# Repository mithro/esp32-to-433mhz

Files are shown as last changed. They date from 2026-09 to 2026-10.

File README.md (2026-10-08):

# esp32-to-433mhz

> [!CAUTION]
> **AI in use, use at own risk.**

A small carrier board that turns an **ESP32-C3 SuperMini** and a cheap
**433 MHz radio board** into one 29&nbsp;x&nbsp;38 mm unit. It takes any of three
common 2x4-header radios in the same socket:

* the blue **Ebyte E07-M1101D** (CC1101, SMA jack),
* the green **D-Sun CC1101** board (same signals, different header order),
* the blue **SX1278 LoRa 433MHz v4.0** breakout (Ai-Thinker Ra-02, IPEX
  antenna).

Same ESP32 pins for every radio, one firmware pin map per board, and every
track on one copper layer so it can even be etched at home.

| With the E07-M1101D (CC1101) | With the Ra-02 breakout (SX1278) |
| --- | --- |
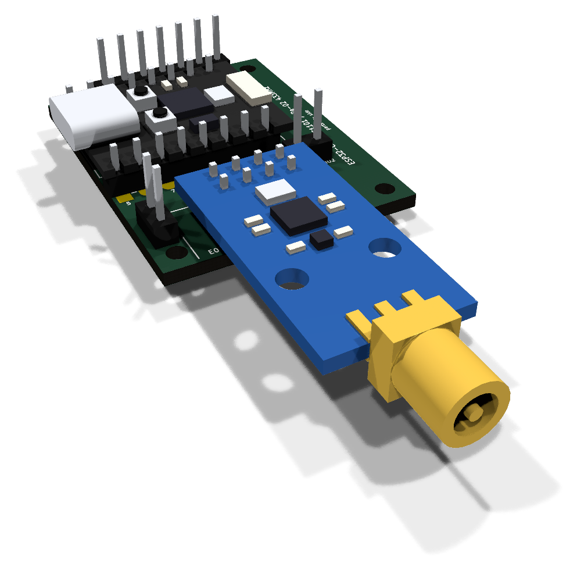
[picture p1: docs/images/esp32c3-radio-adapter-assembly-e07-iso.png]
Adapter with the E07-M1101D plugged in
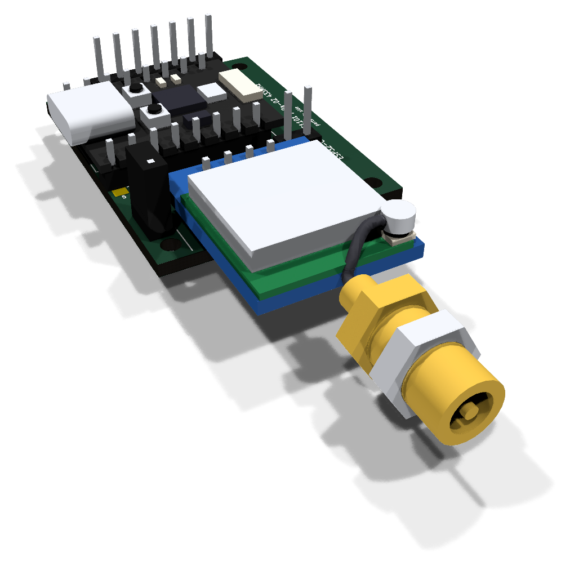
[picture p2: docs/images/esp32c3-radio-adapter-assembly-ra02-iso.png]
Adapter with the Ra-02 breakout and its U.FL-to-SMA pigtail
|  |  |

The KiCad 9 project is `hardware/esp32c3-radio-adapter`. Ready-to-upload
Gerber packages are attached to the
[latest release](https://github.com/mithro/esp32-to-433mhz/releases/latest).

Contents:

* [What you need](#what-you-need)
* [Getting the board made](#getting-the-board-made)
* [Assembling it](#assembling-it)
* [Pin map for firmware](#pin-map-for-firmware)
* [Jumper-wire version (no adapter needed)](#jumper-wire-version-no-adapter-needed)
* [Further reading](#further-reading)

## What you need

Everything is a stock AliExpress / eBay / Amazon part costing a few
dollars. The "Buy" links are AliExpress searches for the listing names;
the "Details" links go to that board's page in this repository, with its
dimensions, pinout and sources.

### Boards

| Board | Buy | How to recognise it | Details |
| --- | --- | --- | --- |
| **ESP32-C3 SuperMini** | [ESP32-C3 SuperMini](https://www.aliexpress.com/w/wholesale-esp32-c3-supermini.html) | 18&nbsp;x&nbsp;22.5 mm, USB-C, 8 castellated pins per side, ceramic antenna at the far end from the USB-C. Usually ships with two 1x8 pin headers. | [dimensions and pinout](hardware/parts/esp32-c3-supermini/) |
| **One radio board**, any of: | | | |
| Ebyte E07-M1101D-SMA (CC1101) | [E07-M1101D](https://www.aliexpress.com/w/wholesale-e07-m1101d.html), also sold as "TENSTAR CC1101 433MHz wireless module" | Blue, 15&nbsp;x&nbsp;30 mm, 2x4 header at one end, SMA jack at the other, PCB marked "E07-M1101D V2.0". Take the -SMA, not the -TH spring-antenna variant that search leads with. Needs a 433 MHz SMA antenna (often included). | [Ebyte product page](https://www.cdebyte.com/products/E07-M1101D-SMA), [part page](hardware/parts/cc1101-e07-m1101d/) |
| D-Sun CC1101 (green) | [CC1101 433MHz module](https://www.aliexpress.com/w/wholesale-cc1101-433mhz-module.html), pick the green one | Green, 14.4&nbsp;x&nbsp;30 mm, silk "433MHz D-Sun CC1101", 2x4 header, SMA jack. Needs a 433 MHz SMA antenna. | [part page](hardware/parts/cc1101-dsun/) |
| SX1278 Ra-02 breakout | [SX1278 LoRa 433MHz Ra-02](https://www.aliexpress.com/w/wholesale-sx1278-lora-433mhz-ra-02.html) | Blue 17.5&nbsp;x&nbsp;22.5 mm carrier with the Ai-Thinker Ra-02 can on top, 2x4 header underneath, silk "SX1278 LoRa 433MHz v4.0". Needs a [U.FL (IPEX) to SMA pigtail](https://www.aliexpress.com/w/wholesale-ipex-to-sma-pigtail.html) plus a 433 MHz SMA antenna. | [Ai-Thinker Ra-02 page](https://docs.ai-thinker.com/en/Ra-02/index.html), [part page](hardware/parts/sx1278-ra02-breakout/) |

Get a [433 MHz SMA antenna](https://www.aliexpress.com/w/wholesale-433mhz-sma-antenna.html),
not the 868/915 MHz one many listings bundle with the same radio.

### Headers and small parts

| Ref | Part | Qty | Notes |
| --- | --- | --- | --- |
| J1, J2 | 1x8 male pin header, 2.54 mm | 2 | For the SuperMini; usually in the bag with it. Or solder the SuperMini flat by its castellations and skip these. |
| J3 | 2x4 male pin header, 2.54 mm | 1 | The radio board's own header solders straight into the adapter. Fit a 2x4 female header instead if you want the radio removable. |
| [J4](docs/design-notes.md#expansion-header-j4) | 1x7 male pin header, 2.54 mm | 1 | Expansion header: 3V3 and the spare GPIOs. Optional. |
| [J5](docs/design-notes.md#the-dio2-fly-wire-header) | 1x2 male pin header, 2.54 mm | 1 | DIO2 fly-wire header. Only needed for raw OOK on the SX1278. |
| [JP1](docs/design-notes.md#radio-type-strap-jp1-r1) | 1x2 male pin header + jumper cap, 2.54 mm | 1 | Radio-type strap. Jumper fitted for the Ra-02, open for a CC1101. |
| R1 | 0805 0 ohm resistor | 0 or 1 | Permanent alternative to the JP1 jumper (Ra-02 only). |
| R2, R3, R4 | 0805 4.7 kOhm resistors | 0 | Do-not-populate pull-ups on the boot straps: GPIO8 and GPIO2 (on J4) and GPIO9 (unused). Only if something you add holds one of them low at boot. |
| | M2 screws or standoffs | 4 | The corner holes are 2.2 mm. |
| | Thin insulated wire, 30 to 50 mm | 1 | The DIO2 fly wire (Ra-02 only): a strand of wire-wrap or enamelled wire. |

A strip of 40-pin "breakaway" male header covers J1, J2, J4, J5 and JP1.

## Getting the board made

1. Download `esp32c3-radio-adapter-<version>-jlcpcb.zip` or
   `...-nextpcb.zip` from the
   [latest release](https://github.com/mithro/esp32-to-433mhz/releases/latest).
   Each zip is a complete Gerber + drill package for that fab, with a
   `README.txt` of the ordering options.
2. Upload the zip to [JLCPCB](https://jlcpcb.com) or
   [NextPCB](https://www.nextpcb.com) as a new PCB order.
3. Order with these options (all fab defaults, no special processes):

| Option | Value |
| --- | --- |
| Size | 29.0&nbsp;x&nbsp;38.0 mm |
| Layers | 2 |
| Thickness | 1.6 mm FR-4 |
| Copper | 1 oz |
| Finish | ENIG preferred, HASL fine |
| Solder mask / silk | any colour, silkscreen both sides |
| Castellated holes | not needed |

The packages are rebuilt by CI on every push to `main` and carry the
`git describe` version in their name; the same string is printed in the
board's title block.

**Etching it yourself.** Every track is on the bottom copper; the top has
only pads and a ground pour. So the bottom layer alone works as a
single-sided board, with two limits: the SuperMini must go on with pin
headers (laid flat it would sit on the copper side, where its pin rows
come out mirrored), and R1 sits on the copper side. Use the `.GBL`,
`.GBO` and `.DRL` files from the package.

## Assembling it

1. **Radio-type strap first.** For the Ra-02 breakout, fit JP1 and put a
   jumper on it (or solder a 0 ohm resistor in R1 on the bottom). For
   either CC1101 board, leave JP1 empty or open.
2. **SuperMini.** It lies on its side along the left edge, USB-C hanging
   off the board; the silk shows the outline and pin names. Either solder
   its two 1x8 headers through the 1.0 mm holes (long pins down through
   the adapter, the plastic body between the two boards), or lay it flat
   on the top side and solder the castellations to the extended pads.
3. **J4, J5.** Optional; solder them from the top so the pins stand up.
   The silk under J4 names the pins the way the SuperMini does; J5's pins
   are "21" and "20 DIO2".
4. **Radio board.** It plugs in component side up, hanging off the bottom
   edge with its antenna connector pointing away from the adapter. Pin 1
   (GND) is the square pad at the right of the outer row. Solder its
   header pins into the 2x4 holes, or into a female socket fitted there.
5. **DIO2 fly wire (Ra-02, raw OOK only).** Run a wire from the
   breakout's DIO2 land to J5 pin 2 (GPIO20). DIO2 is not on the 2x4
   header: it is the Ra-02 module's pin 7, whose land sticks 0.8 mm out
   past the module's edge on the right-hand side, about 9 mm down from the
   header edge. The pinout diagram below marks it, and
   [Adding the DIO2 wire](hardware/parts/sx1278-ra02-breakout/dio2-wire.md)
   shows the radio end and how to check it landed.
6. **Antenna.** Screw it on the E07 or D-Sun's SMA jack; for the Ra-02,
   clip the pigtail's U.FL plug onto the module and screw the antenna on
   the pigtail. The DIO2 wire and the pigtail both want strain relief:
   a dab of hot glue over the wire's solder joint is enough.

| Top | Bottom (all the tracks) |
| --- | --- |
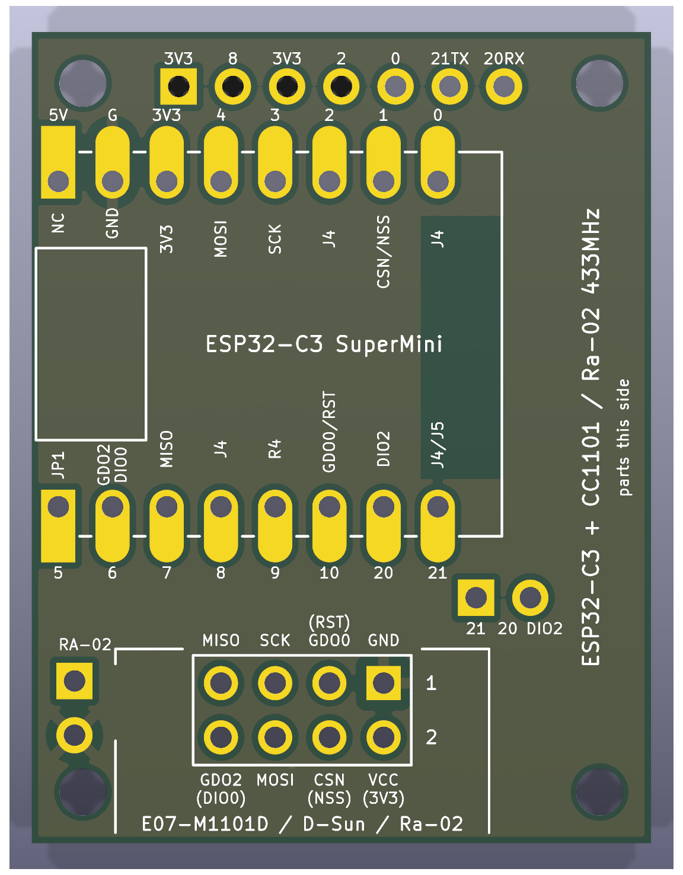
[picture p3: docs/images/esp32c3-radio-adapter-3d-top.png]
3D render of the top side
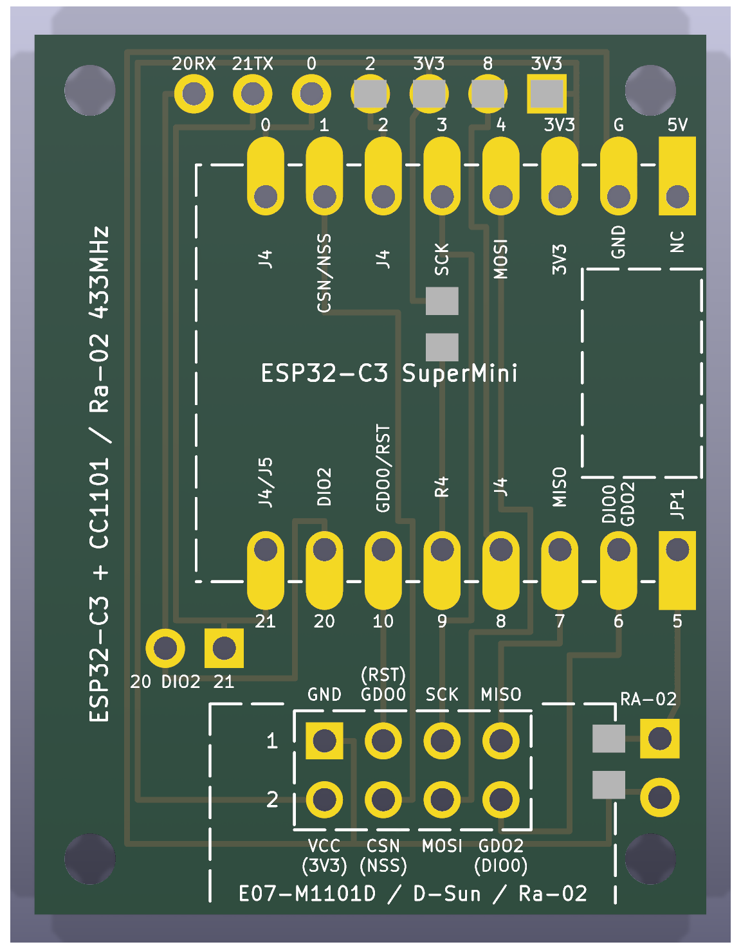
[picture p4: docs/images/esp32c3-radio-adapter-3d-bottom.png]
3D render of the bottom side
|  |  |

The silkscreen outlines the two mechanical keep-outs, the footprints of the
SuperMini and of the plugged-in radio board. J5 sits in the band between
them and is the only thing that fits there.

## Pin map for firmware

The socket's eight positions go to fixed GPIOs. Which signal each carries
depends on the radio, so firmware needs one pin map per board:

| Socket position | ESP32-C3 GPIO | E07-M1101D (blue CC1101) | D-Sun (green CC1101) | Ra-02 breakout (SX1278) |
| --- | --- | --- | --- | --- |
| 1 | GND | GND | GND | GND |
| 2 | 3V3 | VCC | VCC | 3V3 |
| 3 | GPIO10 | GDO0 (radio out) | MOSI | RST (radio in) |
| 4 | GPIO1 | CSN | SCK | NSS |
| 5 | GPIO3 | SCK | MISO (radio out) | SCK |
| 6 | GPIO4 | MOSI | GDO2 (radio out) | MOSI |
| 7 | GPIO7 | MISO (radio out) | GDO0 (radio out) | MISO (radio out) |
| 8 | GPIO6 | GDO2 (radio out) | CSN | DIO0 (radio out) |
| J5 pin 2 | GPIO20 | | | DIO2/DATA (fly wire) |
| JP1 / R1 | GPIO5 | open | open | strapped to GND |

The same maps, signal first:

| Signal | E07-M1101D | D-Sun | Ra-02 |
| --- | --- | --- | --- |
| MOSI | GPIO4 | GPIO10 | GPIO4 |
| MISO | GPIO7 | GPIO3 | GPIO7 |
| SCK | GPIO3 | GPIO1 | GPIO3 |
| CSN / NSS | GPIO1 | GPIO6 | GPIO1 |
| GDO0 / DIO0 | GPIO10 | GPIO7 | GPIO6 |
| GDO2 | GPIO6 | GPIO4 | |
| RST | | | GPIO10 |
| DIO2/DATA | | | GPIO20 |

**Telling the boards apart.** GPIO5 is the radio-type strap. Read it with
the internal pull-up enabled: low means the Ra-02 (jumper fitted), high
means a CC1101 board. The three-state read that also covers the SX1278
module adapter is in the
[design notes](docs/design-notes.md#radio-type-strap-jp1-r1). The two
CC1101 boards are told apart without driving anything: an unconfigured CC1101 clocks about 135 kHz out of GDO0, so
whichever of GPIO10 (blue board) and GPIO7 (green board) is toggling at
power-up names the board. In the jumper-wire build the strap goes to GPIO0
instead of GND, so drive GPIO0 low as an output before reading GPIO5.

**Why DIO2 matters on the SX1278.** In its continuous mode the raw
demodulated bitstream is available only on the DIO2/DATA pin. Packet mode
carries only what the packet handler can frame, which suits Fineoffset
weather stations but not the OOK remotes this node exists to hear and key.
The Ra-02 breakout leaves DIO2 unconnected, hence the fly wire to GPIO20.

**Never put a radio pin on GPIO2, GPIO8 or GPIO9.** They are ESP32-C3 boot
straps; a radio pin's capacitance makes the strap rise too slowly at reset
and the chip drops into USB download mode instead of running. This was
measured on the bench and later confirmed over JTAG -- on an affected board
the GPIO_STRAP_REG latch reads the download pattern even though the live
GPIO9 reads high -- and is not fixable in software, which is why the socket
uses GPIO1 rather than GPIO9.

## Jumper-wire version (no adapter needed)

The same hook-up with Dupont jumper wires, so the firmware pin map is
identical and you can test everything before ordering boards. Plug the
female-to-female wires onto the SuperMini's headers and the radio board's
2x4 header. Both boards are drawn from the back, pins towards you.

| Wire | SuperMini pin | E07-M1101D | D-Sun | Ra-02 |
| --- | --- | --- | --- | --- |
| brown | G | GND | GND | GND |
| red | 3V3 | VCC | VCC | 3V3 |
| grey | GPIO10 | GDO0 | MOSI | RST |
| purple | GPIO1 | CSN | SCK | NSS |
| blue | GPIO3 | SCK | MISO | SCK |
| white | GPIO4 | MOSI | GDO2 | MOSI |
| green | GPIO7 | MISO | GDO0 | MISO |
| yellow | GPIO6 | GDO2 | CSN | DIO0 |
| orange | GPIO5 | not fitted | not fitted | to the SuperMini's GPIO0 (radio-type strap) |
| black | GPIO20 | | | DIO2, soldered to the module's pin-7 land |

Jumper wires from the SuperMini to the blue CC1101 E07-M1101D board

Jumper wires from the SuperMini to the green D-Sun CC1101 board

Jumper wires from the SuperMini to the Ra-02 breakout

The Ra-02's orange strap wire goes to GPIO0 rather than GND because the
SuperMini's only GND pin is taken by the brown wire; the firmware drives
GPIO0 low while it reads the strap. The black DIO2 wire has no header pin
at the radio end: solder it to the module's pin-7 castellation or the land
just outside it, on the face away from the header pins. The header
pinouts, with the DIO2 land marked on both faces:

Header pinouts of the radio boards, front and back

## Printing a case

A two-part case that fits the adapter with either radio is in
`hardware/case/` as STL files. Every
[release](https://github.com/mithro/esp32-to-433mhz/releases/latest)
carries it as `esp32c3-radio-adapter-case-<version>.zip`, plus the two
`.stl` files loose for dropping straight into a slicer. The zip holds the
STL files in print orientation, the case's STEP models, and a README.txt
with the parts' sizes, home FDM print settings and how to order them from
JLCPCB's 3D-printing service.
In the pictures and the notes below, the **front** is the antenna end,
the **back** the SuperMini end with the pry notch on the seam, and the
**left** wall the one with the USB-C window. The top half is the darker
shade.

Closed, with the E07-M1101D inside (its SMA jack through the front wall):

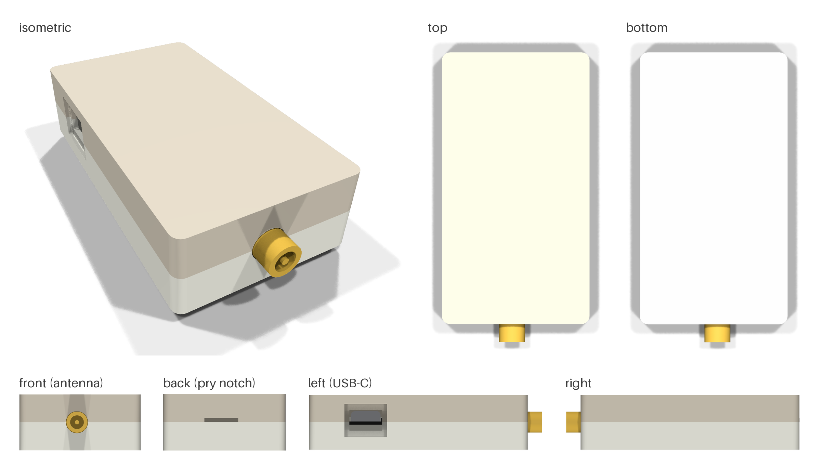
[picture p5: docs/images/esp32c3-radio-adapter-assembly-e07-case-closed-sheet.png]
The closed case with the E07-M1101D: isometric, top, bottom, front (antenna), back (pry notch), left (USB-C) and right views


Open, the adapter pressed onto the pegs in the bottom half, with the Ra-02
breakout and its U.FL-to-SMA pigtail in the socket (the drawn pigtail runs
straight to the bulkhead; a real one is longer, with the excess lying
beside the breakout):

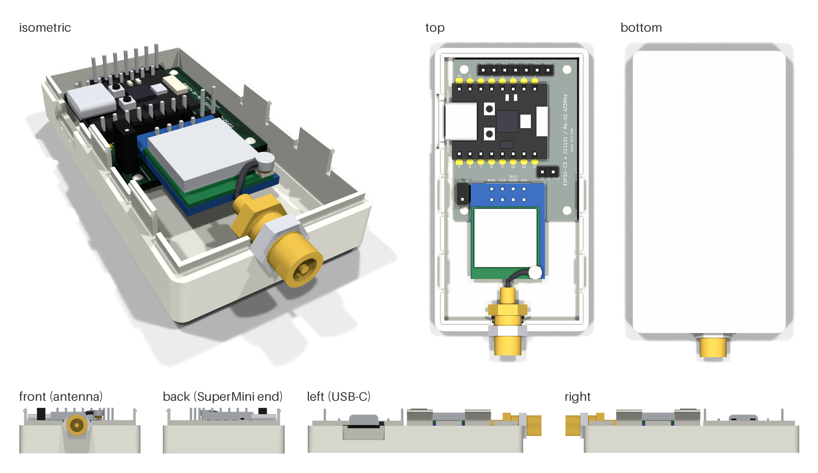
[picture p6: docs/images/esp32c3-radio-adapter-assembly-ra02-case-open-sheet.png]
The bottom half of the case with the adapter and the Ra-02 breakout: isometric, top, bottom, front (antenna), back (SuperMini end), left (USB-C) and right views


The halves on their own, and the slotted top:

| Bottom half: pegs, lip and the four snap tabs | Top half from below: bosses, grooved skirt, USB-C window, antenna hole | The slotted top half closed over the E07 |
| --- | --- | --- |
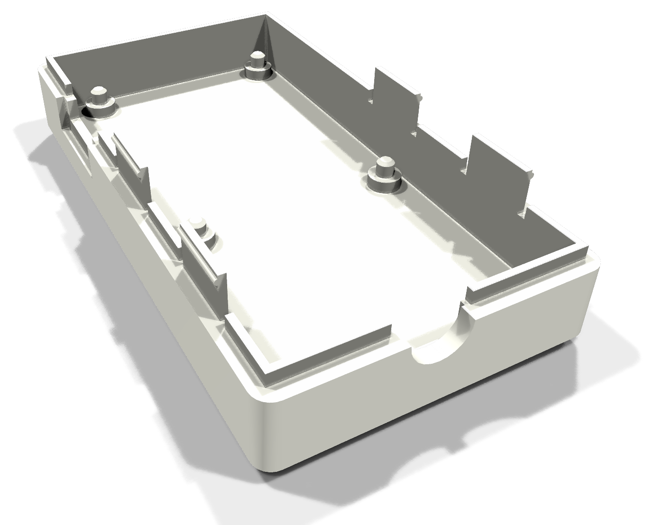
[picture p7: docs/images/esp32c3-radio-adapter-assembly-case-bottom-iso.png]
The empty bottom half from above: the four pegged standoffs, the lip round the rim and the four snap tabs with their bumps
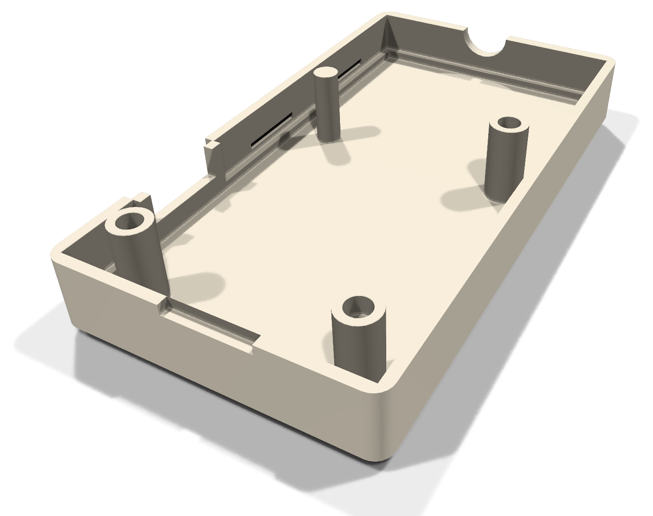
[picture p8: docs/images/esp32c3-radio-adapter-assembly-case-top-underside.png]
The top half turned over: three bored bosses and one solid one, the rebated skirt with its four grooves, the USB-C window and the antenna hole with its square pocket
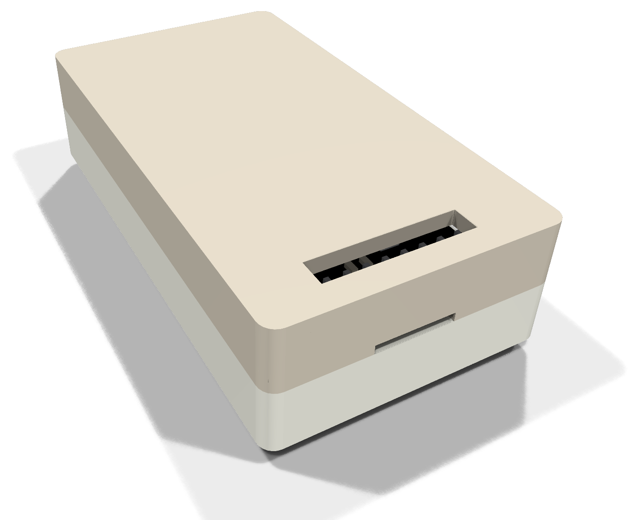
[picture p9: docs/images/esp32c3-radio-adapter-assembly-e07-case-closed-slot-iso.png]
The closed case with the slotted top half: J4's pins reach up through the slot in the ceiling
|  |  |  |

The same views with the other radio (the Ra-02 closed, the E07-M1101D
open) and the exploded views are in
[3D models and case design](docs/3d-models.md#the-printed-case).

* Two halves that snap together: `esp32c3-radio-adapter-case-bottom.stl`
  and `esp32c3-radio-adapter-case-top.stl`, each printed open side up. No
  supports, no screws; 2.2 mm walls; 36.2&nbsp;x&nbsp;66.7&nbsp;x&nbsp;16.7 mm
  outside. Trim every pin under the board to about 1 mm first: the floor
  counts on it.
* The board presses onto four 2.15 mm pegs in the bottom half (they fit
  the 2.2 mm M2 corner holes), and bosses in the top half hold it there
  once the case is shut. The SuperMini can be on its headers or soldered
  flat by its castellations.
* The seam runs through the connectors: the antenna hole and the USB-C
  window are half in each half, so the connectors lie in the bottom half's
  cut-outs and the top closes over them. One 6.6 mm hole in the front wall
  serves both radios: the E07-M1101D's SMA jack pokes through it, and the
  Ra-02's U.FL-to-SMA pigtail bulkhead is clamped in it by its nut, with
  the spare cable stowed beside the breakout.
* Four snap tabs on the bottom half click into grooves in the top half's
  skirt; the notch at the seam on the back takes a fingernail to open it.
  It is not water-tight and does not try to be.
* `esp32c3-radio-adapter-case-top-slot.stl` is the same top half with a
  slot over the spare-GPIO header J4, for jumper wires out of the closed
  case; print it instead of the plain top if you want that.
* The package's README.txt has the print settings, what to inspect (the
  0.8 mm snap tabs, the peg fit, which depends on the printer's
  calibration) and the material to pick at a service.

The case is generated from the same dimensions as the boards by
`scripts/build_case.py`; see [3D models and case design](docs/3d-models.md#the-printed-case).
Dimensioned drawings of both halves, with a checklist of caliper
measurements for a printed part, are in [Case drawings](docs/case-drawings.md).

## Further reading

* [Design notes](docs/design-notes.md): why the GPIOs are what they are,
  how everything routes on one layer, the expansion header J4, the DIO2
  header J5, the mechanical keep-outs and the radio-type strap.
* [Component boards](hardware/parts/): a page per board -- the SuperMini
  and each radio -- with its dimensions, pinout, where to buy it and the
  KiCad reproduction its footprints were checked against.
* [3D models and case design](docs/3d-models.md): STEP/GLB assemblies on
  every release, the dimensions a case needs, and the printed case.
* [SX1278 castellated module adapter](docs/sx1278-module-adapter.md): a
  second, two-layer carrier for the solder-down 16-pin SX1278 module,
  `hardware/esp32c3-sx1278-adapter`.
* [Development](docs/development.md): regenerating the KiCad projects
  from the scripts, running ERC/DRC, and how CI builds the release
  packages.

Not part of this repository, but worth a look before writing firmware from
scratch:
[OpenMQTTGateway's RF gateway](https://docs.openmqttgateway.com/use/rf.html#what-is-an-rf-gateway)
is ESP32 firmware that bridges 433&nbsp;MHz to MQTT and already supports both
radio families this adapter takes: CC1101 boards and SX127x modules. It
offers four receiver flavours -- RCSwitch, Pilight and RF2 receive and
transmit, RTL_433 receives only but knows the most devices. Its documented
ESP32 + CC1101 builds are named as whole boards (Heltec WiFi LoRa 32,
LilyGo LoRa 32, ESP32 DOIT DevKit, Ai-Thinker R01) rather than as a pin
map, so this adapter's GPIOs would have to be mapped onto it, and the
SX1278's DIO2 fly wire has no obvious counterpart there. **Nothing here has
been tried against it yet** -- this is a lead to follow, not a tested route.

## Licence

Apache License 2.0, see `LICENSE`.

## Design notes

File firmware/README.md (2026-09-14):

# Firmware build (Plan B)

Tasmota **v15.5.0** + our overlay (driver `xdrv_95_cc1101.ino`, `tasmota/cc1101_node/`, config/env files). Nothing upstream is edited — see `build.py`'s `assert_upstream_clean()`, which refuses to build if the Tasmota checkout has any tracked-file change outside the overlay's own additions.

    uv tool install platformio                 # once
    uv run firmware/build.py

First run clones Tasmota into `firmware/build/Tasmota/` (git-ignored) and PlatformIO downloads the
ESP32 platform (~1 GB). Artefacts land in `firmware/dist/`:

| File | Use |
|---|---|
| `tasmota32c3-cc1101.factory.bin` | first flash, at offset `0x0`, over native USB. **Already includes a safeboot image** in the factory slot (Tasmota's build fetches `tasmota32c3-safeboot.bin` from ota.tasmota.com at build time and merges it), so button-free WiFi recovery from a failed OTA already works with this image. See `RECOVERY.md`. |
| `tasmota32c3-cc1101-combined.factory.bin` | same as above **but with our own pinned safeboot** in the factory slot instead of the fetched-release one — reproducible, offline-buildable, source-audited from the same pinned Tasmota SHA. Boot-safety/reproducibility improvement, not a new recovery path. Built by `tools/combine_safeboot.py`. |
| `tasmota32c3-cc1101.bin` | later updates, uploaded through the Tasmota web UI (Firmware Upgrade) |
| `tasmota32c3-cc1101.elf` / `.map` | debugging (symbols, section sizes) |
| `build-info.json` / `build-info-<env>.json` | Tasmota tag/SHA, build timestamp, artefact sizes (per built env) |

To produce the pinned-safeboot combined image, build both envs then merge:
`python3 build.py` (main) → `python3 build.py --env tasmota32c3-safeboot` → `python3 tools/combine_safeboot.py`.

`build.py --overlay-only` just refreshes the copied-in overlay files without compiling;
`build.py --clean` wipes the PlatformIO `.pio/build` dir first (use after changing build flags,
not needed for ordinary `.ino`/decoder edits).

## First flash (native USB, factory image)

The ESP32-C3 SuperMini's USB-C port is native USB (no separate USB-serial chip). To reach the
ROM download mode the first time (board is blank or running something else):

1. Hold the **BOOT** button (GPIO9).
2. Plug the USB-C cable in (or press RESET) while still holding BOOT, then release.
3. The board enumerates as `303a:1001`. On the deployment host a udev rule symlinks it to
   a stable `/dev/radio-cc1101-node-<serial>` name (see `docs/esp32c3-cc1101-node.md` for the
   USB mapping story).
4. Flash a **factory** image at offset `0x0` (bootloader + partition table + safeboot + main app —
   the only image that works on a blank/foreign chip). Either `tasmota32c3-cc1101.factory.bin`
   (fetched-release safeboot) or, preferred for a reproducible pinned safeboot,
   `tasmota32c3-cc1101-combined.factory.bin`:

       esptool.py --chip esp32c3 --port /dev/radio-cc1101-node-<serial> write_flash 0x0 \
           firmware/dist/tasmota32c3-cc1101-combined.factory.bin

5. Reset (unplug/replug, no BOOT held this time) and it boots into Tasmota's captive-portal WiFi
   setup (`tasmota-XXXX` AP) or the console over the same USB-CDC port at 115200 baud.

If reflashing a board that is already running our firmware (BOOT-button access is always there —
see `RECOVERY.md`), the factory image still works and is the simplest path; it just re-lays the
whole flash including settings, so back up `/cc1101.cfg` first if you care about the persisted
Security+ id/counter (§ below).

## Later updates (OTA / web UI)

`OTA_URL` is intentionally blanked in `overlay/user_config_override.h` — the stock Tasmota
`Upgrade`/`OtaUrl` commands would otherwise pull a **generic** `tasmota32c3` image from
`ota.tasmota.com` and silently drop this driver. Updates are manual instead:

1. Web UI → **Firmware Upgrade** → **Upload** → pick `tasmota32c3-cc1101.bin` (not the
   `.factory.bin`, which duplicates the bootloader/partition table already on the device) → Start.
2. Or `curl -F file=@tasmota32c3-cc1101.bin http://<node-ip>/u2` (Tasmota's upload endpoint).

Either path keeps NVS settings (WiFi, `/cc1101.cfg`, etc.) intact.

## Commissioning a node

See `docs/esp32c3-cc1101-node.md` → *Runbooks → Commission a node* for the full
sequence (template + `Module 0`, `Hostname`/`Topic`, `MqttHost`, `CcMode`, verification). Summary
of the parts specific to this driver:

- Template — apply this **raw template** then `Module 0` (verified on real ESP32-C3 hardware, 2026-08-24):
  ```
  Template {"NAME":"CC1101node","GPIO":[0,0,0,4544,736,672,704,768,0,0,4576,0,0,0,0,0,0,0,0,0,0,0],"FLAG":0,"BASE":1}
  Module 0
  ```
  This assigns GPIO3=`CC1101 GDO0`, GPIO4=`SPI CLK`, GPIO5=`SPI MISO`, GPIO6=`SPI MOSI`, GPIO7=`SPI CS`, GPIO10=`CC1101 GDO2`. **Do not** use the per-pin `GPIO3 CC1101 GDO0` command or the web dropdown for the GDO pins: the `CC1101 GDO0`/`GDO2` template functions are gated behind `#ifdef USE_KEELOQ` upstream, and this build `#undef`s `USE_KEELOQ` (its KeeLoq driver claims the same pins), so those functions are not offered/accepted interactively — only the raw `Template` array assigns them. The CS line is plain `SPI CS` (not a `CC1101 CS` function) — the driver reuses Tasmota's stock `GPIO_SPI_CS`/`USE_SPI` plumbing (ruling R5; see the spec §3.2 note).
- `CcMode weather|remotes` picks the node's role (persisted to `/cc1101.cfg`); a CC1101 cannot do FSK and OOK at once.
- `CcStatus` after commissioning should show `"Present":1`, `"PARTNUM":"0x00"`, `"VERSION":"0x14"`.

## Radio selection and SX1278 (RA-02) support

This build drives **two** radio families over the shared SPI bus and chooses one at boot.

- **`Radio auto|cc1101|sx1278`** (persisted to `/cc1101.cfg`) selects the radio. `auto` reads the
  **GPIO5 board-type strap**, sampled with an internal pulldown then an internal pullup: a
  *floating* pin (reads 0 then 1) means a **CC1101** board; a pin *tied low* (reads 0 both times)
  means an **SX1278 (RA-02)** board.
- For **CC1101**, bring-up **SPI-probes** the known per-board pin maps and keeps whichever answers
  with `PARTNUM 0x00` and `VERSION` in `{0x04, 0x14}`. For **SX1278**, bring-up uses the RA-02 map
  and confirms `RegVersion (0x42) == 0x12`.

Verified per-board pin maps (ESP32-C3 GPIO numbers):

| Board | SCK | MOSI | MISO | CS/NSS | GDO0/RST | GDO2/DIO0 |
|---|---|---|---|---|---|---|
| CC1101 blue (E07) | 3 | 4 | 7 | 9 | GDO0 = 10 | GDO2 = 6 |
| CC1101 green (D-Sun) | 9 | 10 | 3 | 6 | GDO0 = 7 | GDO2 = 4 |
| SX1278 RA-02 | 3 | 4 | 7 | NSS = 9 | RST = 10 | DIO0 = 6 |

> The legacy Tasmota template map (GPIO4 = CLK, 5 = MISO, 6 = MOSI, 7 = CS, 3 = GDO0, 10 = GDO2)
> is also probed first when that template is commissioned, so previously-templated CC1101 nodes
> keep working.

**Capability parity (not identical, by hardware constraint):** both radios do
Fine Offset FSK RX (WS69/WH65B/WS85/WH51) through the same decoder. The SX1278
**does** do raw 2-FSK TX via `SxFskTx` (see the command table below). It does
**not** do OOK-PWM remote RX, Security+ 2.0, or OOK TX — OOK-continuous RX needs
the SX127x **DIO2/DATA** pin, which this RA-02 adapter does not route. See
`docs/esp32c3-cc1101-node.md` -> *Radio
capability matrix* for the full table (including live-hardware status per radio)
and `src/cc1101_node/sx1278_radio.cpp` for the SX1278's staged roadmap
(FSK-RX -> FSK-TX -> OOK-RX -> OOK-TX -> LoRa).

SX1278 / selection commands (over MQTT and the USB/web console, like the `Cc*` commands):

| Command | Syntax | Example | Response |
|---|---|---|---|
| `Radio` | `Radio [auto\|cc1101\|sx1278]` | `Radio sx1278` | `{"Radio":{"Config":"sx1278","Active":"sx1278"}}` (setting it re-runs bring-up) |
| `SxStatus` | `SxStatus` | `SxStatus` | `{"SxStatus":{"Present":1,"VERSION":"0x12","Active":1}}` |
| `SxReg` | `SxReg <addr 0x00-0x7F> [val]` (SX1278 must be the active radio) | `SxReg 0x42` | `{"SxReg":{"Addr":"0x42","Value":"0x12"}}` (value read back after any write) |
| `SxReset` | `SxReset` | `SxReset` | `{"SxReset":{"Present":1,"VERSION":"0x12"}}` (pulses RST, then re-identifies) |
| `SxFskTx` | `SxFskTx <hex>` — transmit a raw 2-FSK packet (SX1278 must be the active radio); used to cross-check the FSK weather decode against the Pluto/rpi5 receivers | `SxFskTx 0x51AABBCC` | `{"SxFskTx":{"Sent":1,"Bytes":4}}` |
| `SxTxPower` | `SxTxPower [2..17]` dBm — SX1278 PA_BOOST output power (`0` = default +17 dBm). Persisted to `/cc1101.cfg`. | `SxTxPower 10` | `{"SxTxPower":{"dBm":10,"PaConfig":"0x88"}}` |
| `SxRxGain` | `SxRxGain [1..6]` — SX1278 LNA gain (`1` = max G1 … `6` = min G6; `0` = AGC-auto default). Persisted. | `SxRxGain 1` | `{"SxRxGain":{"Lna":"0x20","Auto":0}}` |

## Command reference

All commands work identically over MQTT (`cmnd/<topic>/<Command> <payload>` → response on
`stat/<topic>/RESULT`) and the USB/web console. Examples below show the console form (bare
command + argument) and the JSON the driver responds with.

| Command | Syntax | Example | Response |
|---|---|---|---|
| `CcMode` | `CcMode [remotes\|weather]` | `CcMode weather` | `"weather"` (plain string; `auto` is accepted syntactically but replies `"auto not implemented (spec follow-on)"` and does not change mode — spec §5.3 follow-on) |
| `CcPreset` | `CcPreset [name]` (debug: loads a preset and enters RX with it, overriding `CcMode` until the next `CcMode`/reinit) | `CcPreset fineoffset-fsk` | `"fineoffset-fsk"`; unknown name or no radio present → `"fineoffset-fsk\|ook-433\|ook-tx-100k\|ook-tx-4k"` |
| `CcReg` | `CcReg <addr 0x00-0x3F> [val]` (hex or decimal); writing `addr` in `0x30-0x3D` issues a command **strobe** instead of a register write | `CcReg 0x02 0x0D` | `{"CcReg":{"Addr":"0x02","Value":"0x0D"}}` (`Value` is always read back after any write); no args / no radio → `"addr 0x00-0x3F [val]"` |
| `CcStatus` | `CcStatus` | `CcStatus` | `{"CcStatus":{"Present":1,"PARTNUM":"0x00","VERSION":"0x14","MARCSTATE":"0x0D","Mode":"remotes","Preset":"ook-433","RSSI":-84,"Rx":1234,"Decoded":412,"Tx":3,"Reinit":0,"Overflow":0,"Repeats":57,"Raw":0,"Hass":0,"HassDisc":1,"SecplusId":0,"Rolling":0}}` |
| `CcRaw` | `CcRaw <0\|1>` | `CcRaw 1` | `1` (plain number; then every captured OOK frame also publishes `tele/<topic>/CCRAW`, and every undecoded FSK packet too — see MQTT topics below) |
| `CcHass` | `CcHass [0\|1]` — decoded-events topic layout: `0` (default) `rtl_433/nodes/<host>/events` (aggregator-fronted); `1` `rtl_433/<host>/events` (matches the HA add-on's `rtl_433/+/events` for direct autodiscovery). Persisted to `/cc1101.cfg`. | `CcHass 1` | `{"CcHass":1,"EventsTopic":"rtl_433/cc1101-welland-carport/events"}` — see [`docs/mqtt-home-assistant.md`](docs/mqtt-home-assistant.md) |
| `CcHassDisc` | `CcHassDisc [0\|1]` — native Home Assistant MQTT **discovery**: publish `homeassistant/sensor/<model>-<id>/.../config` for each decoded sensor so HA auto-creates entities (`1` = on, default; `0` = off). Distinct from `CcHass` (which only sets the events-topic layout). Persisted to `/cc1101.cfg`. | `CcHassDisc 1` | `{"CcHassDisc":1}` — see [`docs/mqtt-home-assistant.md`](docs/mqtt-home-assistant.md) |
| `CcTxPower` | `CcTxPower [byte]` — CC1101 OOK mark level `PATABLE[1]` (`0` = preset default; e.g. `0xC0` ≈ +10 dBm @433). Persisted to `/cc1101.cfg`. | `CcTxPower 0xC0` | `{"CcTxPower":"0xC0"}` |
| `CcRxGain` | `CcRxGain [byte]` — CC1101 `AGCCTRL2` (0x1B) override (`0` = preset default; lower MAX_LNA/DVGA = less gain). Persisted. | `CcRxGain 0x03` | `{"CcRxGain":"0x03"}` |
| `CcRfSend` | `CcRfSend {"Data":"0x..","Bits":8-32,"Protocol":1,"Pulse":100-2000,"Repeat":n}` (or a bare decimal/hex `Data` value using the defaults `Bits:24 Protocol:1 Pulse:350 Repeat:10`) — named `CcRfSend`, **not** `RfSend`: see note below | `CcRfSend {"Data":"0x00AABB","Bits":24,"Pulse":350,"Repeat":5}` | `"Done"` / `"Failed"` / `"no radio"` / `"rate limited"` / `"only Protocol 1, Bits 8..32, Pulse 100..2000"`; before transmitting it announces on `rtl_433/nodes/<host>/tx` (see below) |
| `SecplusId` | `SecplusId [id]` (36-bit id, masked to `0xF0FFFFFFFF`) | `SecplusId 12345` | `{"SecplusId":12345}` |
| `SecplusCounter` | `SecplusCounter [n]` (28-bit rolling counter, masked to `0x0FFFFFFF`) | `SecplusCounter` | `0` (plain number; normally left alone — `SecplusSend` increments and persists it itself) |
| `SecplusFreq` | `SecplusFreq [MHz[,MHz[,MHz]]]` (up to 3 legs; each is parsed as a float and kept only if it falls in `(300,1000)`; parsing stops at the first unparseable token, so leading valid legs are accepted and a trailing junk token is dropped; if no leg parses at all, the stored value is left unchanged) | `SecplusFreq 433.30,433.92,434.54` | `{"SecplusFreq":[433.30,433.92,434.54]}`; default (no config yet) is a single leg, `{"SecplusFreq":[433.92]}` |
| `SecplusSend` | `SecplusSend <button 0-15>` | `SecplusSend 1` | `"Done"` / `"Failed"` / `"no radio"` / `"set SecplusId first"` (no `SecplusId` configured yet) / `"rate limited"`; announces on `rtl_433/nodes/<host>/tx`, persists the incremented rolling counter **before** keying the radio (never re-uses a counter value even if the transmit itself fails), then transmits on each configured `SecplusFreq` leg in turn |

Notes:

- **Why `CcRfSend` and not `RfSend`:** this build also compiles in Tasmota's stock `xdrv_17_rcswitch.ino` (`USE_RC_SWITCH`), which already owns the `RfSend`/`CmndRfSend` name — defining another `RfSend` would collide at link time. `CcRfSend` is the CC1101 node's equivalent (same `{"Data":..,"Bits":..,"Protocol":..,"Pulse":..}` shape as the Sonoff-bridge-compatible command described in the design spec's §5.5, just under a different name).
- All `Cc*`/`Secplus*` commands are rate-limited together: at most 10 transmits per rolling 10 s window (`CcTxAllowed()`); once the limit is hit, further transmit commands return `"rate limited"` until the window rolls over.
- `CcReg`/`CcPreset` are debugging aids (mirroring `tools/cc1101.py`), not part of normal commissioning.

## MQTT topics

For the full per-field JSON schema of every device, the Home Assistant
autodiscovery setup, and the live-broker validation procedure (validated
2026-09-09 on the real `ha.welland.mithis.com` broker — see the doc),
see [`docs/mqtt-home-assistant.md`](docs/mqtt-home-assistant.md).

| Direction | Topic | Example payload |
|---|---|---|
| decoded events (per receiver) | `rtl_433/nodes/<host>/events` (`CcHass 0`, default) or `rtl_433/<host>/events` (`CcHass 1`, direct HA autodiscovery) | OOK-PWM: `{"time":"2026-08-24T10:15:03","receiver":"cc1101-welland-carport","rssi":-61,"model":"OOK-PWM",...}` (decoder-specific fields follow `rssi`); Security+: `{"time":"...","receiver":"...","rssi":-70,"model":"Secplus-v2","id":12345,"button":1,"rolling":842}`; Fineoffset weather in `weather` mode: `{"time":"...","receiver":"...","rssi":-84,"model":"Fineoffset-WS69","id":174,"temperature_C":13.1,"humidity":82,...}` |
| Tasmota-style remote result (per receiver) | `tele/<topic>/RESULT` | `{"RfReceived":{"Data":"0x00AABB","Bits":25,"Protocol":1,"Pulse":350,"RSSI":-61}}` — published only for the OOK-PWM (`remotes`-mode) decode path, alongside the `events` publish for the same frame |
| raw capture (bench, `CcRaw 1`) | `tele/<topic>/CCRAW` | OOK: `{"Pulses":[350,-1050,700,-700,...]}` (positive = mark, negative = space, in µs); FSK undecoded packet: `{"Packet":"24AE5D8213...","RSSI":-84,"LQI":37}` |
| TX announcement (before keying, ~50 ms lead) | `rtl_433/nodes/<host>/tx` | `CcRfSend`: `{"Data":"0x00AABB","Bits":24,"Protocol":1,"Pulse":350,"model":"OOK-PWM","code":"00aabb"}`; `SecplusSend`: `{"model":"Secplus-v2","id":12345,"button":1,"rolling":843,"fixed":...}` |
| Tasmota teleperiod status | `tele/<topic>/SENSOR` | `...,"CC1101":{"Mode":"remotes","Preset":"ook-433","RSSI":-84,"Rx":1234,"Decoded":412,"Tx":3,"Reinit":0,"SecplusId":12345,"Rolling":843}` (appended to Tasmota's normal `SENSOR` payload via `FUNC_JSON_APPEND`, on the standard `TelePeriod`) |
| commands | `cmnd/<topic>/<Command> <payload>` → `stat/<topic>/RESULT` | see Command reference above |

**`<host>` vs `<topic>` — these are two different Tasmota settings and must both be set at
commissioning time:** `rtl_433/nodes/<host>/...` uses Tasmota's **`Hostname`**
(`NetworkHostname()`); `tele/<topic>/...` and `cmnd/<topic>/...` use Tasmota's **`Topic`**. The
commissioning runbook sets both to the same `cc1101-<site>-<place>` value, but nothing in the
firmware enforces that — if they diverge, the `rtl_433/nodes/...` name and the `tele/...` name for
the same node will not match, which will confuse the aggregator's per-node bookkeeping.

## `/cc1101.cfg` — persisted config

Stored on the Tasmota LittleFS filesystem (`USE_UFILESYS`) as a fixed-size binary struct, loaded
at boot and re-saved whenever a setting changes:

| Field | Type | Meaning |
|---|---|---|
| `magic` | `uint32_t` | `0xCC110101` — file-format sentinel; a file that doesn't match this (or isn't exactly `sizeof(CcConfig)` bytes) is ignored and defaults are used instead (`CcCfgLoad()` requires an exact-size match to avoid reading stack garbage from a truncated file) |
| `version` | `uint8_t` | config struct version, currently `1` |
| `mode` | `uint8_t` | `0` = `remotes`, `1` = `weather` (`CcMode`) |
| `raw` | `uint8_t` | `CcRaw` flag (0/1) |
| `hass` | `uint8_t` | `CcHass` events-topic layout: `0` = `rtl_433/nodes/<host>/events` (aggregator), `1` = `rtl_433/<host>/events` (direct HA). Carved from the trailing reserved padding, so `sizeof(CcConfig)` is unchanged and pre-existing config files load with `hass = 0` (no version bump) |
| `secplus_id` | `uint64_t` | this node's Security+ 2.0 transmitter identity (`SecplusId`), masked to 36 bits |
| `rolling` | `uint32_t` | Security+ rolling counter (`SecplusCounter`), masked to 28 bits |
| `tx_count` | `uint32_t` | lifetime transmit count (mirrors `CcStatus`'s `Tx`, but persisted) |
| `secplus_freq[3]` | `double[3]` | configured Security+ TX frequency legs, MHz (`SecplusFreq`) |
| `secplus_nfreq` | `uint8_t` | how many of `secplus_freq[0..2]` are in use (default `1`, `secplus_freq[0] = 433.92`) |

Defaults (`CcCfgDefaults()`): `mode = remotes`, `raw = 0`, `hass = 0`, `secplus_id = 0`, `rolling = 0`,
`secplus_freq = [433.92, 0, 0]`, `secplus_nfreq = 1`. See `RECOVERY.md` for restoring/backing up
this file.

## Host tests

    uv run --with pytest pytest firmware/tests -v

Compiles the pure-C/C++ decoder and radio-logic sources into a small host harness
(`tests/radio_host.cpp`) and exercises them against fixtures — no ESP32 hardware needed. This is
what CI/local checks run before anything goes near the bench; it does **not** exercise the Tasmota
glue in `xdrv_95_cc1101.ino` itself (that only builds inside the full PlatformIO/Tasmota tree via
`build.py`).

## See also

- `RECOVERY.md` — reflashing a bricked/misbehaving board, `Reset 5`/`Reset 6`, restoring
  `/cc1101.cfg`.
- `docs/mqtt-home-assistant.md` — full MQTT message schema, Home Assistant autodiscovery setup, node MQTT config, and the live-broker validation procedure.
- `docs/esp32c3-cc1101-node.md` — wiring, BOM, commissioning runbook, bench verification log.
- `docs/HWTEST-RESULTS-cc1101.md` — on-hardware validation log (CC1101 blue/green, SX1278 RA-02).
- The full design spec and numbered rulings (R1-R8) referenced above live in the project repo
  (github.com/mithro/433mhz, `docs/.../2026-08-20-esp32c3-cc1101-tasmota-design.md`).

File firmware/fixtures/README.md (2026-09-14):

# Fixtures

Real RF captures used by the host-side decoder tests and by Plan B's firmware
tests. Two JSON formats:

## `rf433-packets-v1` — FSK packet-mode bytes (CC1101 FIFO)

```json
{"format": "rf433-packets-v1",
 "source": "rpi5-433mhz CC1101 spidev0.0, cc1101_ws69_rx.py --packet-len 25",
 "captured": "2026-08-20T20:57:00+09:30", "freq_hz": 433920000,
 "packets": [{"hex": "24AE...", "rssi_dbm": -85.5, "lqi": 127, "crc_ok": true, "note": "WS69 id 174"}]}
```

`crc_ok` is the CC1101's own appended status bit for its packet CRC (not the
Fineoffset CRC); Fineoffset frames have no CC1101 CRC so it is informational.

## `rf433-pulses-v1` — OOK pulse trains (async-serial mode, GDO2 edges)

```json
{"format": "rf433-pulses-v1",
 "source": "rpi5-433mhz CC1101 async GDO2 -> GPIO24 via gpiod",
 "captured": "2026-08-21T10:00:00+09:30", "freq_hz": 433920000,
 "device": "Grey Power Remote 5, On button, 3 presses",
 "trains": [{"t0_us": 0, "us": [730, 200, 200, 730, "..."]}]}
```

`us` alternates mark (carrier on), space (off), … starting with a mark, in
microseconds. A train ends at a space longer than the capture tool's
`--burst-gap-us` (default 15000). Every fixture can be exported to rtl_433's
`.ook` text format with `tools/cc1101_ook_capture.py --export-ook`.

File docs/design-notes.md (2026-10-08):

# Design notes: the socket adapter

How `hardware/esp32c3-radio-adapter` is laid out and why: the GPIO
assignment, the single-layer routing, the expansion header, the DIO2
fly-wire header, the mechanical keep-outs and the radio-type strap. The
[README](../README.md) covers building and using it.

## Socket, GPIOs and single-layer routing

One 2x4 socket takes all three radio boards. Its eight positions are
wired to fixed GPIOs; which signal a position carries depends on the board,
so the firmware uses a pin map per board (positions are numbered like the
E07-M1101D's header, pin 1 at the right of the outer row seen from the
component side):

| Socket position | ESP32-C3 GPIO | Blue E07-M1101D (CC1101) | Green D-Sun (CC1101) | Ra-02 breakout |
| --- | --- | --- | --- | --- |
| 1 | GND | GND | GND | GND |
| 2 | 3V3 | VCC | VCC | 3V3 |
| 3 | GPIO10 | GDO0 (output) | MOSI | RST (input; drive it as an output) |
| 4 | GPIO1 | CSN | SCK | NSS |
| 5 | GPIO3 | SCK | MISO (output) | SCK |
| 6 | GPIO4 | MOSI | GDO2 (output) | MOSI |
| 7 | GPIO7 | MISO (output) | GDO0 (output) | MISO (output) |
| 8 | GPIO6 | GDO2 (output) | CSN | DIO0 (output) |
| strap | GPIO5 | JP1 open, R1 not fitted | as the blue board | jumper on JP1 or 0R in R1 (to GND); with jumper wires, to GPIO0 |

Read as per-board maps: blue E07 MOSI 4, SCK 3, CSN 1, MISO 7, GDO0 10,
GDO2 6; green D-Sun MOSI 10, SCK 1, CSN 6, MISO 3, GDO0 7, GDO2 4; Ra-02
MOSI 4, SCK 3, NSS 1, MISO 7, RST 10, DIO0 6.

The rule behind the assignment: **no socket position may be an ESP32-C3
boot strapping pin (GPIO2, GPIO8, GPIO9).** Whatever a radio pin does, it
loads the net with enough capacitance that, through the chip's weak internal
pull-up, a strap can rise too slowly for the mask ROM to read it high at
reset; the ROM then latches BOOT (GPIO9) low and drops into USB download
mode instead of running the firmware. This was measured on the bench on
2026-09-06, and it is not fixable in software (the ROM samples the strap
before any code runs). Position 4 (CSN/SCK/NSS) therefore takes **GPIO1**,
not GPIO9; GPIO9 carries nothing but R4, an optional do-not-populate
pull-up to 3V3, so by default its internal pull-up floats it high -- the
safest state, since nothing can pull an unconnected pin low -- and R4 can
hold it there harder if ever wanted.
GPIO5 is the radio-type strap (below); a second 3V3 and the unused GPIOs
(GPIO0, 2, 8 and the UART pair GPIO20/21) are brought out to a 1x7 header on
the top edge, and the two straps that stay on that header (GPIO8, GPIO2)
each have an optional do-not-populate pull-up-to-3V3 footprint. GPIO21 and
GPIO20 are brought out a second time on J5, a 1x2 header sitting between the
SuperMini and the radio board, where GPIO20 takes the fly wire an SX1278
needs for its raw bitstream (below). The
SuperMini's pins go into 1.0 mm through-holes so it
can be fitted with headers, and the pads are also extended past the
SuperMini's edge so it can be soldered flat by its castellations; its USB-C
connector hangs off the board edge and no copper runs under its ceramic
antenna. The silkscreen carries the SuperMini's own pin names on the outer
side of each header row and the radio signal names on the inner side, and
it outlines the two mechanical keep-out areas -- the ground the SuperMini
and the plugged-in radio board stand on -- so what is left free is visible
on the printed board.
Routing is generated by `scripts/generate_adapters.py`.

| 3D render, top | 3D render, bottom | Layout (copper, silk, fab, outline) |
| --- | --- | --- |
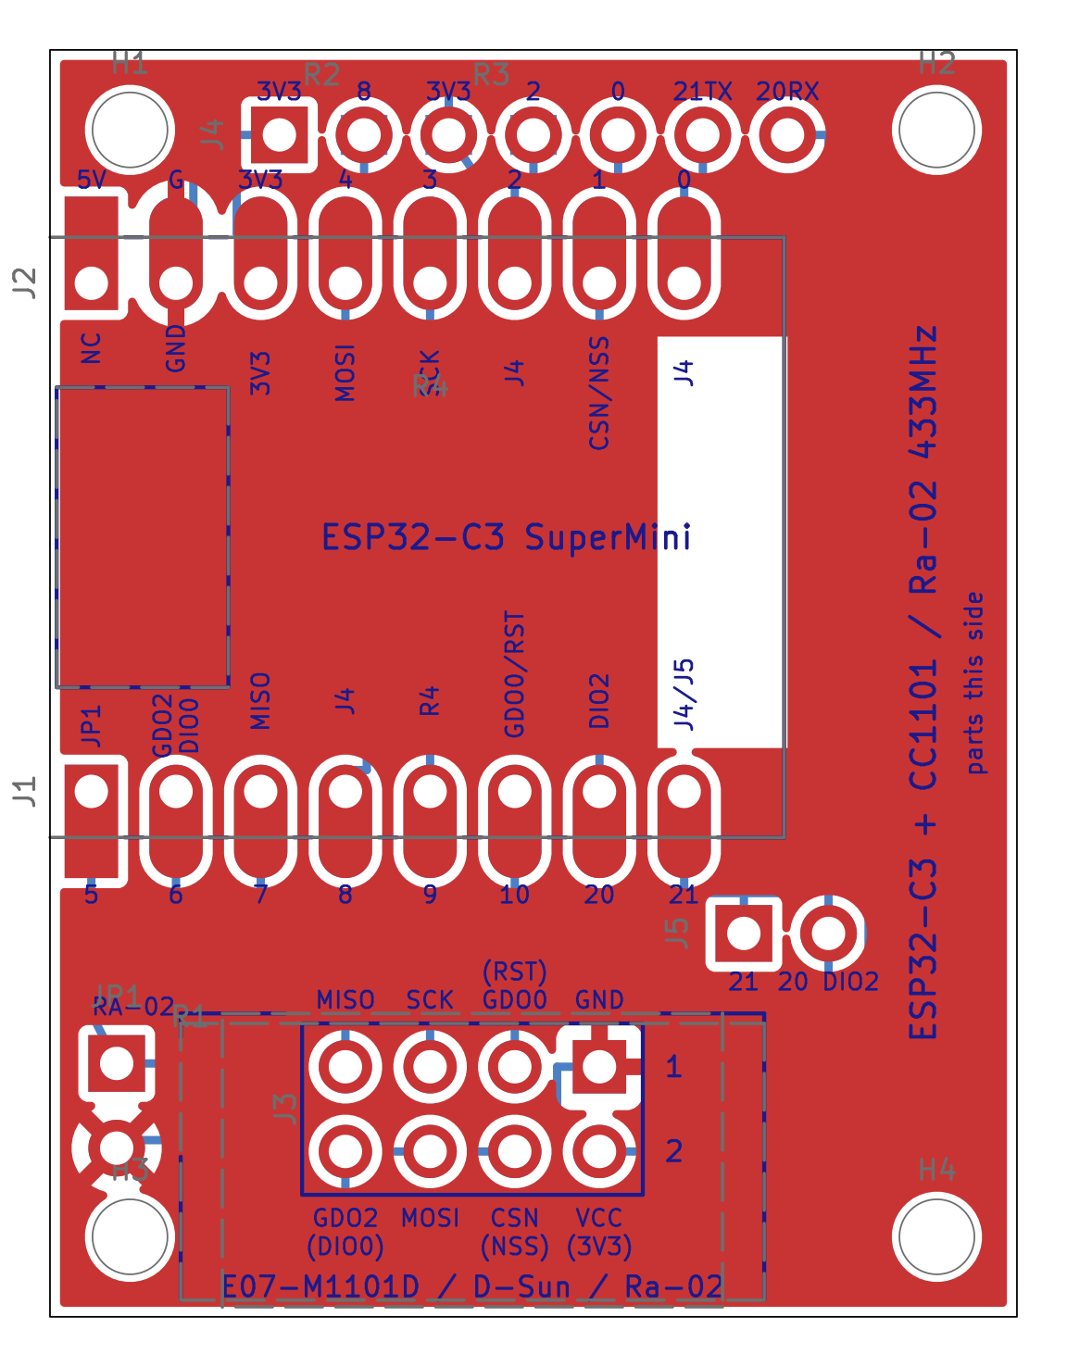
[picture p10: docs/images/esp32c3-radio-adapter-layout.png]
2D layout plot
| 3D render of the top side | 3D render of the bottom side |  |

`hardware/esp32c3-radio-adapter`, 29&nbsp;x&nbsp;38 mm. Every track is on the back
copper, the expansion header and strap included; the front carries only the
pad copper and a GND pour (thermal-relieved to the SuperMini's G pin, the
socket's GND pin and the strap), so the back-layer artwork alone works as a
single-sided board for the header-pin option, with R1 on the copper side. A
keepout on both layers keeps the pour and all tracks away from the
SuperMini's ceramic antenna (the 3.8 mm of the module furthest from the
USB-C). Silkscreen is printed on both sides (the back copy mirrored), and
there is an M2 mounting hole 2.4 mm in from each corner.

The SuperMini lies on its side with its body overhanging the left edge by
0.5 mm, so its USB-C connector hangs clear of the board. Each of its 16 pins
lands on a keyhole pad: a 1.0 mm hole for header pins with 1.6&nbsp;x&nbsp;3.4 mm oval
copper extended outward to 1.2 mm past the SuperMini's edge, so the module
can instead be soldered flat by its castellations. Note that the flat option
needs the pad copper on the front, i.e. a normal two-layer (or plated) build
of the same files; on a home-etched single-sided board only the header-pin
option is available, because a castellated module on the copper side would
present its pins mirrored.

One 2x4 socket (1.0 mm holes, numbered like the E07-M1101D header: pin 1
square at the right of the outer row) takes either radio board, plugged in
component side up and extending past the bottom edge with its antenna
connector away from the carrier; the socket sits far enough right that
either board clears the bottom-left screw. The silk shows the E07-M1101D's
pin names next to the socket and, where the Ra-02 breakout's differ, the
breakout's names in parentheses one line further out; beside the SuperMini
the two board-dependent signals read "GDO0/RST" (GPIO10) and "GDO2/DIO0"
(GPIO6); the D-Sun's names are in the table above.

Lying sideways puts the SuperMini's GPIO row directly above the socket and
its power row behind it, which together with the GPIO assignment lets
every net, header and strap included, route on the back copper without
jumpers. Position 3 (GPIO10) drops straight into the socket; position 7
(GPIO7) takes a short lane into the column under GPIO8's pad, and position
8 (GPIO6) goes down the left of the socket into its pad from below.
Positions 4, 5 and 6 are fed from the power row: SCK (GPIO3) and MOSI
(GPIO4) come down between the SuperMini rows into positions 5 and 6, and
CSN (GPIO1) crosses over between the rows and drops into position 4 from
the left -- the corridor GPIO9 used to occupy. GPIO8 climbs between the
drops to the header. GPIO9's pad is boxed in by SCK and CSN, so its
pull-up R4 sits between the rows in GPIO9's column: SCK steps one gap
left as soon as it leaves its pad, and 3V3 comes down from J4 pin 3
through the power row's gap between GPIO3 and GPIO2 into R4's top pad;
R4's other pad drops into GPIO9. GND and 3V3 leave the power row
upward, run along the top edge above the expansion header and down the
strip right of the SuperMini into the socket's right column, GND
continuing under the socket to the strap. The layout plot shows the
back-copper tracks in blue.

## Expansion header (J4)

J4 is a 1x7 2.54 mm header on the top edge, centred between the mounting
holes, carrying 3V3 and every GPIO the radio does not use in the order 3V3,
GPIO8, 3V3, GPIO2, GPIO0, GPIO21, GPIO20 (pin 1, square, at the left; the
silk names them the way the SuperMini does, with the spare UART marked
"21TX" and "20RX"). Each boot strap on the header has a 3V3 pin on its
left for its pull-up, and the second 3V3 also feeds R4 (GPIO9's pull-up,
above). GPIO2 and 0 rise straight from the power row, GPIO8
climbs from the GPIO row between the rows, and GPIO21 and GPIO20 leave the
GPIO row's right end and come up the strip right of the SuperMini, the
same strip GND and 3V3 come down. 5V is not on the header: its pad sits
under the top-left mounting hole and cannot be reached on one layer. GPIO2
and GPIO8 are boot strapping pins, so R2 and R3 -- optional do-not-populate
0805s that bridge each to the 3V3 pin on its left -- can pull them high at
reset if whatever is hung on those two would otherwise hold them low.

## The DIO2 fly-wire header

J5 is a 1x2 2.54 mm header carrying GPIO21 (pin 1, square) and GPIO20
(pin 2) -- the same two nets J4 already has, brought out a second time
where a wire to the radio board can reach them. **GPIO20 is the DIO2/DATA
pin.** An SX1278 has two data modes, and only continuous mode gives the
firmware the demodulator's raw edges: the datasheet has it that "each bit
transmitted or received is accessed in real time at the DIO2/DATA pin",
with the FIFO and packet handler inactive, and Table 29 offers no other DIO
that can carry the data in Rx. Packet mode carries only what the chip's
packet handler can frame, which suits the Fineoffset stations but not the
OOK remotes this node exists to hear and key -- arbitrary PWM/Manchester
bursts with no sync word. DIO2 is the SX1278's GDO2, and the Ra-02 breakout
leaves it unconnected on the module edge, so the raw-OOK path needs one
wire: from the breakout's DIO2 pad (its exposed land sticks 0.8 mm out past
the module edge, on the right-hand side about 9 mm down from the header) to
J5 pin 2 (the pad is marked on the
[pinout diagrams](#why-one-socket-fits-all-three-boards), and
[**Adding the DIO2 wire**](../hardware/parts/sx1278-ra02-breakout/dio2-wire.md)
covers the radio end and how to verify it). In the
[jumper-wire build](../README.md#jumper-wire-version-no-adapter-needed) the same wire goes straight to
GPIO20. Nothing is given up by sharing the pin with J4:
it is one net brought out twice, so only one of the two may be used at a
time, and GPIO21 keeps the UART console's TX.

J5 is why the board is 38 mm rather than 36.5 mm tall. A 2.54 mm header
body and both plugged-in boards all sit at board level, so the header has
to be clear of them in plan view, and the only such region is the band
between the SuperMini's body (which ends at y = 23.6) and the radio board's
top edge. At 36.5 mm that band was 4.08 mm, leaving 0.77 mm either side of
the 2.54 mm body; 1.5 mm more opens it to 5.58 mm and takes the margins to
1.61 mm above and 1.43 mm below. GND is not on J5 -- reaching it would mean crossing the 3V3 lane
in the strip, and it is not needed, since the two boards already share GND
through the socket.

Routing it kept the board single-sided, but fixed which net sits on which
pin. GPIO21 drops off the GPIO row to the right of GPIO20, so it has to
take the lane above J5's pads and stubs down into pin 1; GPIO20 takes the
lane below and climbs the strip straight through a pad of its own net,
pin 2. The gap to the right of pin 2 is only 0.225 mm, so GPIO20's lane
has nowhere else to pass. The four strip lanes moved 0.45 mm left to make
room, with 3V3 and GND out at 24.55 and 25.0, still 0.375 mm clear of the
M2 holes.

## Mechanical keep-out

Both boards sit at board level: the SuperMini either soldered flat by its
castellations or on 2.5 mm header bodies, the radio board on its own header.
So anything else fitted to the adapter has to stay out of their plan-view
footprints, and both are outlined on the silkscreen (front and back):

* the SuperMini's body, 22.5&nbsp;x&nbsp;18.0 mm, ending at y = 23.62. Its long edges
  run through the keyhole pads, so they print as the pieces that fit in the
  0.94 mm gaps between pins -- which doubles as an alignment mark for the
  castellated build, since the module's edge should land on them.
* the envelope of whatever plugs into the socket: as wide as the Ra-02
  breakout (x 3.92 to 21.42) and reaching as far up as the E07-M1101D's
  edge (y = 28.9), so it covers all three boards. It breaks around the
  socket outline and around R1's pads, which the Ra-02 overhangs -- R1 is
  on the back copper, so that is clearance, not a collision, but a jumper
  fitted to JP1 stands 6 mm tall and clears the breakout's edge by only
  0.67 mm.

The fab layers keep the E07's and the Ra-02's outlines separately, and the
band between the two keep-outs is where [J5](#the-dio2-fly-wire-header)
lives.

## Radio-type strap (JP1, R1)

JP1 and R1, in the bottom-left corner beside the plugged-in radio board,
strap GPIO5 (net `RADIO_ID`) to GND so firmware can tell which radio it is
driving: JP1 is a 1x2 2.54 mm header for an ordinary jumper, R1 an 0805 pad
pair on the back copper in parallel with it for a 0R resistor as the
permanent alternative. The SX1278 module adapter ties the same pin to 3V3,
giving three distinct states:

| GPIO5 reads | Board |
| --- | --- |
| floating | this adapter with a CC1101 board: no jumper, R1 empty |
| low | this adapter with the Ra-02 breakout: jumper on JP1 or 0R in R1 |
| high | the SX1278 module adapter (GPIO5 hard-wired to 3V3) |

To read it, first drive GPIO0 low as an output (see below), then enable
GPIO5's internal pull-down and sample (high means the SX1278 module
adapter), then enable the pull-up and sample again (low means the Ra-02;
high means the pin is floating, i.e. a CC1101). GPIO5 is not an ESP32-C3
boot strapping pin, so tying it either way is harmless. Driving GPIO0 low
covers the [jumper-wire build](../README.md#jumper-wire-version-no-adapter-needed), where the SuperMini's
only GND pin is taken and the strap wire goes from GPIO5 to GPIO0 instead;
on the adapters GPIO0 is a spare pin on the header, so it makes no
difference there.

The strap does not tell the two CC1101 boards apart; the firmware can,
without driving anything: an unconfigured CC1101 clocks its crystal
frequency divided by 192 (about 135 kHz) out of GDO0, so whichever of
GPIO10 (blue board) and GPIO7 (green board) is toggling at power-up names
the board. Only then configure SPI with that board's map.

## Why one socket fits all three boards

Seen from the carrier (radio board plugged in component side up, its header
edge at the top) the blue board's and the Ra-02 breakout's 2x4 headers are
laid out almost identically. Pin numbers are the E07-M1101D's own and the
odd/even numbering used for the Ra-02 breakout in this repository:

| Socket position | E07-M1101D (CC1101) | Ra-02 breakout | ESP32-C3 GPIO |
| --- | --- | --- | --- |
| Outer row, column 1 (left) | 7 MISO | 1 MISO | GPIO7 |
| Outer row, column 2 | 5 SCK | 3 SCK | GPIO3 |
| Outer row, column 3 | 3 GDO0 (output) | 5 RST (input) | GPIO10 |
| Outer row, column 4 (right) | 1 GND | 7 GND | GND |
| Inner row, column 1 (left) | 8 GDO2 (output) | 2 DIO0 (output) | GPIO6 |
| Inner row, column 2 | 6 MOSI | 4 MOSI | GPIO4 |
| Inner row, column 3 | 4 CSN | 6 NSS | GPIO1 |
| Inner row, column 4 (right) | 2 VCC | 8 3V3 | 3V3 |

Only column 3's outer pin and column 1's inner pin differ: the CC1101 board
puts its two interrupt outputs there (GDO0, GDO2) while the Ra-02 breakout
has its reset input and its single interrupt (RST, DIO0). Both positions are
wired to plain GPIOs, so firmware treats GPIO10 as an interrupt input for
the CC1101 and as the reset output for the Ra-02, and reads the Ra-02's
DIO0 on GPIO6.

Header pinouts of the radio boards, front and back

### The green D-Sun board

The green "433MHz D-Sun CC1101" board has the same eight signals on the
same 2x4 header, with its GND/VCC column in the same place, but its three
signal columns are shuffled (component side up, header edge at the top,
columns left to right, outer / inner row):

| Column | Blue E07-M1101D V2.0 | Green D-Sun |
| --- | --- | --- |
| 1 (left) | MISO / GDO2 | GDO0 / CSN |
| 2 | SCK / MOSI | MISO / GDO2 |
| 3 | GDO0 / CSN | MOSI / SCK |
| 4 (right) | GND / VCC | GND / VCC |

Plugged into the socket it is powered correctly and its signals arrive on
GPIO7 (GDO0), GPIO6 (CSN), GPIO3 (MISO), GPIO4 (GDO2), GPIO10 (MOSI) and
GPIO1 (SCK), which the firmware's D-Sun pin map absorbs. Its SCK lands on
position 4, which -- like every socket position -- is a plain, non-strapping
GPIO. Its reference board is [hardware/parts/cc1101-dsun](../hardware/parts/cc1101-dsun/).

(Diagram drawn by `scripts/draw_pinouts.py` from the generators' geometry.)

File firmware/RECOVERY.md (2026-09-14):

# Reflash & recovery — ESP32-C3 + CC1101 Tasmota node

How to (re)flash this board, reset Tasmota settings, and restore `/cc1101.cfg`. This node is a
much easier recovery story than a bare-MCU radio board (an ATmega48 bridge, an E22
EFM8): the ESP32-C3's **ROM bootloader** is the
unbrickable backstop, reachable over the same USB-C port with just a button press — no C2/HVPP
adapter, no case-opening.

## The two kinds of "recovery"

| Failure | Symptom | Fix |
|---|---|---|
| **Bad settings/config** — wrong template, wrong WiFi/MQTT, corrupt `/cc1101.cfg` | boots, radio may misbehave or driver disables itself, but Tasmota itself runs | `Reset 5`/`Reset 6` (console/MQTT command) for Tasmota settings; delete/re-upload `/cc1101.cfg` via the web file manager |
| **Bad flash** — wrong/corrupt firmware image, or a device that isn't running our firmware at all | doesn't boot, or boots into something else entirely | **Hold BOOT, reflash over native USB with `esptool.py`** — always works; the ROM bootloader is independent of whatever is (or isn't) in app flash |

## USB BOOT-button reflash (the backstop)

The ESP32-C3's **ROM bootloader** lives in mask ROM — it cannot be erased, corrupted, or
overwritten by any application flash. Holding **BOOT** (GPIO9) low at reset forces the chip to
run the ROM bootloader instead of whatever is in flash, and it always accepts a new image over the
same native-USB port used for the normal console. This is true no matter how badly the current
flash contents are broken (bad firmware, half-written OTA, wrong chip target, completely blank
flash) — the same reason C2 is unbrickable for the EFM8 boards and HVPP for the ATmega48.

```
# 1. Hold BOOT, plug in USB-C (or press RESET while still holding BOOT), then release.
# 2. Board re-enumerates as 303a:1001 -> /dev/radio-cc1101-node-<serial> (udev rule).
esptool.py --chip esp32c3 --port /dev/radio-cc1101-node-<serial> write_flash 0x0 \
    firmware/dist/tasmota32c3-cc1101-combined.factory.bin
# 3. Unplug/replug WITHOUT holding BOOT -> boots the freshly flashed firmware.
```

Both `.factory.bin`s already lay down the main firmware **and** a Tasmota safeboot image in the
reserved factory slot (Tasmota's build merges a safeboot into every `.factory.bin`), so after this
one BOOT-button flash, later recoveries from a failed OTA happen **over WiFi with no button** (see
[`docs/bootloader-recovery.md`](docs/bootloader-recovery.md) → "Safeboot fallback" for the full
recovery matrix and its limits). Prefer `tasmota32c3-cc1101-combined.factory.bin`: its safeboot is
our own pinned build rather than the network-fetched release one — same recovery behaviour,
reproducible.

Always flash a **`.factory.bin`** here, not the OTA `.bin` — the factory image includes the
bootloader and partition table, so it is the only one guaranteed to boot a device in an unknown
state (wrong partition table, foreign firmware, blank chip). Because it re-lays the whole flash,
this also wipes NVS/settings and the LittleFS filesystem (including `/cc1101.cfg`) — back those up
first if reachable (see below) and they matter.

If `esptool.py` can't find the port or reports sync errors, double-check BOOT was actually held
through the plug-in/power-up moment (a press *after* enumeration is too late) and that no other
process has the port open (`fuser` / close any open console session first).

## Tasmota settings reset (`Reset`)

Standard stock Tasmota command, run from the console or `cmnd/<topic>/Reset`:

| Command | Effect |
|---|---|
| `Reset 1` | Erase Tasmota settings (WiFi/MQTT/GPIO template/etc.), keep current firmware |
| `Reset 5` | Erase Tasmota settings, **keep the saved WiFi SSID/password** so the node rejoins the same network |
| `Reset 6` | Same as `Reset 5`, and also keep the saved MQTT host/user/password/topic |

`Reset 5`/`6` erase the NVS `main`/`qpc` namespaces and delete Tasmota's own `/.settings` file —
they do **not** touch other files on the LittleFS filesystem, so **`/cc1101.cfg` survives a
`Reset 5`/`6`** (verified against Tasmota's `SettingsErase()`/`type==2` path in
`tasmota_support/support_esp32.ino`). After a `Reset 5`/`6` you will need to re-run the template +
`Module 0` + `CcMode` steps from the commissioning runbook (`docs/esp32c3-cc1101-node.md`),
but the node's Security+ id/rolling counter and mode survive if `/cc1101.cfg` wasn't itself the
thing you were trying to reset.

To also clear `/cc1101.cfg` (e.g. to force fresh Security+ pairing), delete it explicitly — see
below; `Reset` alone will not do it.

## Restoring / clearing `/cc1101.cfg`

`/cc1101.cfg` lives on the Tasmota LittleFS filesystem (`USE_UFILESYS`), which has its own web UI
page independent of the firmware-upgrade page: **Consoles → Manage File system** (or
`http://<node-ip>/ufsd`). From there you can:

- **Back up before any risky operation:** download `/cc1101.cfg` to your machine.
- **Restore:** upload a previously downloaded `/cc1101.cfg` back to the same path. The driver
  validates it on the next boot (`magic == 0xCC110101`, `version == 1`, and an exact byte-size
  match — see `firmware/README.md`'s config table); a file that fails validation is silently
  ignored and the node falls back to defaults, it will not crash or refuse to boot.
- **Clear / force defaults:** delete `/cc1101.cfg` from the same page (or just don't restore one
  after a full factory reflash). On the next boot the driver finds no file and loads
  `CcCfgDefaults()`: `mode = remotes`, `raw = 0`, `secplus_id = 0`, `rolling = 0`,
  `secplus_freq = [433.92]`. This is the right move if you want a garage-transmitter node to start
  a *fresh* Security+ pairing (new `SecplusId`, rolling counter back at 0) rather than resuming an
  old identity.

There is no console command to erase just this one file — the file manager page is the only path
(short of the full BOOT-button reflash, which wipes the whole filesystem along with it).

## OTA gone wrong

`OTA_URL` is blanked in this build (see `firmware/README.md`), so the stock `Upgrade`/`OtaUrl`
commands have nowhere to pull from — an accidental `Upgrade 1` fails safely rather than replacing
this firmware with stock `tasmota32c3`. A **manual** web-UI/`curl` upload of the wrong `.bin` (e.g.
another node's build, or `tasmota32c3-cc1101.factory.bin` instead of the OTA image) can still
leave the device in a bad state.

Either `.factory.bin` populates the safeboot slot, so an interrupted or failed main-app OTA does
**not** need the BOOT button: Tasmota performs the main-app OTA from safeboot and erases otadata to
get there, so a failed flash boots back into safeboot (reachable over WiFi) to retry. Re-upload the
main app over WiFi from the safeboot web UI. (Note: this build sets
`CONFIG_BOOTLOADER_SKIP_VALIDATE_ALWAYS`, so the bootloader does **not** validate `app0` — a
corrupt-in-place app is not auto-rejected; it only recovers itself if it crash-loops fast enough to
trip Tasmota's boot-loop→safeboot counter, otherwise it needs the BOOT button.) A full USB brick
always needs the BOOT-button reflash above. See
[`docs/bootloader-recovery.md`](docs/bootloader-recovery.md) → "Safeboot fallback" for the full,
source-verified recovery matrix and its limitations.

## Recovery decision tree

```
Device misbehaving?
├─ Web UI/console reachable, wrong config/template/mode
│   └─ fix directly (template, CcMode, ...), or `Reset 5`/`Reset 6` (keeps /cc1101.cfg) then
│      re-run commissioning.
├─ Web UI/console reachable, want a clean Security+ identity
│   └─ Manage File system -> delete /cc1101.cfg -> reboot -> re-pair.
├─ Bad/interrupted main-app OTA (either .factory.bin has safeboot)
│   └─ node comes up in safeboot (WiFi) -> re-upload the main app over WiFi. No button.
├─ Web UI/console NOT reachable (blank chip, foreign firmware, corrupt-in-place app0, dark node)
│   └─ hold BOOT, reflash tasmota32c3-cc1101-combined.factory.bin over native USB. Always works.
└─ Want to preserve /cc1101.cfg across a factory reflash
    └─ back it up via Manage File system BEFORE reflashing (a factory image wipes the
       filesystem); restore it the same way afterwards.
```

## See also

- [`README.md`](README.md) — build, first flash, OTA, command/MQTT reference, `/cc1101.cfg` fields.
- [`docs/esp32c3-cc1101-node.md`](docs/esp32c3-cc1101-node.md) — commissioning runbook, wiring, USB
  device mapping.
- The bare-MCU boards' recovery stories, for contrast: this node's ROM bootloader plays the
  same role as their C2/HVPP, an unbrickable backstop independent of app flash content.

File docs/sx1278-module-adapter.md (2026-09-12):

# SX1278 castellated module and its adapter

A second carrier, `hardware/esp32c3-sx1278-adapter`, takes the 16-pin
castellated SX1278 module (PXL1276-D01) instead of a socketed board. It uses
the socket adapter's GPIOs, with MOSI and SCK swapped so that its bottom
copper routes.  Its signals also keep clear of the boot straps: NSS, DIO0
and RESET moved off GPIO9/GPIO10/GPIO8 to GPIO10/GPIO20/GPIO21 (GPIO8 and
GPIO9 are left unused), for the same reset-into-download reason as the
socket adapter:

| Signal | ESP32-C3 GPIO | SX1278 module pin |
| --- | --- | --- |
| MOSI | GPIO3 | 7 MOSI |
| SCK | GPIO4 | 8 SCK |
| Chip select | GPIO10 | 9 NSS |
| MISO | GPIO7 | 6 MISO |
| IRQ / packet | GPIO20 | 10 DIO0 |
| Second IRQ | GPIO6 | 2 DIO1 |
| Reset | GPIO21 | 11 RESET |
| 3.3 V | 3V3 | 5 VCC |
| GND | GND | 1, 12, 15 GND |
| Radio-type strap | GPIO5 | tied to 3V3 (reads high) |

This adapter is two-layer: the GPIO-column signals (DIO1, MISO, NSS, DIO0,
RESET) run on the top copper in nested horizontal lanes below the SuperMini
(the GPIO order matches the module's pad order, so no lane crosses another),
while power, MOSI and SCK run on the bottom copper, with vias to the SMD
module pads. GPIO5 is hard-wired to 3V3 (silk "ID=3V3") so the
[radio-type strap](design-notes.md#radio-type-strap-jp1-r1) reads high here.
Its manufacturing packages are built alongside the pin-header adapter's.

## The adapter board

| 3D render, top | 3D render, bottom | Layout (copper, silk, fab, outline) |
| --- | --- | --- |
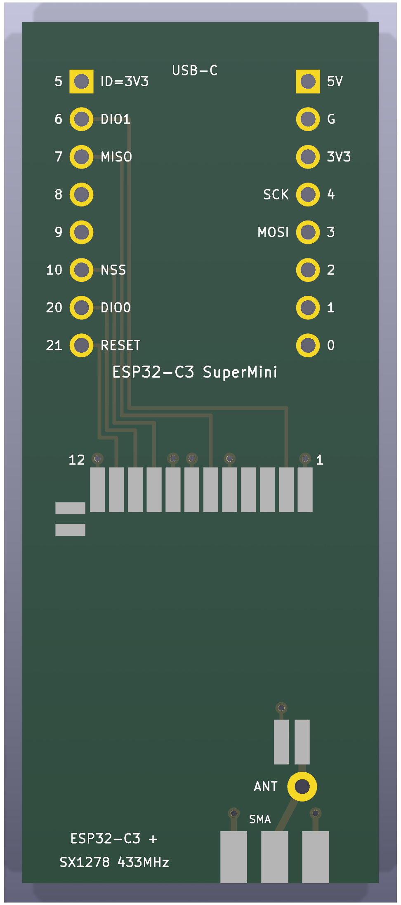
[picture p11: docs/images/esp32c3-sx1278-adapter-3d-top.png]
3D render of the top side
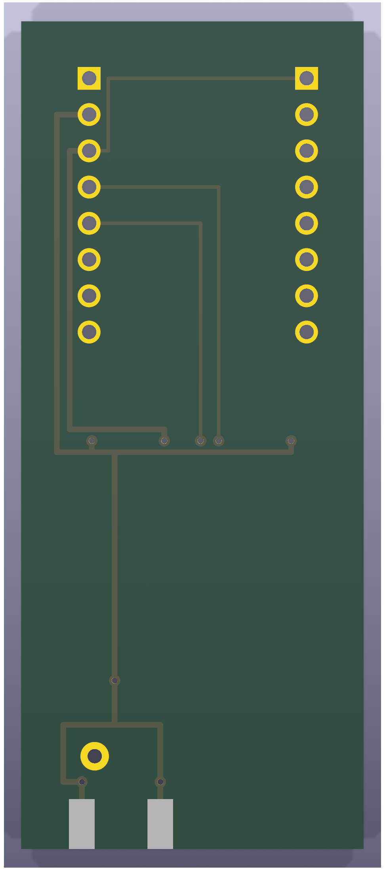
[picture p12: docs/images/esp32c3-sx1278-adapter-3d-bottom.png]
3D render of the bottom side
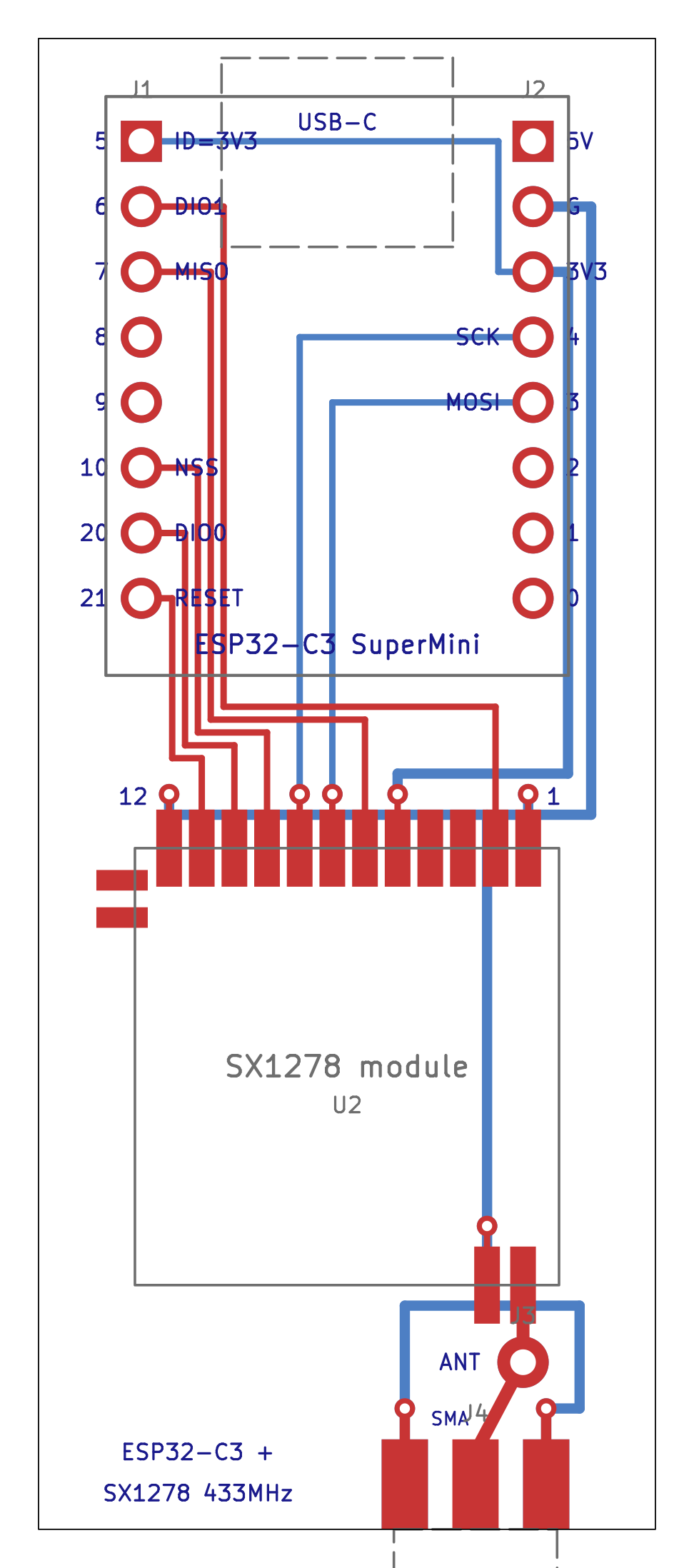
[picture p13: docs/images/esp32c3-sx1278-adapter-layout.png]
2D layout plot
|  |  |  |

`hardware/esp32c3-sx1278-adapter`, 24&nbsp;x&nbsp;58 mm. The SuperMini sits at the top
with its USB-C pointing off the top edge. The
[SX1278 module](../hardware/parts/sx1278-lora-module/) is soldered onto SMD land pads that
reproduce its castellations (1.0&nbsp;x&nbsp;3.0 mm pads extending 1.5 mm outside the
module edge), rotated so its 12-pad row faces the SuperMini and its ANT pad
faces the bottom edge. The antenna trace runs to a 1.0 mm hole for a spring
antenna wire (J3) and on to pads for an optional edge-mount SMA jack on the
bottom edge (J4, same footprint as the E07-M1101D's jack); fit one or the
other. DIO2-5 are landed but not connected -- including DIO2, the pin the
raw bitstream leaves the chip on, which the socket adapter reaches through
[J5](design-notes.md#the-dio2-fly-wire-header). This adapter's pin allocation is to be
brought into line with the socket adapter's, and DIO2 routed, in a separate
pass; its GPIOs currently differ from the socket adapter's in every signal
but MISO (GPIO7) and the radio-type strap (GPIO5).

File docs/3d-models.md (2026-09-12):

# 3D models and case design

`hardware/3d/` holds STEP models, built by `scripts/build_3d.py` with
[CadQuery](https://cadquery.readthedocs.io/), of every board in the repo
and of the parts that go with them. The KiCad boards reference them, so
KiCad's 3D viewer and `kicad-cli pcb export step` show the adapters
populated, and the CI release includes the resulting assemblies
(`<adapter>-assembly-<variant>.step` / `.glb`) ready to import into a CAD
tool for a case. The geometry that matters for a case (outlines, hole
positions, connector positions, stack heights) follows the footprints and
datasheets; chips, crystals and shield cans are boxes of the right size.

| Model | Origin | Contents |
| --- | --- | --- |
| `esp32-c3-supermini.step` | left column pin 1 (GPIO5) | PCB with castellations, USB-C (1.5 mm past the edge), buttons, chip, antenna, two 1x8 headers underneath |
| `cc1101-e07-m1101d.step` | header pin 1 (GND) | PCB with its two 3 mm holes, CC1101 and passives, edge-mount SMA jack, 2x4 header underneath |
| `cc1101-dsun.step` | header pin 1 (GND) | the green D-Sun board: PCB with its two 1.8 mm holes, CC1101, crystal and passives, SMA jack, 2x4 header underneath |
| `sx1278-ra02-breakout.step` | header pin 1 (MISO) | PCB, Ra-02 module with shield can and IPEX socket, 2x4 header underneath |
| `sx1278-ra02-pigtail.step` | as the breakout | U.FL plug, cable and SMA bulkhead jack with nut, on the same axis as the E07's SMA jack |
| `sx1278-lora-module.step` | module top-left corner | castellated module PCB and shield can |
| `*-components.step` | as above | the same without the PCB, for the reference boards under `hardware/parts/` |
| `pin-header-1x07/1x02.step`, `jumper-cap.step`, `r0805.step`, `sma-edge-jack.step` | footprint origin | the adapters' own parts |

Every module is joined to its adapter by a 2.54 mm male pin header soldered
at both ends: the header's 2.5 mm body sits between the boards (against the
module's back, on the adapter's front) and its long pins point down through
the adapter, so 4.4 mm of pin stands out under the 1.6 mm adapter. The
adapter's own headers face up, with 6 mm pins.

| Socket adapter with E07-M1101D | Socket adapter with Ra-02 breakout and pigtail |
| --- | --- |
| Socket adapter with the E07-M1101D plugged in | Socket adapter with the Ra-02 breakout and its U.FL-to-SMA pigtail |
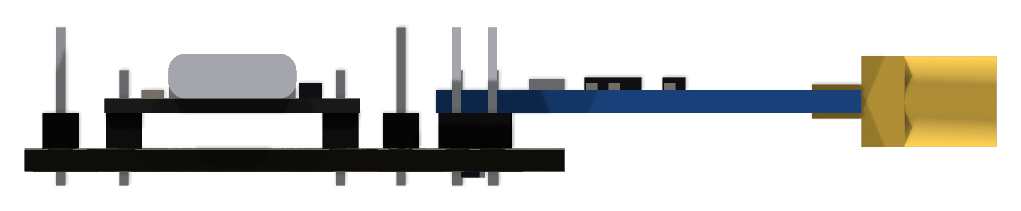
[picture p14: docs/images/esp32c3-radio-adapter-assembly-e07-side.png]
Side view with the E07-M1101D
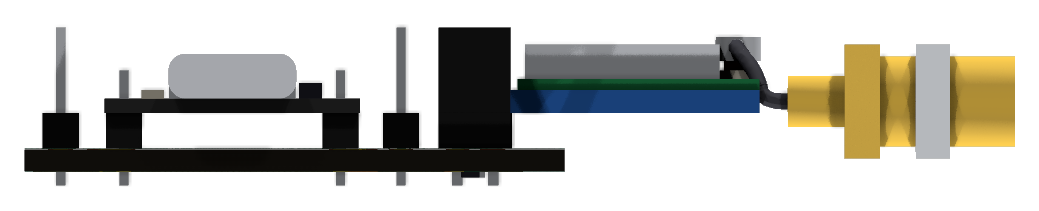
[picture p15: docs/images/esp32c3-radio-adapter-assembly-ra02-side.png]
Side view with the Ra-02 breakout
|  |  |

Key dimensions of the socket adapter assembly, in mm from the adapter's
top-left corner (x right, y down) and its top surface (z up); the STEP files
carry the rest:

| Item | x | y | z |
| --- | --- | --- | --- |
| Adapter board | 0 to 29 | 0 to 38.0 | -1.6 to 0 |
| M2 holes (2.2 mm) | 2.4 and 26.6 | 2.4 and 35.6 | |
| Pin tips under the board | | | -6.0 (module headers), -3.0 (J4, JP1, J5) |
| SuperMini PCB (1.0 thick) | -0.5 to 22.0 | 5.6 to 23.6 | 2.5 to 3.5 |
| USB-C receptacle | -2.0 to 5.4 | 10.1 to 19.1 | 3.5 to 6.7 |
| Highest point (J4/J5 pins, jumper on JP1) | | | 8.5 |
| J5 header body (2.54 cube per pin) | 19.54 to 24.62 | 25.23 to 27.77 | 0 to 2.5 |
| E07-M1101D PCB (1.6 thick) | 5.2 to 20.2 | 28.9 to 58.9 | 2.5 to 4.1 |
| E07 SMA jack: body, then barrel (6.35 dia) | axis 12.7 | 58.9 to 61.9, then to 68.4 | axis 3.3 |
| Ra-02 breakout PCB (1.6 thick) | 3.9 to 21.4 | 29.2 to 51.7 | 2.5 to 4.1 |
| Ra-02 shield can top / U.FL plug top | | | 7.3 / 7.9 |
| Pigtail SMA bulkhead: crimp, hex flange (8 AF), barrel, nut | axis 12.7 | 55.0 to 59.0, to 61.5, to 71.0; nut 64.0 to 66.4 | axis 3.3 |

J5's body clears the SuperMini by 1.61 mm and an Ra-02 breakout by
1.43 mm; an E07-M1101D's top edge is 0.3 mm further up the board, leaving
1.13 mm.

The bulkhead jack is placed so that its barrel sits where the E07's does
(same axis, starting 2.6 mm further out), so one antenna hole in a wall at
y = 61.5 to 64 suits both radios: the E07's jack passes through it, the
bulkhead is clamped in it by its nut. A real pigtail's cable is longer than
the drawn one, so leave room to stow the excess beside the breakout.

## The printed case

`scripts/build_case.py` builds exactly that case with CadQuery, from the
generator's constants and the table above: `hardware/case/*.stl` for
printing (each half in print orientation, open side up) and
`hardware/3d/esp32c3-radio-adapter-case-{bottom,top}.step` as KiCad models
(origin at mounting hole H1, both halves in their assembled position),
which the `radio-*-case-*` variants of `scripts/render_assemblies.py` put
on the board: `-case-closed` with both halves snapped together,
`-case-open` with the bottom half only, and `-case-exploded` with the top
half lifted 12 mm; `case-bottom` and `case-top` render each half by
itself.  Closed and open come out as one sheet each of the isometric view
and the six sides (front is the antenna end, back the SuperMini end with
the pry notch, left the USB-C window); the README's
[Printing a case](../README.md#printing-a-case) has the closed case with
the E07-M1101D, the open one with the Ra-02 and the halves on their own.
The design views, with either radio:

| E07-M1101D | Ra-02 breakout and pigtail |
| --- | --- |
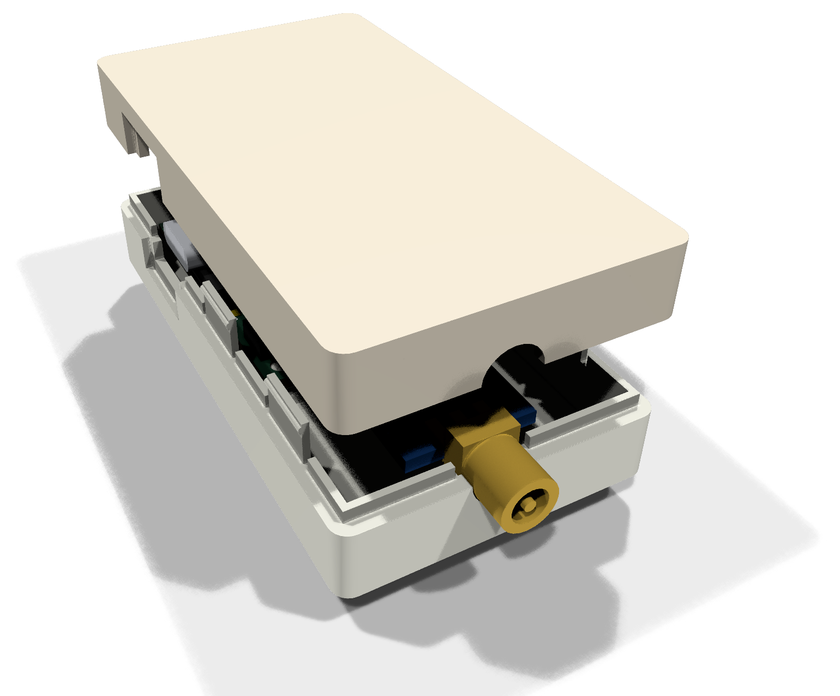
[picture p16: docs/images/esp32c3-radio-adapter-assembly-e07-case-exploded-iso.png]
E07-M1101D in the case, top half lifted
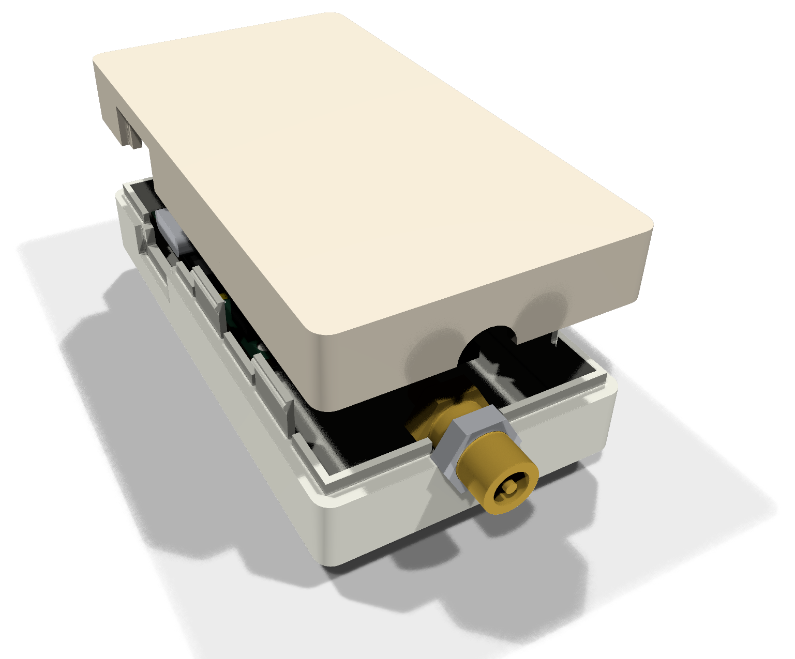
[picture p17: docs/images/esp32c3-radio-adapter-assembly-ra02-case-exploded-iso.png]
Ra-02 in the case, top half lifted
|  |  |
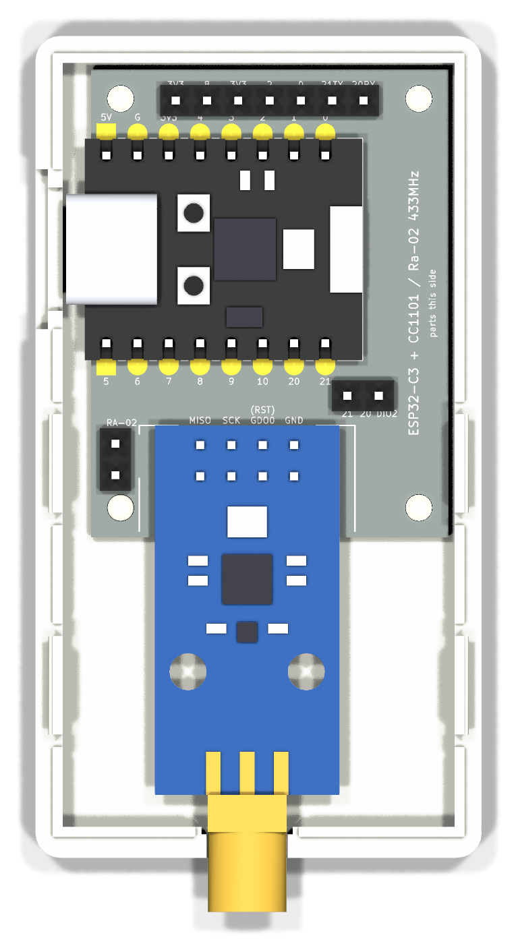
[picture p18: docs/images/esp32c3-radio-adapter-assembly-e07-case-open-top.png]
E07-M1101D in the bottom half, from above
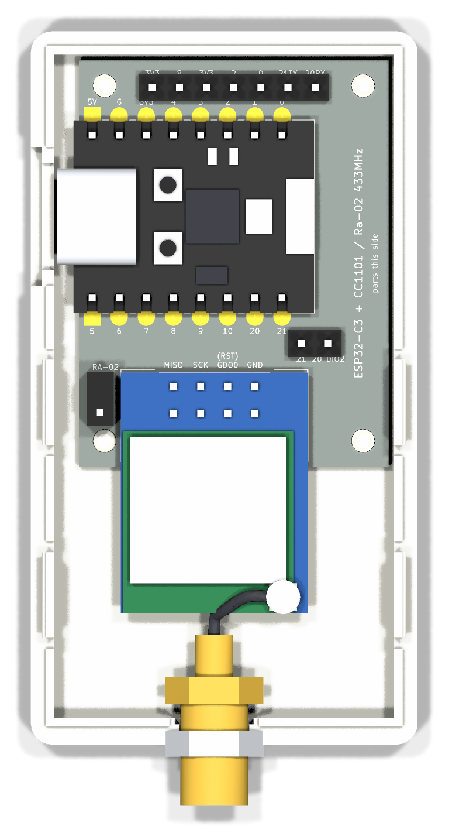
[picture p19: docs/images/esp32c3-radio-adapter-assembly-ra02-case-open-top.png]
Ra-02 in the bottom half, from above
|  |  |

Closed with the Ra-02 breakout, its pigtail bulkhead and nut in the
antenna hole:

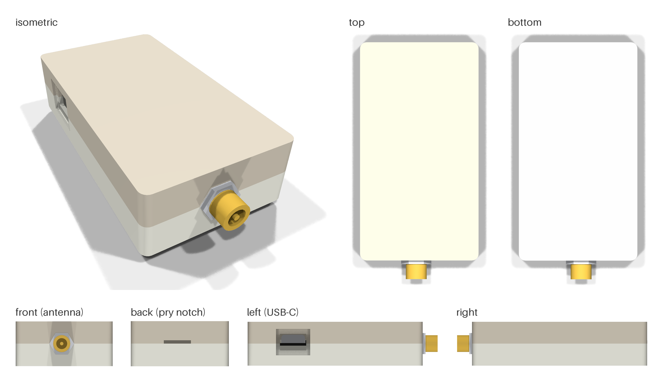
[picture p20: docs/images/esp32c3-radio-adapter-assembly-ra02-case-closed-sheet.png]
The closed case with the Ra-02 breakout: isometric, top, bottom, front (antenna), back (pry notch), left (USB-C) and right views


Open with the E07-M1101D:

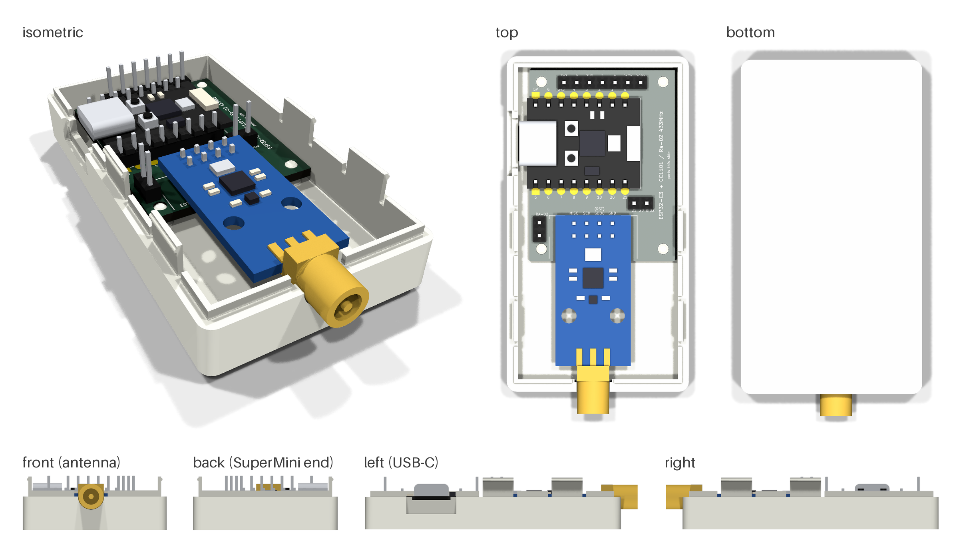
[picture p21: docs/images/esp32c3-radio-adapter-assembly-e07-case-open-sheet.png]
The bottom half of the case with the adapter and the E07-M1101D: isometric, top, bottom, front (antenna), back (SuperMini end), left (USB-C) and right views


Every release carries all four files, zipped with a README.txt of print
settings and ordering notes as `esp32c3-radio-adapter-case-<git describe>.zip`
(built by `scripts/export_case.py` from the committed files, see
[Development](development.md#ci-and-manufacturing-packages)), plus the two
STL files loose.

Dimensions, in the adapter's frame (x right, y down from the board's
top-left corner, z up from its top surface):

| Feature | Value |
| --- | --- |
| Cavity | x -2.3 to 29.5, y -0.5 to 61.5, z -3.1 to 9.6 (the USB-C face, the trimmed pin stubs and back-side 0805s under the board, and the J4/J5 pins, with 0.3 to 1.1 mm to spare). Every through-hole pin is assumed trimmed to a 1 mm stub under the board, i.e. to z -2.6 |
| Walls, floor, ceiling | 2.2 / 2.0 / 2.0 mm; the antenna wall 2.5 mm, y 61.5 to 64.0 |
| Outside | 36.2&nbsp;x&nbsp;66.7&nbsp;x&nbsp;16.7 mm, vertical corners R2 |
| Parting line | z = 3.3, on the antenna axis, so the antenna hole and the USB-C window are half in each half: the connectors lie in the bottom half's cut-outs and the top half closes over them. Bottom half 8.4 mm tall (13.4 with its tabs), top half 8.3 (11.4 with its bosses) |
| Standoffs and pegs | 4.0 mm standoffs under the four M2 holes, floor to the board's underside (1.5 mm), each with a 2.15 mm peg, chamfered, standing 0.4 mm proud of the board (flush at the bottom-left hole). FDM pegs print a touch oversize, which is the press fit into the 2.2 mm holes. 4 mm rather than 5 so the bottom-left one clears JP1's pin 2. |
| Hold-down bosses | from the ceiling to 0.2 mm above the board: 4.4 mm bosses bored 2.6 mm over three pegs, and a 3.0 mm solid one at (2.2, 36.6) in the bottom-left corner, beside its hole, because a jumper cap on JP1 and the Ra-02's overhang leave no room over it |
| Snap fit | the bottom half's lip (the inner 0.8 mm of the wall) rises 1.5 mm into a rebate in the top half's skirt, 0.15 mm clear, gapped at the antenna hole and across the USB-C recess (where the rebate would leave a 0.25 mm sliver of skirt, so there the top half's wall stays full thickness). Two tabs per long wall (at y 32 and 50), 8 mm wide, 5 mm tall, cut free of the lip by 1 mm slots, each with a 0.35 mm half-round bump at 4.3 mm that clicks into a 0.42 mm groove in the skirt. The bump stands 0.2 mm proud of the skirt face, about 1 % strain over the tab |
| USB-C window | left wall, 10 mm wide, z 0.7 to 7.0 (y 14.6 centre): the receptacle at either height, whether the SuperMini is soldered flat (receptacle z 1.0 to 4.2) or on its headers (3.5 to 6.7); split by the seam, so the bottom half's U cradles a flat-mounted receptacle. Outside it a 13&nbsp;x&nbsp;10 mm recess 1 mm deep takes the plug's overmoulding, leaving 1.2 mm of wall for the plug's shell to pass |
| Antenna hole | 6.6 mm at x 12.67, z 3.3, half in each half, with a 7.4 mm square pocket 0.6 mm deep on the inside of the bottom half for the E07 jack's body, which reaches 0.4 mm into the wall (in the top half the rebate already clears it) |
| J4 slot | in the second top half only: 18.8&nbsp;x&nbsp;3.5 mm through the ceiling over the spare-GPIO header, 0.5 mm past its body all round |
| Pry notch | 10&nbsp;x&nbsp;1.2 mm in the top half's skirt at the y = 0 end, on the seam |

The script's constants live in `scripts/case_dims.py`, which
`scripts/draw_case.py` also draws the [case drawings](case-drawings.md)
from (seven dimensioned sheets: plans of both halves and of the slotted
top, the section on the antenna axis, the end elevations and details of
the snap joint and the peg stack, each with a caliper checklist behind
it); the numbers above are the same constants. Before the script writes
anything it intersects both halves with a solid for every part they have
to house (the boards, the headers and a jumper cap, the pins under the
adapter, the back-side resistors, the USB-C receptacle and a plug's
overmoulding, both radios' antenna connectors and the pigtail's nut), with
the cavity above the board (which only the pegs and bosses may enter), and
with each other closed, and stops if any intersection is not empty. It
then measures the finished solids (every face, gap and centre the
drawings quote, over two hundred of them) against the constants and
writes them to `hardware/case/esp32c3-radio-adapter-case-measured.json`,
which is what `draw_case.py --check` compares the drawings with.

The SX1278 module adapter assembly (`esp32c3-sx1278-adapter-assembly-module`)
is 24&nbsp;x&nbsp;58 mm with the SuperMini at the top, the module soldered flat
(3.2 mm tall) and the optional SMA jack on the bottom edge at x = 17:

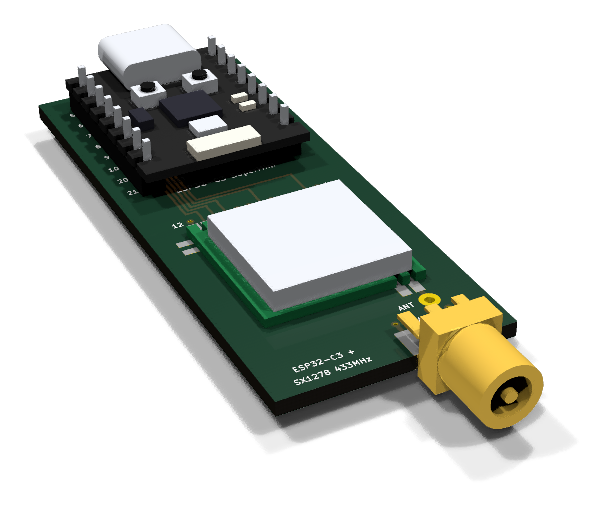
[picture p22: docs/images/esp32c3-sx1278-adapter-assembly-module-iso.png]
SX1278 module adapter with the SuperMini, module and SMA jack


The reference boards render with the products' parts on them:

| ESP32-C3 SuperMini | CC1101 E07-M1101D-SMA | CC1101 D-Sun | SX1278 Ra-02 breakout | SX1278 module |
| --- | --- | --- | --- | --- |
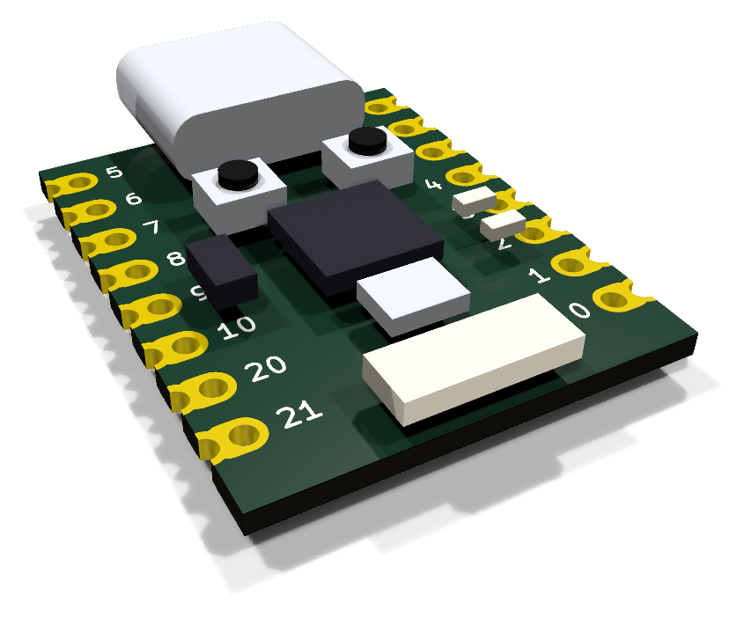
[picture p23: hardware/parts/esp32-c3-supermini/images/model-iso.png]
SuperMini model
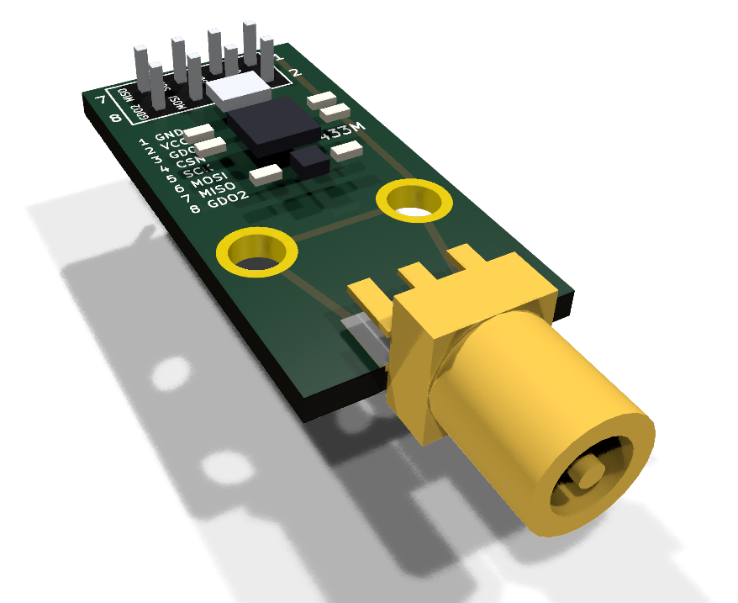
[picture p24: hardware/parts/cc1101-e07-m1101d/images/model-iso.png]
E07-M1101D model
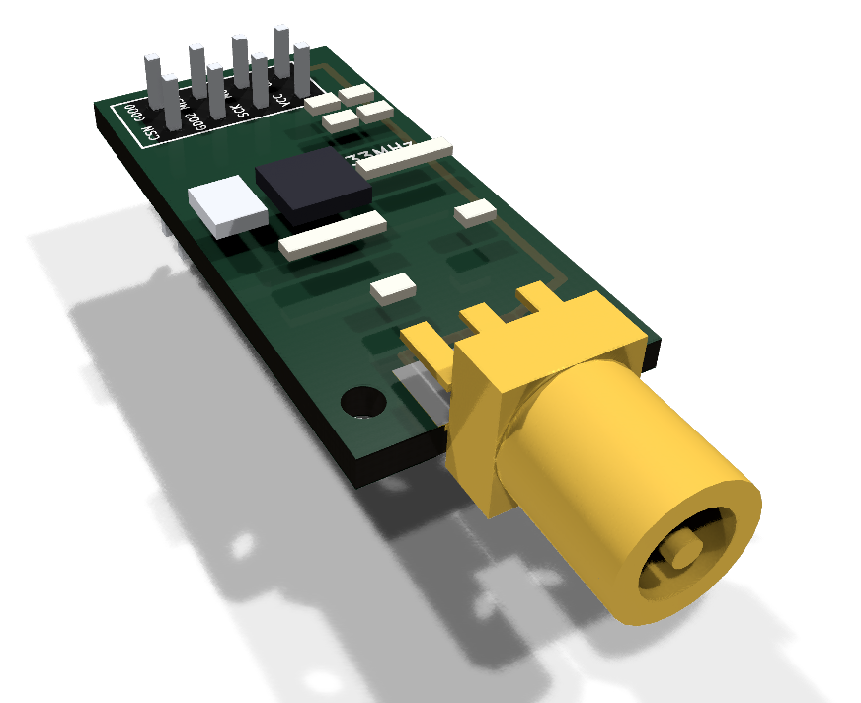
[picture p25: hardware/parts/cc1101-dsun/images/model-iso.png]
D-Sun model
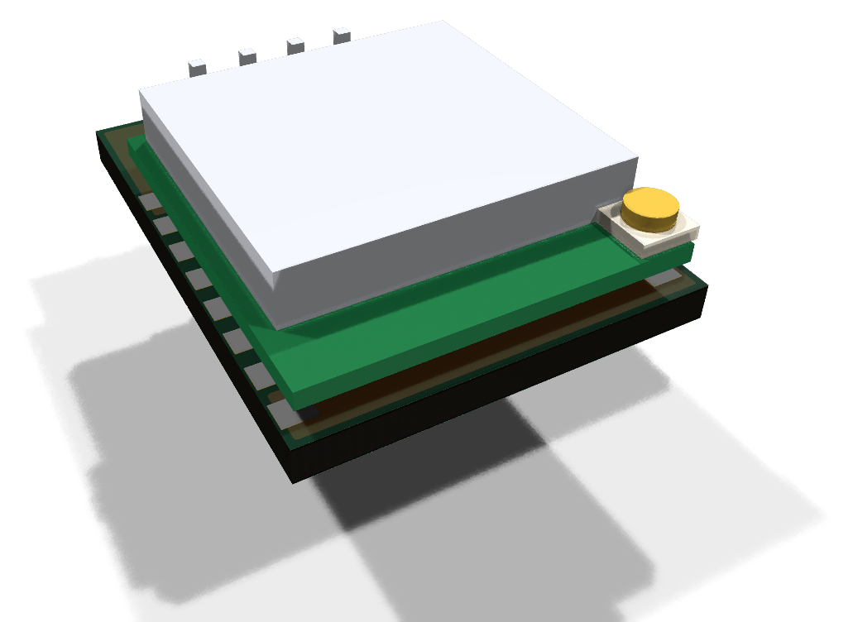
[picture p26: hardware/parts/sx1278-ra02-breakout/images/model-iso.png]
Ra-02 breakout model
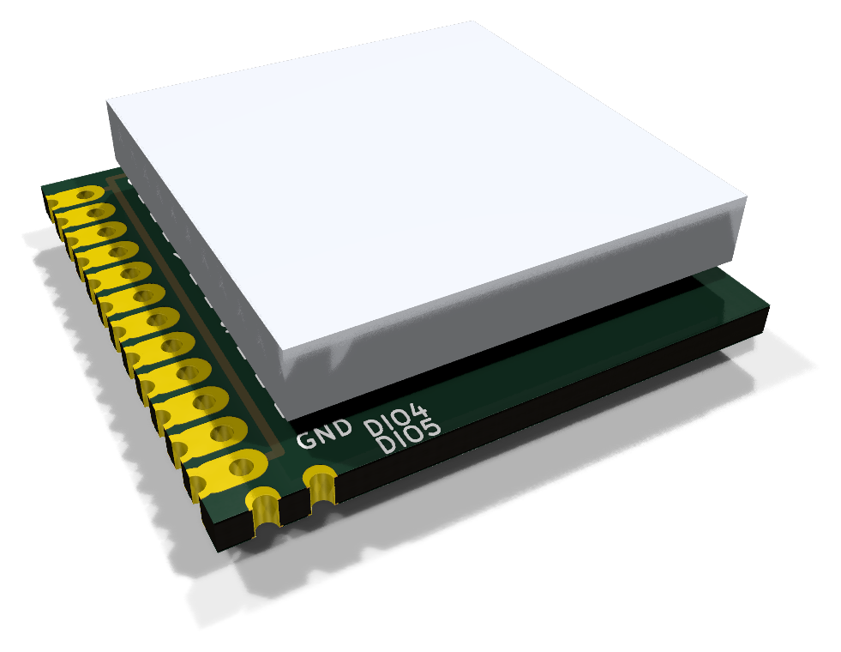
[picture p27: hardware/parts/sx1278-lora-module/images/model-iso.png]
SX1278 module model
|  |  |  |  |  |

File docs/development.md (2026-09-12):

# Development: regenerating, verifying and releasing

Every KiCad project in this repository is generated by a script, so edit
the generator rather than the KiCad files.

## Regenerating the projects

The projects are produced by the scripts in `scripts/`, which need only the
Python standard library plus the stock KiCad symbol libraries (for the
connector symbols embedded in the schematics):

```sh
uv run scripts/generate_supermini.py
uv run scripts/generate_sx1278.py
uv run scripts/generate_cc1101.py
uv run scripts/generate_dsun.py
uv run scripts/generate_ra02_breakout.py
uv run scripts/generate_adapters.py
uv run scripts/fill_zones.py         # fills copper zones with KiCad's own filler
```

`fill_zones.py` needs the `pcbnew` Python module (present in KiCad's Docker
images and Linux packages); with the KiCad snap it re-runs itself inside the
snap's environment. It copies only the fill polygons into the generated
files, which stay byte-identical otherwise.

`scripts/kicadgen.py` is the shared library (footprints, board, schematic,
project settings, DRC rules). Verification and rendering with KiCad 9.0
(`kicad-cli`) and inkscape:

```sh
uv run scripts/verify_boards.py      # ERC + DRC with schematic parity, all boards
uv run scripts/render_boards.py      # bare-board images: docs/images/*.png (adapters), hardware/parts/*/images/ (reference boards)
uv run scripts/draw_pinouts.py       # docs/images/pinout-radio-boards.svg
uv run scripts/draw_wiring.py        # docs/images/wiring-*.svg
uv run scripts/draw_case.py          # docs/images/case-*.svg, the case's mechanical drawings, and the checklist in docs/case-drawings.md
uv run scripts/build_3d.py           # hardware/3d/*.step (CadQuery; fetched by uv)
uv run scripts/build_case.py         # hardware/case/*.stl, the case's STEP models and its measured dimensions (CadQuery)
uv run scripts/draw_case.py --check  # compares every number on the drawings with the measured solids (no CadQuery)
uv run scripts/render_assemblies.py  # docs/images/*-assembly-*.png, hardware/parts/*/images/model-iso.png
uv run scripts/export_case.py        # dist/esp32c3-radio-adapter-case-<rev>.zip from the committed case files
```

ERC reports only "global label not connected anywhere else" warnings (each
pin carries a single global label); DRC reports no violations on any board.

The case's dimensions are the constants in `scripts/case_dims.py` (plain
Python), shared by `build_case.py` and `draw_case.py`. `build_case.py`
probes the finished solids and writes every dimension it measures to
`hardware/case/esp32c3-radio-adapter-case-measured.json`; every number on
the drawings is tagged with the name of one of those measurements, and
`draw_case.py --check` reads the numbers back out of the SVG files (and the
checklist it writes into `docs/case-drawings.md`) and compares them with
the measurements, failing on a mismatch, an untagged number or a name the
solids were not measured for. The sheets' revision is the `git describe`
of the last commit that touched `hardware/case/`, so regenerate the
drawings after committing a model change (a rebuild whose STL files and
measurements come out identical changes nothing).

The three drawing scripts (`draw_pinouts.py`, `draw_wiring.py`,
`draw_case.py`) are standard-library only and deterministic, so CI
regenerates their SVG files too and fails if they differ from the commit.

## CI and manufacturing packages

GitHub Actions (`.github/workflows/ci.yml`, KiCad 9.0.7 container) runs on
every push and pull request: it regenerates all boards (including zone fills)
and the SVG drawings and fails if the result differs from the commit, runs
ERC/DRC with schematic parity, and builds manufacturing packages with
`scripts/export_manufacturing.py`. Every push to `main` then publishes them:
the release attached to the most recent version tag is renamed to the build's
`git describe` (for example `v0.1-4-g93616a6`) and its assets replaced, so the
latest release always holds packages for the tip of `main`. CI creates no
tags; pushing a `vN.M` tag starts a new release the next time `main` is
built.

The packages cover the two adapter boards (the component boards are
reference models; pass their names to the script to export them too): one
zip per board for JLCPCB and one for NextPCB
(`<board>-<git describe>-<fab>.zip`: Gerber RS-274X with Protel extensions,
Excellon drill files and a README.txt of the size, stack-up and ordering
notes), plus `SHA256SUMS`. The boards' title blocks take their revision from
the same `git describe` string through the `GIT_DESCRIBE` text variable, which
the export defines at plot time.

```sh
uv run scripts/export_manufacturing.py --out dist              # same packages locally
uv run scripts/render_assemblies.py --no-render --export dist  # the STEP / GLB assemblies
uv run scripts/export_case.py --out dist                       # the printable case package
```

The release also carries the assembled adapters as STEP and GLB files (see
[3D models and case design](3d-models.md)) and the printable case as
`esp32c3-radio-adapter-case-<git describe>.zip`: the two STL files in print
orientation, the two case STEP models and a README.txt with the parts'
sizes, FDM print settings and how to order them from a 3D-printing service.
`scripts/export_case.py` builds it from the committed `hardware/case/*.stl`
and `hardware/3d/*case*.step` (CI has no CadQuery, so the case is not
rebuilt there) after checking that they exist, parse as STL and carry the
STEP header, copies the two STL files loose beside the zip, and adds them
all to `SHA256SUMS` and `RELEASE_NOTES.md`; it runs last because it appends
to what the other two scripts wrote.

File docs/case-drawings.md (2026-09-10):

# Case drawings

Mechanical drawings of the printed case for the socket adapter
(`hardware/case/`), for checking a printed part with calipers and as the
starting point for an injection-moulded or machined version. They are
drawn by `scripts/draw_case.py` from `scripts/case_dims.py`, the same
constants `scripts/build_case.py` builds the solids from, so the numbers on
the sheets cannot drift from the model. Every number on a sheet is tagged
with the name of the measurement `build_case.py` takes of the finished
solids (`hardware/case/esp32c3-radio-adapter-case-measured.json`), and
`uv run scripts/draw_case.py --check` reads the numbers back out of the
SVG files and compares them with those measurements (see
[Development](development.md)). The caliper checklist at the end of this
page is written by the same script.

Every sheet is in the adapter's frame: x right, y down from the PCB's
top-left corner, z up from the PCB's top face; the PCB is drawn in green
for reference. The datums the sheets and the checklist measure from are
the case's outside faces: A is the outside bottom face (z = -4.6), B the
USB-C wall's outer face (x = -4.5) and C the J4-end outer face (y = -2.7).
The four walls are named by what they carry: the USB-C wall (-x, the
case's left, with the window and plug recess), the antenna wall (+y, the
front), the J4 end (y = 0, the back, with the SuperMini and the pry notch)
and the plain wall (+x). The views are independent, each captioned with
its viewing direction, and not arranged in projection. The sheets are
sized in millimetres (2:1 for the views, 5:1 and 10:1 for the details), so
printed at 100 % they lay on the part, and each carries a scale bar. No
draft angles are modelled, and the only radii are the R2 vertical outside
corners; sheet 1 carries the tooling notes for a moulding or machining
engineer, and the other sheets the ones that bear on them.

The case's parting line is on the antenna axis (z = 3.3), so the antenna
hole and the USB-C window are each half in one half: the bottom half's
cut-outs cradle the connectors and the top half closes over them. The
title block's revision is the `git describe` of the last commit that
touched `hardware/case/` (the STL files and the measurements), so the
sheets name the model they were checked against and regenerating them on
a later commit changes nothing.

## Sheet 1: bottom half, plan from above

The cavity, the walls and the lip round the rim (gapped in the antenna
wall for the E07's jack body and across the USB-C plug recess, where the
top half's wall is full thickness), the four standoffs with their
press-fit pegs (the H3 peg is flush with the PCB), the two snap tabs on
each long wall with their slots, and the cut-outs that come down to the
seam: the USB-C window with its plug recess in the left wall, the E07
pocket and the half-hole in the antenna wall. Positions are given from
the datums; the section marks A-A and B-B (viewed from -x) and C-C and
D-D (viewed from +y) locate the other sheets.

Bottom half, plan from above

## Sheet 2: top half, plan from below

The top half turned over about its long axis, so +x runs to the left and
the USB-C wall is on the right: the skirt and its rebate (absent across
the plug recess), the grooves the bumps click into (hidden), the three
bored hold-down bosses over the pegs and the solid one beside H3, the pry
notch, the window head seen through the window, the half-hole in the
antenna wall, and where the slotted top's J4 slot would be.

Top half, plan from below

## Sheet 3: section A-A on the antenna axis

Both halves closed, cut at x = 12.67 (the antenna axis), viewed from -x
and laid out like the plan with y down the sheet, so z runs to the right:
the floor, seam and ceiling, the halves' heights, the standoff / peg /
boss stack at H2 and H4 behind the cut with the plain wall's lip, tabs
and rebate ceiling, the lip and the pry notch at the J4 end, the PCB
sectioned in green, and the antenna hole split by the seam with the E07
pocket under it in the bottom half.

Section A-A on the antenna axis

## Sheet 4: end elevations

The closed case's USB-C wall from outside (viewed from -x, the antenna end
on the right) with the window and the plug recess, both split by the
seam, dimensioned from datums A and C; and the antenna wall from outside
(viewed from +y, the USB-C wall on the left) with the hole centred on the
seam, dimensioned from A and B. Hidden detail is omitted; the seam is
drawn as an assembly edge.

End elevations: the USB-C wall and the antenna wall

## Sheet 5: the snap joint

Section C-C through a tab with the case closed at 10:1 (skirt, rebate,
clearance, tab, bump and groove, and how far the bump stands past the
skirt face), section D-D through the plain lip, both viewed from +y, and
a tab of the bottom half seen from outside (viewed from -x) at 5:1 with
its slots and the position of the top half's groove dashed for reference.

Snap joint details

## Sheet 6: the peg, PCB and boss stack

Section B-B through hole H1 at 5:1, viewed from -x, with every height from
datum A (floor top, standoff top, PCB top, peg tip, boss face, ceiling,
top face), the standoff's height (the floor to the PCB's underside, which
is the room the trimmed pin stubs have) and the local sizes (standoff,
peg and chamfer, PCB hole, bore, boss), and the same section at H3 where
the peg is flush and the solid boss sits 1 mm beside the hole. The PCB is
sectioned in green.

Peg, PCB and boss stack

## Sheet 7: the slotted top half

The second top half from above (the outside of the ceiling), with the slot
over J4 for jumper wires out of the closed case dimensioned from datums B
and C; otherwise it is sheet 2's top half.

The slotted top half, plan from above

## How to check a printed part

Measure in this order with 0.01 mm calipers (a depth rod for the depths),
outside first; the expected values are the model's and the tolerance is
what a well-tuned FDM printer holds. Anything outside it points at the
printer (first-layer squish, over-extrusion, shrinkage) before it points
at the model. Each depth names its reference surface: a caliper's base
rests on the highest thing under it, which on the bottom half is a tab
near the tab positions and the lip elsewhere (1.5 mm above the rim), and
on the top half the skirt's edge, which is on the seam plane. The rebate
cannot take a depth rod.

<!-- checklist:begin (written by scripts/draw_case.py) -->
Tolerances (the sheets' note): ±0.20 linear, ±0.10 on snap and peg
features, heights ±0.10 (half a 0.2 mm layer), each half printed as
supplied (open side up); the Ø2.60 boss bore is a minimum limit.
Every expected value below is one of the 73 that `--check` compares
with the measured solids.

| # | Measurement | Expected | Tolerance |
| --- | --- | --- | --- |
| 1 | Each half outside, width x length (calipers across the outside faces) | 36.20 x 66.70 | ±0.20 |
| 2 | Closed case height, outside bottom face (A) to the outside top face | 16.70 | ±0.10 |
| 3 | Bottom half: A to the wall's top (the rim, on the seam), beside a tab; tab tips above A | 8.40; 13.40 | ±0.10 |
| 4 | Top half: outside top face to the skirt's edge (on the seam); boss faces standing past the skirt's edge (straight edge across the skirt) | 8.30; 3.10 | ±0.10 |
| 5 | Vertical corner radius (radius gauge), each half | R2.00 | ±0.20 |
| 6 | Bottom half: long wall, back (J4 end) wall and antenna wall thickness at the rim, below the lip | 2.20; 2.20; 2.50 | ±0.20 |
| 7 | Bottom half: cavity, width x length, below the lip | 31.80 x 62.00 | ±0.20 |
| 8 | Bottom half: lip thickness; lip height above the rim | 0.80; 1.50 | ±0.10 |
| 9 | Bottom half: lip gaps, in the antenna wall (centred on the antenna axis) and in the USB-C wall (across the plug recess) | 8.40; 13.00 | ±0.20 |
| 10 | Bottom half: tab width; tab height above the rim; tab thickness through the bump; pitch of the two tabs | 8.00; 5.00; 1.15; 18.00 | ±0.10 |
| 11 | Bottom half: first tab's centre from the J4-end outside face (C); bump centre above the rim | 34.70; 4.30 | ±0.20 |
| 12 | Bottom half, depth rod with its base across both lips at y = 44 (section D-D, no tab there), the lips 1.50 above the rim: floor; standoff top; peg tip (H1, H2, H4); peg tip H3 | 7.90; 6.40; 4.40; 4.80 | ±0.10 |
| 13 | Bottom half: floor thickness (bottom half height less the floor depth from the rim) | 2.00 | ±0.10 |
| 14 | Bottom half: standoff diameter; standoff height, floor to the PCB's underside (the trimmed pin stubs' room); standoff pitch, across x along | 4.00; 1.50; 24.20 x 33.20 | ±0.20 |
| 15 | Bottom half: H1 standoff centre from the USB-C wall's outside face (B) and from the J4-end face (C) | 6.90; 5.10 | ±0.20 |
| 16 | Bottom half: peg diameter below the chamfer; peg above the standoff (H1, H2, H4); H3 | 2.15; 2.00; 1.60 | ±0.10 |
| 17 | Bottom half: USB-C window width; its sill below the rim; window centre from C | 10.00; 2.60; 17.30 | ±0.20 |
| 18 | Both halves: plug recess width; recess depth into the wall; wall left under it; recess bottom above A (bottom half) and top above A (top half) | 13.00; 1.00; 1.20; 3.95; 13.95 | ±0.20 |
| 19 | Bottom half: antenna half-hole width at the rim; its depth below the rim; centre from B; E07 pocket width; pocket depth into the wall; pocket floor below the rim | 6.60; 3.30; 17.17; 7.40; 0.60; 3.70 | ±0.20 |
| 20 | Top half: skirt thickness at its edge; between the skirt's inner faces | 1.25; 33.70 | ±0.10 |
| 21 | Top half: rebate height above the skirt's edge. No depth rod fits the 0.95 rebate: a strip of 0.80 card cut to this height should just enter it, or take it from the tab height plus the clearance over the tab | 5.30 (0.30 over the tab) | ±0.10 |
| 22 | Top half, depth rod with the base across the skirt's edge (on the seam plane): ceiling | 6.30 | ±0.10 |
| 23 | Top half: ceiling thickness (top half height less the ceiling depth) | 2.00 | ±0.10 |
| 24 | Top half: boss diameter; bore diameter (minimum); bore depth; solid boss diameter | 4.40; 2.60 min; 2.00; 3.00 | ±0.10 |
| 25 | Top half: groove centres from C (a pin in the groove, against a rule along the skirt); groove length | 34.70, 52.70; 9.00 | ±0.20 |
| 26 | Top half: USB-C window head above the skirt's edge; antenna half-hole depth above the skirt's edge | 3.70; 3.30 | ±0.20 |
| 27 | Top half: pry notch width; notch height above the skirt's edge; notch centre from B | 10.00; 1.20; 19.00 | ±0.20 |
| 28 | Slotted top half: J4 slot length x width; slot centre from B and from C | 18.78 x 3.54; 19.00, 5.25 | ±0.20 |
| 29 | Function: the PCB presses onto the pegs by hand and sits flat on the standoffs; the halves close with no gap at the seam and all four tabs click; the E07's jack, or the pigtail's bulkhead, passes the hole; a USB-C plug reaches the receptacle through the recess | - | - |
<!-- checklist:end -->

The snap fit (bump 0.35 into a 0.42 groove with 0.15 clearance) cannot be
measured with calipers; if the halves rattle or will not click, check the
lip, the tab thickness at the bump and the skirt first. FDM holes print
small and pegs print large, which is why the peg is drawn at 2.15 for a
2.20 hole: if the pegs will not go in, a touch with a 2.2 mm drill in the
PCB is better than shaving the peg.

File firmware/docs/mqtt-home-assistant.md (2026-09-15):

# MQTT integration and Home Assistant

How a CC1101/SX1278 node publishes decoded 433 MHz traffic to MQTT, how Home
Assistant turns that into entities, and how to receive commands back over MQTT.
This is the reference for goal criterion (e) — *"correctly publishing and
receiving messages with the Home Assistant MQTT setup"*.

> **Status (updated 2026-09-08).** Code + host tests are done and green
> (`firmware/tests/test_mqtt_shape.py` + `test_hass.py`, part of the 146-test suite).
> **Done on the real production broker (2026-09-09):** blue (CC1101) and sx (SX1278)
> are commissioned onto `ha.welland.mithis.com:1883`; the node's **native HA MQTT
> Discovery** (`CcHassDisc`, default on) self-publishes `homeassistant/sensor/.../config`
> + per-field state, and **Home Assistant auto-created 14 weather/moisture entities**
> (see [Live validation](#live-validation) and
> [`HWTEST-RESULTS-cc1101.md`](HWTEST-RESULTS-cc1101.md)). The per-node commissioning
> steps are under [Production rollout](#production-rollout) below.

## Architecture

The node runs stock Tasmota's MQTT client (built in — no custom networking). Two
things flow over MQTT:

- **Publish** — every decoded RF frame is emitted as **rtl_433-shaped JSON**, the
  same field names rtl_433 uses, so the standard Home Assistant rtl_433
  autodiscovery tooling recognises it without any per-device configuration.
- **Receive** — the node is driven by Tasmota commands (`Cc*`, `Sx*`, `Radio`,
  `CcRfSend`, `Secplus*`) which Tasmota accepts natively on `cmnd/<topic>/<Command>`
  and answers on `stat/<topic>/RESULT`.

There are two supported publish topologies, selected by the `CcHass` command:

```
  (A) aggregator-fronted (default, CcHass 0)
      node ── rtl_433/nodes/<host>/events ──▶ aggregator ── rtl_433/<site>/events ──▶ HA add-on (rtl_433/+/events)

  (B) direct to Home Assistant (CcHass 1)
      node ── rtl_433/<host>/events ─────────────────────────────────────────────▶ HA add-on (rtl_433/+/events)
```

The Home Assistant `rtl433-mqtt-autodiscovery` add-on subscribes to
`rtl_433/+/events`. MQTT's `+` matches **exactly one** topic level, so it matches
`rtl_433/<host>/events` (topology B) but **not** the four-level
`rtl_433/nodes/<host>/events` (topology A) — which is why topology A relies on the
site aggregator republishing each node's events to the three-level
`rtl_433/<site>/events`. Pick:

- **A (`CcHass 0`, default)** when the site already runs the project aggregator
  (it dedups/namespaces multiple nodes and republishes to HA). Preserves the
  original topic and the aggregator's per-node bookkeeping.
- **B (`CcHass 1`)** for a standalone node talking straight to HA's Mosquitto
  with no aggregator in between. The node's events are then discovered directly.

`CcHass` is persisted to `/cc1101.cfg` and changes only the **events** topic; the
tx-announce topic stays `rtl_433/nodes/<host>/tx` (it is not consumed by HA
autodiscovery). The exact topic string for the current setting is echoed back:

```
CcHass 1  ->  {"CcHass":1,"EventsTopic":"rtl_433/cc1101-welland-carport/events"}
CcHass    ->  {"CcHass":0,"EventsTopic":"rtl_433/nodes/cc1101-welland-carport/events"}
```

## Topic structure

`<host>` is Tasmota's **`Hostname`** (`NetworkHostname()`); `<topic>` is Tasmota's
**`Topic`**. Commission both to the same `cc1101-<site>-<place>` value (see
[Configuring a node](#configuring-a-node)).

| Direction | Topic (`CcHass 0` / `1`) | Payload |
|---|---|---|
| decoded events | `rtl_433/nodes/<host>/events` / `rtl_433/<host>/events` | rtl_433-shaped JSON — see [message schema](#decoded-event-message-schema) |
| tx announce (before keying, ~50 ms lead) | `rtl_433/nodes/<host>/tx` | `CcRfSend`/`SecplusSend` echo — see schema below |
| Tasmota remote result (OOK `remotes` decode) | `tele/<topic>/RESULT` | `{"RfReceived":{"Data":"0x00AABB","Bits":25,"Protocol":1,"Pulse":350,"RSSI":-61}}` |
| raw capture (`CcRaw 1`, bench only) | `tele/<topic>/CCRAW` | OOK: `{"Pulses":[350,-1050,...]}`; FSK undecoded: `{"Packet":"24AE...","RSSI":-84}` |
| driver status at TelePeriod | `tele/<topic>/SENSOR` | Tasmota SENSOR JSON with `"CC1101":{...}` appended |
| commands in | `cmnd/<topic>/<Command> <payload>` | see [Receiving commands](#receiving-commands-over-mqtt) |
| command replies | `stat/<topic>/RESULT` | JSON or plain reply per command |
| Tasmota availability | `tele/<topic>/LWT` | `Online` / `Offline` (retained; MQTT last-will) |

## Decoded event message schema

Every decoded frame is published to the events topic as one JSON object. The
driver wraps each decoder's output with three envelope fields, then the
decoder-specific fields follow verbatim:

| Envelope field | Type | Meaning |
|---|---|---|
| `time` | string | node local time, `YYYY-MM-DDTHH:MM:SS` (`GetDateAndTime(DT_LOCAL)`) |
| `receiver` | string | the node's `Hostname` — which node heard it |
| `rssi` | int | received signal strength, dBm |

Floating-point fields are rendered as real JSON numbers by `rf_ftoa` (fixed-point
integer formatting): the ESP32-C3 image links picolibc's integer-only `printf`,
which would otherwise render `%f` as the literal `*float*` and make the JSON
invalid. All decoders route their decimals through `rf_ftoa`, so
`temperature_C`, `wind_avg_m_s`, `rain_mm`, etc. arrive as `13.1`, not `*float*`.
(This is host-asserted in `test_mqtt_shape.py::test_wrap_event_float_field_is_numeric_not_star_float`.
The `*float*` note in the 2026-09-05 SX1278 row of `HWTEST-RESULTS-cc1101.md`
predates this fix — commit `4c85365`, later the same day — and is stale. A fresh on-air SX1278
capture was subsequently run (FIX-A, commit `eeea6f7`) and confirmed the
decimals render as real JSON numbers, not `*float*`.)

### Fineoffset WS69 / WH65B (weather station, family byte `0x24`)

`model` is `Fineoffset-WS69` for a 25-byte frame (with the pressure/UV/light
tail) or `Fineoffset-WH65B` for the 17-byte frame. Fields present only when the
sensor reports a valid value are marked *(if valid)*.

| Field | Type | Unit / notes |
|---|---|---|
| `model` | string | `Fineoffset-WS69` or `Fineoffset-WH65B` |
| `id` | int | 8-bit sensor id |
| `battery_ok` | int | 1 = OK, 0 = low |
| `temperature_C` | float (1 dp) | °C *(if valid)* |
| `humidity` | int | % RH *(if valid)* |
| `pressure_hPa` | float (2 dp) | hPa, WS69 tail only, if a barometer is fitted *(if valid; not yet cross-checked against a real barometer frame)* |
| `wind_dir_deg` | int | degrees *(if valid)* |
| `wind_avg_m_s` | float (1 dp) | m/s *(if valid)* |
| `wind_max_m_s` | float (1 dp) | m/s gust *(if valid)* |
| `rain_mm` | float (1 dp) | mm cumulative |
| `uv` | int | raw UV *(if valid)* |
| `uvi` | int | UV index 0–12 *(if valid)* |
| `light_lux` | float (1 dp) | lux *(if valid)* |
| `mic` | string | `CRC` — integrity check passed (CRC-8 poly 0x31 + additive sum) |

### Fineoffset WS85 (weather station, family byte `0x85`)

| Field | Type | Unit / notes |
|---|---|---|
| `model` | string | `Fineoffset-WS85` |
| `id` | int | 24-bit sensor id |
| `battery_ok` | int | 1 if battery > 2400 mV |
| `battery_pct` | int | 0–100 % |
| `battery_mV` | int | mV |
| `wind_dir_deg` | int | degrees *(if valid)* |
| `wind_avg_m_s` | float (1 dp) | m/s *(if valid)* |
| `wind_max_m_s` | float (1 dp) | m/s gust *(if valid)* |
| `flags` | int | raw status flags byte |
| `rain_mm` | float (1 dp) | mm |
| `rain_start` | int | rain-start flag |
| `supercap_V` | float (1 dp) | supercapacitor volts |
| `firmware` | int | sensor firmware byte |
| `mic` | string | `CRC` |

> WS85 is not audible at Welland (its frame is longer than the CC1101's 25-byte
> fixed packet), so on the CC1101 path this branch is validated by the decoder
> host test only; the SX1278 path (30-byte packet) can receive it. See the
> node doc's *Fine Offset FSK* sections.

### Fineoffset WH51 (soil moisture, family byte `0x51`)

| Field | Type | Unit / notes |
|---|---|---|
| `model` | string | `Fineoffset-WH51` |
| `id` | string | 24-bit id, lowercase hex e.g. `"0f5c54"` |
| `battery_ok` | float (1 dp) | rtl_433 coarse level 0.0–1.0 (alkaline-AA ladder), **not** a 0/1 flag |
| `battery_mV` | int | mV (5-bit reading × 100) |
| `moisture` | int | % |
| `boost` | int | TX-period boost bits |
| `ad_raw` | int | 9-bit raw ADC behind the moisture % |
| `mic` | string | `CRC` |

### OOK-PWM remotes (`remotes` mode)

| Field | Type | Notes |
|---|---|---|
| `model` | string | `OOK-PWM` |
| `family` | string | timing family: `standard` or `fixed-period` |
| `bits` | int | decoded bit count |
| `code` | string | packed code, hex |
| `short_us` | int | measured short mark, µs |
| `long_us` | int | measured long mark, µs |
| `gap_us` | int | inter-packet gap, µs |

The same OOK frame is **also** published as a Tasmota `RfReceived` result on
`tele/<topic>/RESULT` (Sonoff-bridge-compatible `Data`/`Bits`/`Protocol`/`Pulse`/`RSSI`).
See the "known limitation" on the reported bit count for RCSwitch-1 remotes in
[`../README.md`](../README.md) → *MQTT topics* and the driver comment on
`CcPublishRfReceived`.

### Security+ 2.0 (`Secplus-v2`)

| Field | Type | Notes |
|---|---|---|
| `model` | string | `Secplus-v2` |
| `id` | int | 36-bit transmitter id (masked `0xF0FFFFFFFF`) |
| `button` | int | 0–15 |
| `rolling` | int | rolling counter |
| `fixed` | int | full 40-bit fixed field |
| `data` | int | present only for the 64-bit frame type |

### tx-announce payloads

Published to `rtl_433/nodes/<host>/tx` ~50 ms before the radio keys:

- `CcRfSend`: `{"Data":"0x00AABB","Bits":24,"Protocol":1,"Pulse":350,"model":"OOK-PWM","code":"00aabb"}`
- `SecplusSend`: `{"model":"Secplus-v2","id":12345,"button":1,"rolling":843,"fixed":...}`

## Home Assistant setup (native MQTT Discovery)

The node **self-publishes Home Assistant MQTT Discovery** for every sensor it
decodes, so HA creates the entities natively with **no rtl_433 add-on, aggregator,
or per-device YAML**. This is the default (`CcHassDisc 1`); the byte-shaping is in
`cc1101_node/cc1101_hass.c` (host-tested by `tests/test_hass.py`).

On each decoded weather/moisture frame the node publishes, keyed by `model` + `id`:

1. **Per-field state**, retained, one topic per value:

   ```
   rtl_433/nodes/<host>/devices/<model>/<id>/<field>   payload = the raw value
   e.g. rtl_433/nodes/esp32-433mhz-cc1101-blue/devices/Fineoffset-WS69/174/temperature_C = 12.4
   ```

2. **A discovery config**, retained, once per `(model,id)` per boot:

   ```
   homeassistant/sensor/<model>-<id>/<model>-<id>-<field>/config
   {"name":"Temperature","uniq_id":"Fineoffset-WS69-174-temperature_C",
    "stat_t":"rtl_433/nodes/<host>/devices/Fineoffset-WS69/174/temperature_C",
    "dev_cla":"temperature","unit_of_meas":"°C","stat_cla":"measurement",
    "val_tpl":"{{ value|float|round(1) }}",
    "avty_t":"tele/<host>/LWT","pl_avail":"Online","pl_not_avail":"Offline",
    "dev":{"ids":["Fineoffset-WS69-174"],"name":"Fineoffset-WS69 174",
           "mdl":"Fineoffset-WS69","mf":"Fine Offset"}}
   ```

Each field has its **own** state topic (not the shared `events` JSON), so a WH51
message never clobbers a WS69 entity, and two sensors of the same model (e.g. two
WH51 units) each become their own HA device. HA does unit conversion from the
`device_class` (wind `m/s` is shown as the dashboard's `km/h`, etc.). The config
publish is gated on `MqttIsConnected()`: the radio decodes within ~1 s of boot,
before WiFi/MQTT are up, so the guard stops that first config being dropped while
the sensor is nonetheless marked "seen".

Fields mapped to HA metadata (`cc1101_hass.c` table): `temperature_C`, `humidity`,
`moisture`, `wind_avg_m_s`, `wind_max_m_s`, `wind_dir_deg`, `rain_mm`,
`battery_mV`, `battery_pct`, `supercap_V`.

**Verified on real hardware (ha.welland):** blue (CC1101) and sx (SX1278) decoding
the same sensors produced 10 auto-created HA entities — WS69 temperature/humidity/
wind speed/gust/direction/rain and two WH51 moisture + battery — with live values.

`CcHassDisc 0` disables the discovery publisher (leaving only the `events` topic
below). Turn it back on with `CcHassDisc 1`.

### Alternative: the raw events topic + rtl_433 add-on

Independently of discovery, the node always publishes the full rtl_433-shaped
event JSON (schema above) to an `events` topic, for estates that already run the
`rtl_433_mqtt_hass.py` add-on / an aggregator against `rtl_433/+/events`:

- **Topology A (aggregator present):** leave `CcHass 0` → `rtl_433/nodes/<host>/events`;
  the aggregator republishes to `rtl_433/<site>/events`.
- **Topology B (direct):** `CcHass 1` → `rtl_433/<host>/events`, which the add-on's
  `rtl_433/+/events` subscription sees directly.

`CcHass` selects only the *events* topic layout; it is independent of `CcHassDisc`
(the native discovery publisher).

## Receiving commands over MQTT

Every driver command works identically over MQTT and the USB/web console. Over
MQTT: publish to `cmnd/<topic>/<Command>` with the argument as the payload; the
reply arrives on `stat/<topic>/RESULT`. Examples (`mosquitto_pub`):

```bash
# query the radio
mosquitto_pub -h ha.welland.mithis.com -u <user> -P <pass> \
  -t 'cmnd/cc1101-welland-carport/CcStatus' -n
#   -> stat/cc1101-welland-carport/RESULT  {"CcStatus":{"Present":1,...,"Hass":0,...}}

# set the node's role
mosquitto_pub ... -t 'cmnd/cc1101-welland-carport/CcMode' -m 'weather'

# switch to direct-HA events topic
mosquitto_pub ... -t 'cmnd/cc1101-welland-carport/CcHass' -m '1'

# transmit an OOK remote code
mosquitto_pub ... -t 'cmnd/cc1101-welland-carport/CcRfSend' \
  -m '{"Data":"0x00AABB","Bits":24,"Pulse":350,"Repeat":5}'

# radio selection / SX1278 register read
mosquitto_pub ... -t 'cmnd/cc1101-welland-carport/Radio' -m 'sx1278'
mosquitto_pub ... -t 'cmnd/cc1101-welland-carport/SxReg'  -m '0x42'
```

Full command syntax and replies are in [`../README.md`](../README.md) →
*Command reference* and *Radio selection*. The complete command set reachable
over `cmnd/`: `CcMode`, `CcPreset`, `CcReg`, `CcStatus`, `CcRaw`, `CcHass`,
`CcRfSend`, `SecplusId`, `SecplusCounter`, `SecplusFreq`, `SecplusSend`,
`SxStatus`, `SxReg`, `SxReset`, `Radio` (plus all stock Tasmota commands).

## Configuring a node

Set these once at commissioning (over the USB/web console, or later over MQTT):

| Setting | Command | Example |
|---|---|---|
| WiFi | `Backlog SSID1 <ssid>; Password1 <pass>` (or the captive portal) | — |
| Broker host/port | `MqttHost` / `MqttPort` | `MqttHost ha.welland.mithis.com` |
| Broker user/pass | `MqttUser` / `MqttPassword` | `MqttUser cc1101-node` |
| MQTT topic (drives `cmnd/tele/stat`) | `Topic` | `Topic cc1101-welland-carport` |
| Hostname (drives `rtl_433/.../events`) | `Hostname` | `Hostname cc1101-welland-carport` |
| Radio role | `CcMode` | `CcMode weather` |
| Events topology | `CcHass` | `CcHass 1` (direct) or `0` (aggregator, default) |

Set `Topic` and `Hostname` to the **same** value — the driver does not enforce it,
and if they diverge the `rtl_433/.../events` name and the `tele/…` name for the
same node will not match, confusing the aggregator's per-node bookkeeping (see
[`../README.md`](../README.md) → *MQTT topics*).

Confirm the broker connection: `tele/<topic>/LWT` should read `Online`
(retained), and `MqttHost` / `Status 6` echo the configured broker.

## Live validation

**On the real production broker (`ha.welland.mithis.com`): DONE (2026-09-09).** blue
(CC1101, `esp32-433mhz-cc1101-blue`) and sx (SX1278, `esp32-433mhz-sx1278`) are commissioned
onto `ansells-iot` + the production `ha.welland.mithis.com:1883` Mosquitto broker (per-device
`tas-<node_id>` logins). Both connect (`MqttCount>=1`, retained `tele/<host>/LWT Online`),
decode the local Fine Offset WS69 (weather) and WH51 (soil moisture) sensors — to identical
values, cross-validating each other on-air — and publish:

- the rtl_433-shaped **events** JSON to `rtl_433/nodes/<host>/events`;
- **native HA MQTT Discovery** (this firmware, `CcHassDisc` default on): per-field state +
  `homeassistant/sensor/.../config`. **Home Assistant auto-created 10 live entities**,
  confirmed via the HA states API: `sensor.fineoffset_ws69_174_{temperature, humidity,
  wind_speed, wind_gust, wind_direction, rain}` and two WH51 `{moisture, battery_voltage}` —
  with HA unit-converting wind m/s -> the dashboard's km/h from the `wind_speed` device_class.
- Tasmota's own `tasmota/discovery/<mac>/config` (`SetOption19`) additionally surfaces each
  **node** in HA (14 entities/node); that is the device itself, separate from the sensor
  entities above.

A `cmnd/<topic>/CcStatus` -> `stat/<topic>/RESULT` command round-trip and the `tele/SENSOR`/
`STATE`/`LWT` publishes were confirmed on the same broker.

**Dual-receiver note.** A sensor's discovery config is keyed by `model`+`id`, so one physical
sensor is one HA device (not one per receiver). Its `stat_t`/`avty_t`, however, name a single
node. If two nodes hear the *same* sensor (e.g. a bench with both boards side by side), the
last config published wins and the entity tracks that node's state topic and LWT availability.
The intended topology is one node covering a given sensor's area; geographically separated
nodes (the normal case) decode disjoint sensor sets and never collide.

**Earlier isolated validation (2026-09-08), superseded but retained for the add-on path.**
Before the real-broker rollout, the publish/receive round-trip and the *alternative* rtl_433
add-on discovery path were validated against a local `mosquitto 2.0.21` on an isolated NAT
hotspot: blue (`CcHass 0`) -> `rtl_433/nodes/<host>/events` -> the project aggregator
(`rf433_aggregate.py`, `site=test`) -> `rtl_433/test/events` -> `rtl_433_mqtt_hass.py` ->
**22 `homeassistant/sensor/.../config`** entity configs (WS69 incl. uv/uvi/lux/rssi, WH51). That
add-on path remains an alternative for estates already running the add-on, but is **not**
required now that the node self-publishes discovery. Full captures are in
[`HWTEST-RESULTS-cc1101.md`](HWTEST-RESULTS-cc1101.md) ("MQTT round-trip" section).

### Production rollout

Connecting to the real HA broker is **done for blue + sx** (the runs above). The same
two inputs are needed to commission each additional node:

1. **WiFi** — SSID + passphrase for the `ansells-iot` network the node joins.
2. **MQTT broker credential** — the per-device `tas-<node_id>` Mosquitto login on
   `ha.welland.mithis.com:1883`, created and pushed by
   `gdoc2netcfg tasmota configure <host>` + `gdoc2netcfg tasmota register-broker`
   (derives `username=tas-<node_id>`, `password=sha256(mqtt_secret + node_id)`), after the
   device is added to the IoT sheet and discovered by `gdoc2netcfg tasmota scan`.

To run the production check manually on a flashed node with a working radio:

```bash
# 1. Commission (USB/web console)
Backlog SSID1 <ssid>; Password1 <wifi-pass>
Backlog MqttHost ha.welland.mithis.com; MqttPort 1883; MqttUser <user>; MqttPassword <pass>
Backlog Topic cc1101-welland-carport; Hostname cc1101-welland-carport
CcMode weather        # or: remotes
CcHass 1              # direct-to-HA topic, so rtl_433/+/events sees it

# 2. Confirm the broker connection (from any host with mosquitto-clients)
mosquitto_sub -h ha.welland.mithis.com -u <user> -P <pass> -v \
  -t 'tele/cc1101-welland-carport/LWT'
#   expect: tele/cc1101-welland-carport/LWT Online

# 3. Watch the node publish a decoded event (trigger a real WH51/WS69 nearby,
#    or bench a sensor). Expect an rtl_433-shaped JSON line:
mosquitto_sub -h ha.welland.mithis.com -u <user> -P <pass> -v -t 'rtl_433/#'
#   expect e.g.:
#   rtl_433/cc1101-welland-carport/events {"time":"...","receiver":"cc1101-welland-carport","rssi":-84,"model":"Fineoffset-WH51","id":"0f5c54","battery_ok":1.0,"battery_mV":1600,"moisture":40,"boost":0,"ad_raw":208,"mic":"CRC"}

# 4. Confirm Home Assistant auto-created the entities:
#    - the rtl433-mqtt-autodiscovery add-on log shows a discovery config for
#      model=Fineoffset-WH51 id=0f5c54 (and WS69 etc.);
#    - HA Settings -> Devices & Services -> Entities shows a moisture sensor and
#      a battery sensor for that id, updating as events arrive.

# 5. Confirm the RECEIVE path (command over MQTT):
mosquitto_pub -h ha.welland.mithis.com -u <user> -P <pass> -n \
  -t 'cmnd/cc1101-welland-carport/CcStatus'
mosquitto_sub -h ha.welland.mithis.com -u <user> -P <pass> -v \
  -t 'stat/cc1101-welland-carport/RESULT'
#   expect: stat/.../RESULT {"CcStatus":{"Present":1,...,"Hass":1,...}}
```

Record the outcome (broker connect, an events publish seen on
`rtl_433/#`, the HA entity created, and a `cmnd`→`stat` round-trip) in
[`HWTEST-RESULTS-cc1101.md`](HWTEST-RESULTS-cc1101.md).

## Host tests

`firmware/tests/test_mqtt_shape.py` builds the pure-C shaping helpers into
`libfirmware.so` and asserts, off-target:

- both events topics (aggregator + direct) are byte-exact;
- the direct topic matches `rtl_433/+/events` while the aggregator topic does not
  (and vice-versa for `rtl_433/nodes/+/events`);
- the tx topic string;
- a wrapped event built from a **real** WH51 decode is valid JSON with the
  `time`/`receiver`/`rssi` envelope and the decoder fields intact;
- a WS69 float field survives as a numeric value (not `*float*`);
- topic/JSON buffer truncation is reported as an error, not a silent partial.

These do **not** exercise the Tasmota glue (`MqttPublishPayload`, `Hostname`) —
that only compiles inside the full PlatformIO build (`firmware/build.py`) and is
covered by the live procedure above.

## See also

- [`../README.md`](../README.md) — command reference, MQTT topics, `/cc1101.cfg`.
- [`esp32c3-cc1101-node.md`](esp32c3-cc1101-node.md) — wiring, decoders, FSK config.
- [`HWTEST-RESULTS-cc1101.md`](HWTEST-RESULTS-cc1101.md) — on-hardware log (record the live MQTT result here).

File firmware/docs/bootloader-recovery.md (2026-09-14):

# Bootloader / USB recovery and boot-safety hardening — ESP32-C3 + CC1101 node

The radio nodes appeared "dark" (never running the app). This document records the **confirmed
root cause**, the design fix, why the firmware cannot block USB/ROM recovery, and the recovery
procedure.

> ## Root cause — CONFIRMED on hardware (2026-09-06)
>
> The nodes were **not** power-cut bricks, and they were **not** presenting "no USB." They were
> booting straight into **ROM USB download mode every power-up** and sitting there forever (the
> ESP32-C3 ROM samples the BOOT strap once at reset; if low it enters download mode with **no
> timeout** and never runs the app). So they enumerated as `303a:1001` but never ran Tasmota.
>
> **Why:** the original socket adapter routed the position-4 SPI signal (CC1101 **CSN** / green
> **SCK** / RA-02 **NSS**) to **GPIO9**, which is the ESP32-C3 **BOOT** strapping pin. At reset the
> ESP drives nothing, so GPIO9 rises only through its ~45 kΩ internal pull-up; the radio's input
> capacitance on that net slows the rise so GPIO9 is still below V_IH when the ROM samples the
> strap → download mode. It is a **slow-rise-at-reset**, not a static pull-down (measured: GPIO9
> reads high at rest with only the internal pull-up) and not the SPI idle level (that is post-boot).
>
> **Evidence:** on node `4F:D8`, with `FORCE_DOWNLOAD_BOOT`=0 and BOOT released, every reset lands
> in `boot:0x5 DOWNLOAD`; a radio-less reference board under the identical reset lands in
> `boot:0xd SPI_FAST_FLASH_BOOT` and runs its app. (An earlier in-session claim of confirmation via
> a `uhubctl` power-cycle was **invalid** — the Genesys hub is ganged/self-powered, so the cycle
> re-enumerated USB without cutting VDD; an RTC-memory marker survived it, proving power never
> dropped. The clean reset above, on the same controller, is the valid test.)
>
> **Fix (both, per design decision):** (1) adapter rev moves position-4 off GPIO9 to **GPIO1**
> (a non-strapping pin); GPIO9 becomes an unconnected spare. (2) optional pull-up footprints on the
> strap pins so they latch high at reset. Firmware pin maps updated to GPIO1 and a compile-time
> guard now rejects any map using a strapping pin (GPIO2/8/9) — see `src/xdrv_95_cc1101.ino`.
> On-hardware re-validation of the GPIO1 rev is pending the rewire.
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

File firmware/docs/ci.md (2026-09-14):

# Firmware CI

`.github/workflows/firmware.yml` runs on every push and pull request. It is
separate from `ci.yml` (which verifies the KiCad boards and builds the
manufacturing packages); the two do not share jobs.

## What it tests

The workflow has three independent jobs:
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

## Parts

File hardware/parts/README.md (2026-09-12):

# Component boards

Reference reproductions of the commercial boards the adapters are built
around. Each project reproduces the outline, pin headers, castellations,
mounting holes and connector positions of the original, so the adapters'
footprints could be checked against photos and datasheets.

They are documentation, not boards to order. Each one has a README with the
product's dimensions, pinout, where to buy it and the sources every number
came from.

| | Board | What it is |
| --- | --- | --- |
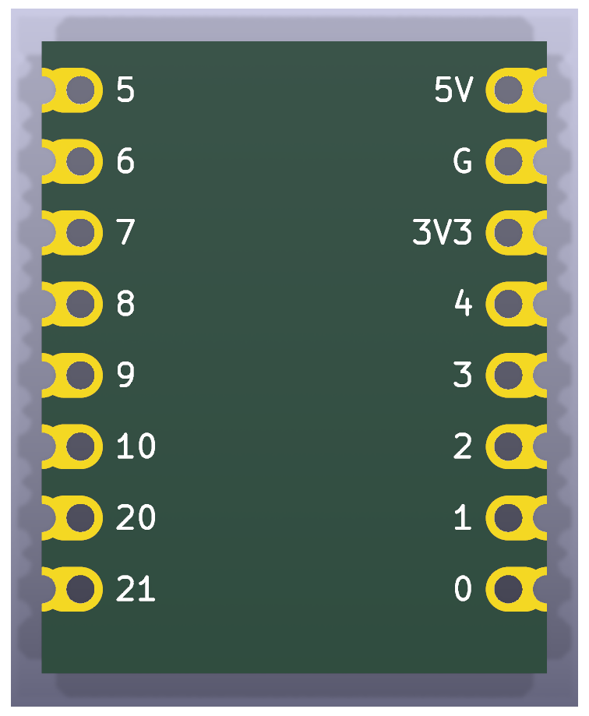
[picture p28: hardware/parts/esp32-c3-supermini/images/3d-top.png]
|  | [**ESP32-C3 SuperMini**](esp32-c3-supermini/) | The ESP32-C3 board every adapter here is built around: 18&nbsp;x&nbsp;22.5 mm, USB-C, eight castellated pins per side. |
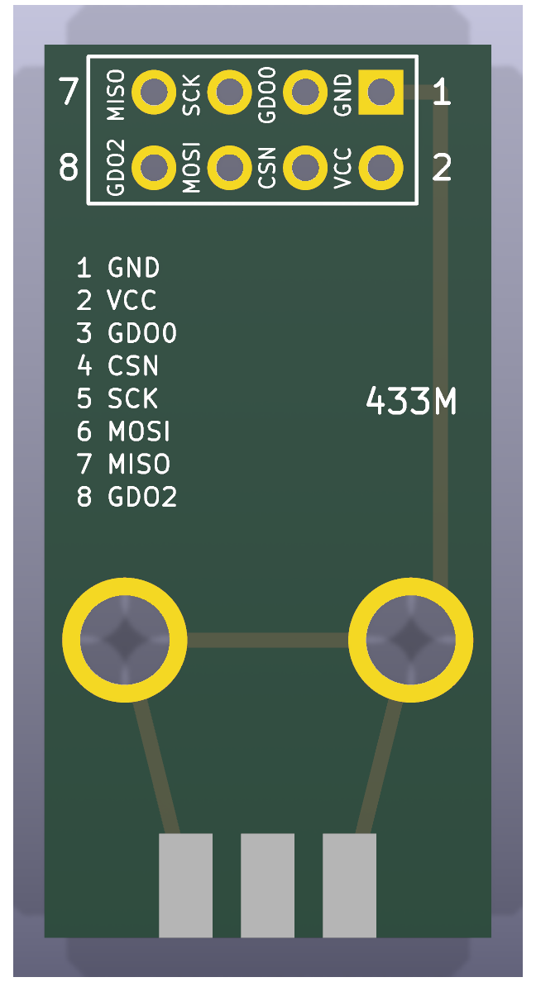
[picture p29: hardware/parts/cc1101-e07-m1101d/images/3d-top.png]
|  | [**CC1101 E07-M1101D-SMA**](cc1101-e07-m1101d/) | Blue Ebyte CC1101 radio, 15&nbsp;x&nbsp;30 mm, 2x4 header at one end and an SMA jack at the other. |
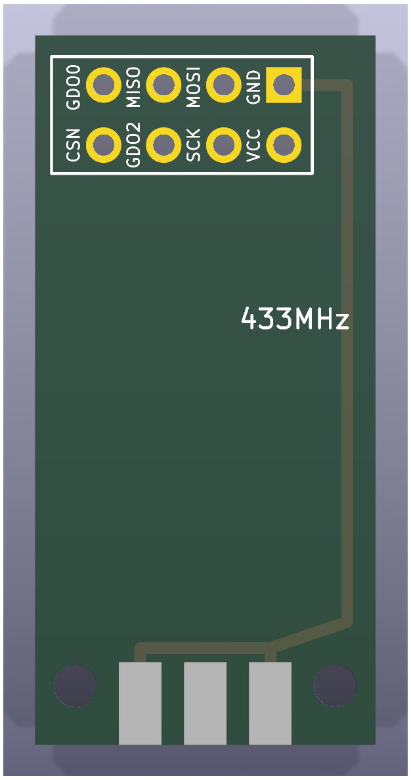
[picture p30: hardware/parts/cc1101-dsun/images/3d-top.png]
|  | [**CC1101 D-Sun**](cc1101-dsun/) | Green CC1101 radio, 14.4&nbsp;x&nbsp;30 mm: the same signals as the E07 in a different header order. |
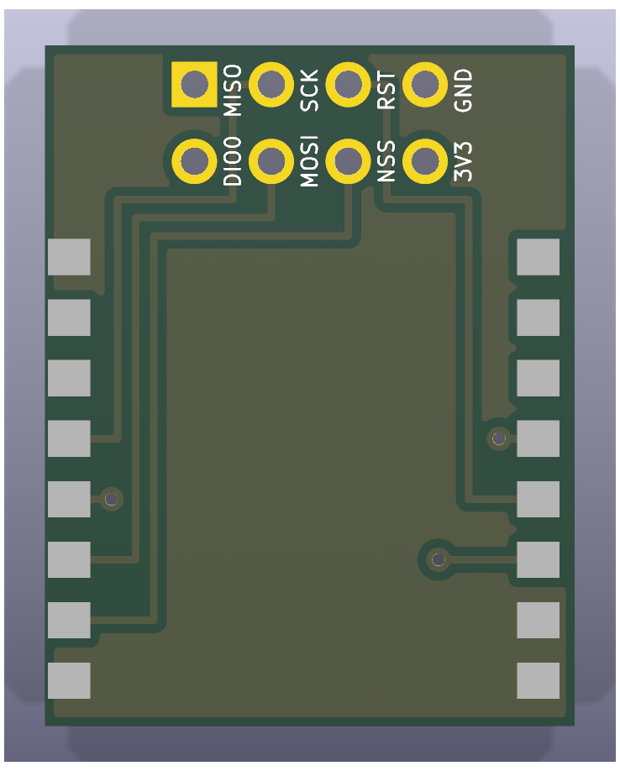
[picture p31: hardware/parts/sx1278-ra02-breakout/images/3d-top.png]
|  | [**SX1278 Ra-02 breakout**](sx1278-ra02-breakout/) | Blue LoRa breakout, 17.5&nbsp;x&nbsp;22.5 mm: an Ai-Thinker Ra-02 with an IPEX antenna on a 2x4 header. |
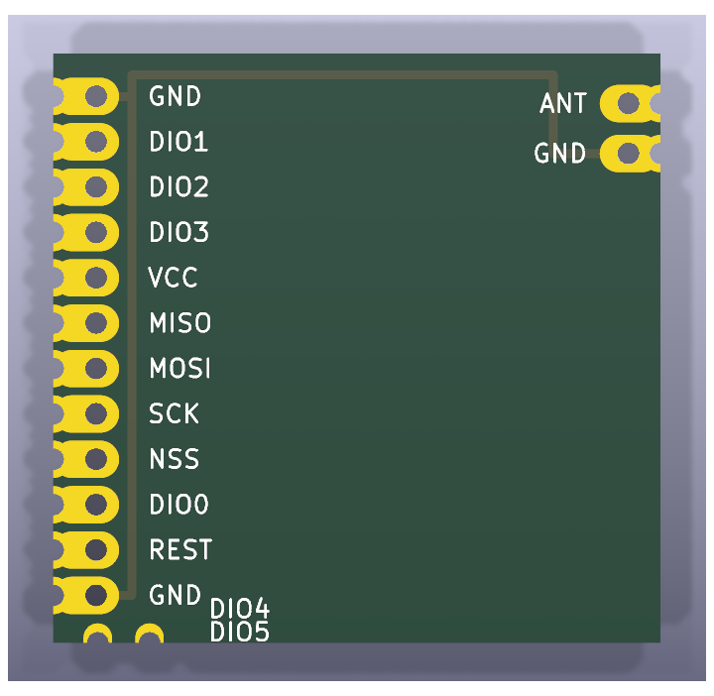
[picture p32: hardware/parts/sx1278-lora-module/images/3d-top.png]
|  | [**SX1278 LoRa module**](sx1278-lora-module/) | 16-pin castellated LoRa module, 17&nbsp;x&nbsp;16.5 mm, with no header: it solders flat onto the [SX1278 module adapter](../esp32c3-sx1278-adapter). |

The first four plug into, or carry, the socket on the
[main adapter](../esp32c3-radio-adapter).

CI does not build these projects; pass a name to
`scripts/export_manufacturing.py` to export one, and see
[docs/development.md](../../docs/development.md) for how they and their
images are regenerated.

## Castellations in KiCad

KiCad has no native castellated pad. Each castellation is a through-hole pad
whose drill is centred on the board edge; the fab cuts the plated hole in
half. On the SuperMini and the SX1278 module each pin is two pads sharing a
number: the through-hole inboard and the half-hole on the edge, joined by oval
copper.

KiCad flags copper and holes touching the board edge, so each project's
`.kicad_dru` ignores edge clearance and relaxes the hole-to-hole distance for
the edge-pad footprints only. Order the boards with the "castellated holes"
option at your PCB fab.

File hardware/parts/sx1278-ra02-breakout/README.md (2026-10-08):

# SX1278 Ra-02 breakout

The blue "SX1278 LoRa 433MHz v4.0" breakout: an Ai-Thinker Ra-02 LoRa module
(IPEX antenna) on a 17.5&nbsp;x&nbsp;22.5 mm carrier with a 2x4 2.54 mm male header on
its back. A KiCad reproduction of it lives in this directory; see
[the parts index](../README.md) for what these reproductions are for.

| 3D render, top | 3D render, bottom | Layout (copper, silk, fab, outline) |
| --- | --- | --- |
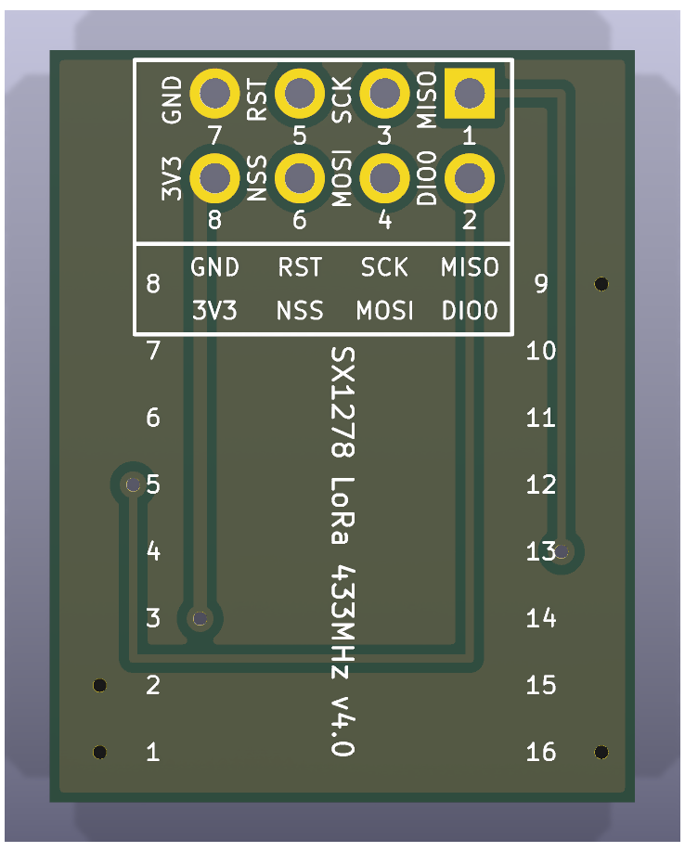
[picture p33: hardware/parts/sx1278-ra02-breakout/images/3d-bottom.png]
3D render of the bottom side
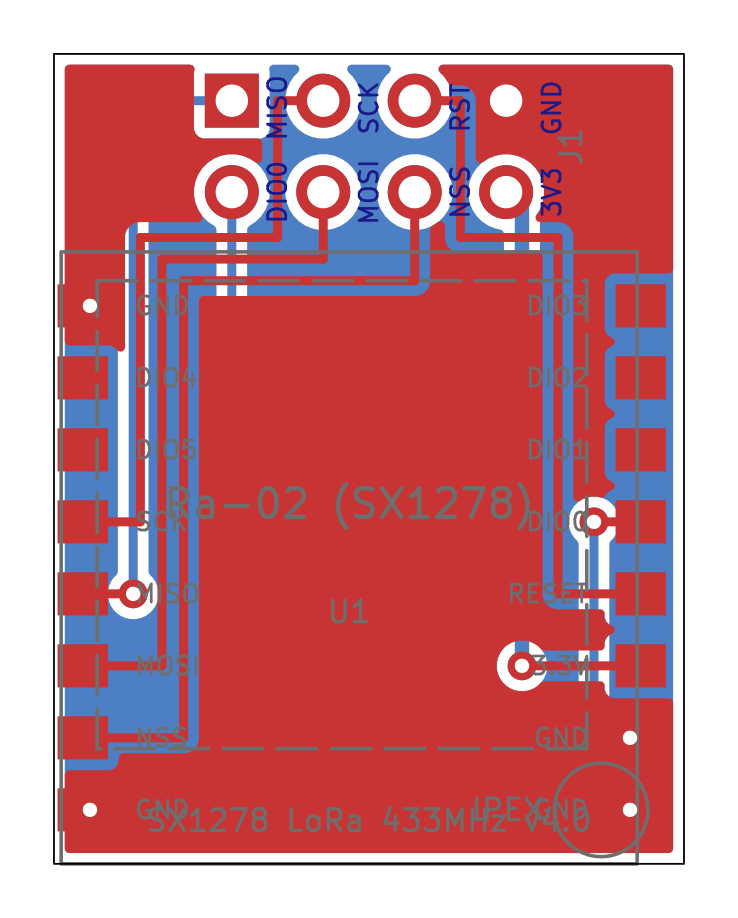
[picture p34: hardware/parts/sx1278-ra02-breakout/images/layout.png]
2D layout plot
| 3D render of the top side |  |  |

Drawn as seen from the Ra-02 side with the header edge at the top, the way it
sits on the adapter.

## Buying one

| | |
| --- | --- |
| Buy | [SX1278 LoRa 433MHz Ra-02](https://www.aliexpress.com/w/wholesale-sx1278-lora-433mhz-ra-02.html) |
| Module datasheet | [Ai-Thinker Ra-02](https://docs.ai-thinker.com/en/Ra-02/index.html) |
| How to recognise it | Blue 17.5&nbsp;x&nbsp;22.5 mm carrier with the Ai-Thinker Ra-02 can on top, 2x4 header underneath, silk "SX1278 LoRa 433MHz v4.0" |
| Also needs | A [U.FL (IPEX) to SMA pigtail](https://www.aliexpress.com/w/wholesale-ipex-to-sma-pigtail.html) plus a [433 MHz SMA antenna](https://www.aliexpress.com/w/wholesale-433mhz-sma-antenna.html). It has no SMA jack of its own. |

It plugs into the [radio socket](../../esp32c3-radio-adapter) on the adapter
board, sharing it with the [E07-M1101D](../cc1101-e07-m1101d) and the
[D-Sun CC1101](../cc1101-dsun). For raw OOK its demodulated bitstream is only
on DIO2, which the adapter brings out on a fly-wire header; see the
[design notes](../../../docs/design-notes.md). DIO2 is not on this board's
header at all, so it needs a wire soldered to the module:
[Adding the DIO2 wire](dio2-wire.md) says which pad and how to prove the wire
landed on it.

## Dimensions and pinout

| Feature | Value | Source |
| --- | --- | --- |
| Outline | 17.5&nbsp;x&nbsp;22.5 mm | photos, scaled by the header pitch (+/- 0.3 mm) |
| Header | 2x4, outer row 1.3 mm from the header edge, columns centred | photos |
| Header pinout | outer row MISO, SCK, RST, GND; inner row DIO0, MOSI, NSS, 3V3 (left to right) | back-side silk in the photos |
| Ra-02 module | 17&nbsp;x&nbsp;16&nbsp;x&nbsp;3.2 mm, 16 castellations at 2.0 mm on the 17 mm edges, first 1.5 mm from the end | Ai-Thinker Ra-02 Specifications V1.0, section 3 |
| Ra-02 pins | 1-8 GND, GND, 3.3V, RESET, DIO0, DIO1, DIO2, DIO3 up the right edge from the IPEX corner; 9-16 GND, DIO4, DIO5, SCK, MISO, MOSI, NSS, GND down the left edge | Ra-02 Specifications V1.0, section 4 |
| IPEX | 1.5 / 1.0 mm from the pin-1 corner (bottom-right here) | Ra-02 Specifications V1.0, section 3 |

The ESP32 GPIO each header pin lands on is in the
[pin map for firmware](../../../README.md#pin-map-for-firmware).

## The reproduction

3D model of the reproduction with the product's parts on it

The header is numbered here like the `Conn_02x04_Odd_Even` symbol (odd pins
in the outer row, pin 1 at the left). Copper reproduces the connections:
four header nets run on the front and three (MISO, DIO0, 3V3) cross on the
back through vias, as the real board does (its back-side trace from the 3V3
header pin ends at a via exactly where module pin 3 sits, which is what
fixed the module's orientation). Both sides carry a GND pour. The back silk
carries the header's pin numbers and name grid and the Ra-02's pin numbers
beside each land; the header names also appear on both sides beside each
column. The breakout's two decoupling capacitors are not modelled, and the
module lands are drawn 1.4&nbsp;x&nbsp;1.2 mm.

Regenerate the project with `uv run scripts/generate_ra02_breakout.py`, and
its images with `uv run scripts/render_boards.py sx1278-ra02-breakout` and
`uv run scripts/render_assemblies.py parts`.

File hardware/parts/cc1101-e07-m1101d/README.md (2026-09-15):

# CC1101 E07-M1101D-SMA

The Ebyte E07-M1101D-SMA (PCB marked "E07-M1101D V2.0"), sold as the "TENSTAR
CC1101 433MHz Wireless Module" with an SMA antenna. A KiCad reproduction of it
lives in this directory; see [the parts index](../README.md) for what these
reproductions are for.

| 3D render, top | 3D render, bottom | Layout (copper, silk, fab, outline) |
| --- | --- | --- |
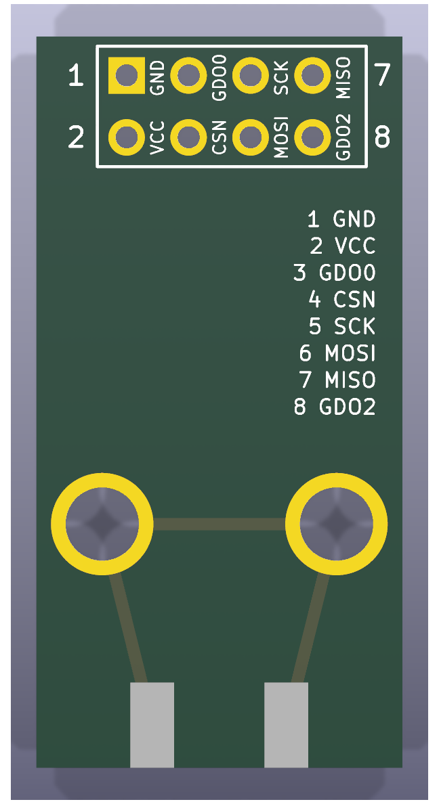
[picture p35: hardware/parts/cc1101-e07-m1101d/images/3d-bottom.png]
3D render of the bottom side
| 3D render of the top side |  | 2D layout plot |

## Buying one

| | |
| --- | --- |
| Buy | [E07-M1101D](https://www.aliexpress.com/w/wholesale-e07-m1101d.html), also sold as "TENSTAR CC1101 433MHz wireless module". Ebyte make two: take the **-SMA**, which this page documents, not the -TH, whose spring antenna solders straight to the board -- that search leads with the -TH |
| Product page | [Ebyte E07-M1101D-SMA](https://www.cdebyte.com/products/E07-M1101D-SMA) |
| How to recognise it | Blue, 15&nbsp;x&nbsp;30 mm, 2x4 header at one end, SMA jack at the other, PCB marked "E07-M1101D V2.0" |
| Also needs | A [433 MHz SMA antenna](https://www.aliexpress.com/w/wholesale-433mhz-sma-antenna.html) (often included). Not the 868/915 MHz one many listings bundle with the same radio. |

It plugs into the [radio socket](../../esp32c3-radio-adapter) on the adapter
board, sharing it with the [D-Sun CC1101](../cc1101-dsun) and the
[SX1278 Ra-02 breakout](../sx1278-ra02-breakout).

## Dimensions

All values in millimetres, viewed from the component side with the header at
the top and the SMA jack at the bottom.

| Feature | Value |
| --- | --- |
| Board outline | 15.0&nbsp;x&nbsp;30.0 |
| Header | 2&nbsp;x&nbsp;4, 2.54 pitch, 1.50 pads (pin 1 square), 0.90 holes |
| Header position | outer row 1.60 from the header edge, columns 3.70 from the long edges |
| Header numbering | outer row 7 5 3 1 left to right, inner row 8 6 4 2 |
| Mounting holes | 3.00 plated, 4.20 pad, 2.70 from each long edge, 10.0 from the SMA edge |
| SMA jack | edge mount, centred on the bottom edge; ground legs 2.75 either side (5.5 apart, measured from photos) |
| Board thickness | 1.6 (edge-mount SMA) |

## Pinout

Pin names (J1):

| Pin | Name | Pin | Name |
| --- | --- | --- | --- |
| 1 | GND | 5 | SCK |
| 2 | VCC (1.8 - 3.6 V) | 6 | MOSI |
| 3 | GDO0 | 7 | MISO / GDO1 |
| 4 | CSN | 8 | GDO2 |

The ESP32 GPIO each of these lands on is in the
[pin map for firmware](../../../README.md#pin-map-for-firmware).

## The reproduction

3D model of the reproduction with the product's parts on it

Header pin 1, both mounting holes and the SMA ground legs are joined by GND
tracks on both copper layers; the original uses a ground pour instead. The
pin names are printed beside each header column on both sides.

Regenerate the project with `uv run scripts/generate_cc1101.py`, and its
images with `uv run scripts/render_boards.py cc1101-e07-m1101d` and
`uv run scripts/render_assemblies.py parts`.

## Sources

* [Ebyte E07 series user manual v1.00](https://ia802806.us.archive.org/26/items/ebytecdebytedl0719/557_E07_Usermanual_EN_v1.00.pdf),
  section 2.2 "E07 (M1101D-TH) / E07 (M1101D-SMA)": mechanical drawing
  (15.0&nbsp;x&nbsp;30.0, header 1.60 / 3.70 / 2.54, holes 2.70 / 10.0) and pin table.
* [Ebyte E07-M1101D-TH user manual v1.20](https://www.rcscomponents.kiev.ua/datasheets/e07-m1101d-th_usermanual_en_v1_20.pdf),
  section 3 "Size and pin definition": pad sizes (1.50 pad / 0.90 hole,
  4.20 ring / 3.00 hole).
* Seller listing (15&nbsp;x&nbsp;28 mm, pin table). The 28 mm figure is Ebyte's value
  for the spring-antenna variant; the SMA variant and the drawing say 30 mm.
* The SMA jack's leg spacing (5.5 mm) was measured from the user's photos;
  the pad lengths are approximate.

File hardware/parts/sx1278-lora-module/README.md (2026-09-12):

# SX1278 LoRa module (castellated)

The 16-pin castellated 433 MHz SX1278 module sold as "SX1278 LoRa 433MHz
Wireless Module (PXL1276-D01)" with a spring antenna. It is a derivative of
the NiceRF LoRa1276/LoRa1278 layout. A KiCad reproduction of it lives in this
directory; see [the parts index](../README.md) for what these reproductions
are for.

| 3D render, top | 3D render, bottom | Layout (copper, silk, fab, outline) |
| --- | --- | --- |
| 3D render of the top side | 3D render of the bottom side | 2D layout plot |

## Buying one

| | |
| --- | --- |
| Buy | [SX1278 long range RF wireless module](https://www.aliexpress.com/w/wholesale-sx1278-long-range-rf-wireless-module.html) -- the unshielded blue module with a spring antenna, not one of the shielded Ra-01 / E32 cans the broader searches return |
| How to recognise it | Roughly 17&nbsp;x&nbsp;16.5 mm, no carrier board: 12 castellated pads down one long edge, two notches at one corner and ANT / GND at the other. Sold as "SX1278 LoRa 433MHz Wireless Module (PXL1276-D01)". |
| Antenna | The spring antenna it is sold with solders to the ANT pad. |

Unlike the other three radios this one has no 2.54 mm header, so it does not
fit the socket on the main adapter. It solders flat onto SMD land pads on the
separate [SX1278 module adapter](../../esp32c3-sx1278-adapter), which is
described in [docs/sx1278-module-adapter.md](../../../docs/sx1278-module-adapter.md).

## Dimensions

All values in millimetres, viewed from the component side with the 12-pad
row on the left edge and pin 1 at the top.

| Feature | Value |
| --- | --- |
| Board outline | 17.0 (top/bottom edges) x 16.5 (left/right edges) |
| Left edge | 12 keyhole pads (pins 1-12) at 1.27 pitch, first hole 1.2 from the top corner |
| Bottom edge | 2 castellation-only notches: DIO4 (pin 13) 1.25 and DIO5 (pin 14) 2.7 from the left corner |
| Right edge | 2 keyhole pads: ANT (pin 16) 1.4 and GND (pin 15) 2.8 from the top corner |
| Keyhole pads, left row | 0.60 through-hole 1.2 in from the edge, 0.60 half-hole on the edge, 1.05 wide copper reaching 1.85 in |
| Keyhole pads, right edge | as above but hole 0.9 in from the edge, copper reaching 1.7 in |
| Notches | 0.60 half-hole on the edge, 0.8 wide copper reaching 0.55 in, no inboard hole |
| Board thickness | 1.0 (assumed) |

## Pinout

Pin names (J1), numbered counter-clockwise from the top-left:

| Pin | Name | Pin | Name |
| --- | --- | --- | --- |
| 1 | GND | 9 | NSS |
| 2 | DIO1 | 10 | DIO0 |
| 3 | DIO2 | 11 | REST (reset) |
| 4 | DIO3 | 12 | GND |
| 5 | VCC (3.3 V) | 13 | DIO4 |
| 6 | MISO | 14 | DIO5 |
| 7 | MOSI | 15 | GND |
| 8 | SCK | 16 | ANT |

## The reproduction

3D model of the reproduction with the product's parts on it

The three GND pins are joined by tracks (the original uses a ground plane).
Approximate positions of the SX1278 and its crystal are drawn on `F.Fab`.

Regenerate the project with `uv run scripts/generate_sx1278.py`, and its
images with `uv run scripts/render_boards.py sx1278-lora-module` and
`uv run scripts/render_assemblies.py parts`.

## Sources and accuracy

* Seller PDF for the "SX1278 LoRa 433MHz Wireless Module (PXL1276-D01)":
  module size 17&nbsp;mm&nbsp;x&nbsp;16.5&nbsp;mm.
* Seller pinout photo (top-down with dimension lines) for the pin names in
  physical order: GND DIO1 DIO2 DIO3 VCC MISO MOSI SCK NSS DIO0 REST GND
  along the row, DIO4 and DIO5 at the adjacent corner, ANT and GND at the
  opposite corner. The seller's pin table lists REST twice, which shifts its
  last four entries by one; the photo was followed.
* No manufacturer drawing was found for this variant. Pad positions were
  measured in pixels from the top-down pinout photo and a perspective-
  rectified product photo; both give the 12-pad row a 1.27 mm pitch on the
  16.5 mm edge (the pinout photo's dimension labels appear to have the two
  sides swapped). Positions are accurate to roughly +/-0.15 mm; the pitch,
  pin count and outline are solid.
* Close-up photos show the 12 row pads and the two ANT/GND pads are keyholes
  like the SuperMini's (a plated through-hole plus a half-hole castellation on
  the edge, joined by an oval), while DIO4 and DIO5 are plain castellations
  without an inboard hole. The
  [NiceRF LoRa127X datasheet](https://makerhero.com/img/files/download/LoRa127X-Module-Datasheet.pdf)
  mechanical drawing shows the same construction for this family and
  supplied the 0.6 mm hole size.

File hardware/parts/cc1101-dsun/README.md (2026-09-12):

# CC1101 D-Sun (green board)

The green CC1101 board marked "433MHz D-Sun CC1101" (EasyEDA lists the same
board as "RF1101SE V3.1"): a 2x4 header at one end, an edge-mount SMA jack at
the other and two small holes beside the jack. A KiCad reproduction of it
lives in this directory; see [the parts index](../README.md) for what these
reproductions are for.

| 3D render, top | 3D render, bottom | Layout (copper, silk, fab, outline) |
| --- | --- | --- |
| 3D render of the top side | 3D render of the bottom side | 2D layout plot |

## Buying one

| | |
| --- | --- |
| Buy | [CC1101 433MHz module](https://www.aliexpress.com/w/wholesale-cc1101-433mhz-module.html), pick the green one |
| How to recognise it | Green, 14.4&nbsp;x&nbsp;30 mm, silk "433MHz D-Sun CC1101", 2x4 header, SMA jack |
| Also needs | A [433 MHz SMA antenna](https://www.aliexpress.com/w/wholesale-433mhz-sma-antenna.html). Not the 868/915 MHz one many listings bundle with the same radio. |

It plugs into the [radio socket](../../esp32c3-radio-adapter) on the adapter
board, sharing it with the [E07-M1101D](../cc1101-e07-m1101d) and the
[SX1278 Ra-02 breakout](../sx1278-ra02-breakout). Its header order differs
from the E07's, so it takes its own firmware pin map.

Its back-side silk is a 4&nbsp;x&nbsp;2 legend of the pin names next to the header,
which is what you wire from.

## Dimensions

All values in millimetres, viewed from the component side with the header at
the top and the SMA jack at the bottom. They were measured from photos of
the board beside the E07-M1101D (whose 15&nbsp;x&nbsp;30 gives the scale), so allow
about +/- 0.3 mm; the thickness is assumed.

| Feature | Value |
| --- | --- |
| Board outline | 14.4&nbsp;x&nbsp;30.0 |
| Header | 2&nbsp;x&nbsp;4, 2.54 pitch, 1.50 pads (pin 1 square), 0.90 holes |
| Header position | outer row 2.1 from the header edge; columns 2.9 to 10.5 from the left long edge (0.5 left of centre) |
| Header numbering | as the E07: outer row 7 5 3 1 left to right, inner row 8 6 4 2 |
| Mounting holes | 1.8, not plated, 1.7 from each long edge, 2.5 from the SMA edge |
| SMA jack | edge mount, centred on the bottom edge; ground legs 2.75 either side |
| Board thickness | 1.6 (assumed) |

## Pinout

Pin names (J1, numbered like the E07's header so the GND/VCC column matches):

| Pin | Name | Pin | Name |
| --- | --- | --- | --- |
| 1 | GND | 5 | MISO |
| 2 | VCC | 6 | GDO2 |
| 3 | MOSI | 7 | GDO0 |
| 4 | SCK | 8 | CSN |

The ESP32 GPIO each of these lands on is in the
[pin map for firmware](../../../README.md#pin-map-for-firmware); why the
socket suits both header orders is in the
[design notes](../../../docs/design-notes.md).

## The reproduction

3D model of the reproduction with the product's parts on it

The pin names are printed beside each header column on both sides, and the
back carries the original's legend grid.

Regenerate the project with `uv run scripts/generate_dsun.py`, and its images
with `uv run scripts/render_boards.py cc1101-dsun` and
`uv run scripts/render_assemblies.py parts`.

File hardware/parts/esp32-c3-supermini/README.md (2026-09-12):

# ESP32-C3 SuperMini

The ESP32-C3 SuperMini: a 18&nbsp;x&nbsp;22.5 mm ESP32-C3 board with USB-C, eight
castellated pins per side and a ceramic antenna. It is the brain of every
board in this repository. A KiCad reproduction of it lives in this directory;
see [the parts index](../README.md) for what these reproductions are for.

| 3D render, top | 3D render, bottom | Layout (copper, silk, fab, outline) |
| --- | --- | --- |
| 3D render of the top side | 3D render of the bottom side | 2D layout plot |

The grey half-circles outside the outline in the 3D renders are the outer
halves of the castellation pads; the PCB fab routes them away, leaving plated
half-holes on the edge.

## Buying one

| | |
| --- | --- |
| Buy | [ESP32-C3 SuperMini](https://www.aliexpress.com/w/wholesale-esp32-c3-supermini.html) |
| How to recognise it | 18&nbsp;x&nbsp;22.5 mm, USB-C, 8 castellated pins per side, ceramic antenna at the far end from the USB-C |
| Also comes with | Usually two 1x8 pin headers in the bag. Solder those, or solder the SuperMini flat by its castellations. |

## Dimensions

All values in millimetres, viewed from the component side with the USB-C end
at the top.

| Feature | Value |
| --- | --- |
| Board outline | 18.00&nbsp;x&nbsp;22.52, square corners |
| Pin pitch | 2.54 |
| Pins per side | 8 (16 total) |
| Distance between the two pin rows | 15.24 |
| Pin centre to long board edge | 1.38 |
| First pin centre to USB-C edge | 1.74 |
| Last pin centre to antenna edge | 3.00 |
| Through-hole drill | 1.00 |
| Castellation half-hole on the edge | 1.00 diameter, centred on the edge |
| Pad copper | 1.60 wide oval from the pin to the board edge |
| Board thickness | 1.0 (from the STEP model, not a datasheet) |

## Pinout

Pin names, top to bottom:

| Left (J1) | Right (J2) |
| --- | --- |
| GPIO5 | 5V |
| GPIO6 | GND |
| GPIO7 | 3V3 |
| GPIO8 | GPIO4 |
| GPIO9 | GPIO3 |
| GPIO10 | GPIO2 |
| GPIO20 | GPIO1 |
| GPIO21 | GPIO0 |

Which of these the adapter uses for the radio is in the
[pin map for firmware](../../../README.md#pin-map-for-firmware); the boot
straps and why they constrain the choice are in the
[design notes](../../../docs/design-notes.md).

## The reproduction

3D model of the reproduction with the product's parts on it

The USB-C connector, BOOT and RST buttons and the ceramic antenna of the
original board are drawn on the `F.Fab` layer as placement references only.

Regenerate the project with `uv run scripts/generate_supermini.py`, and its
images with `uv run scripts/render_boards.py esp32-c3-supermini` and
`uv run scripts/render_assemblies.py parts`.

## Sources

* [GrabCAD "ESP32C3 SuperMini" STEP model by Ulf Hille](https://grabcad.com/library/esp32c3-supermini-1),
  redistributed in [mrtnvgr/KiCad_ESP32-C3-SuperMini](https://github.com/mrtnvgr/KiCad_ESP32-C3-SuperMini):
  board body 18.00&nbsp;x&nbsp;22.52, pin rows at +/-7.62, first pin 1.74 from the USB-C edge, 1.6 mm pad copper.
* [mischianti.org ESP32-C3 Super Mini dimension drawing](https://mischianti.org/esp32-c3-super-mini-high-resolution-pinout-datasheet-and-specs/):
  18.00 mm width, 15.24 mm row spacing, 22.50 mm length, pin order.
* [components101 ESP32-C3 Super Mini](https://components101.com/development-boards/esp32c3-mini-development-board-datasheet-pinout): 22.52&nbsp;x&nbsp;18.0 mm.
* Photographs of production boards for the keyhole castellated pad shape.

The hole diameter (1.0 mm) is the standard drill for 2.54 mm headers and
matches the hole size measured from the dimension drawing; it was not taken
from a manufacturer datasheet. Note that the community KiCad footprint linked
above has its GPIO column reversed (GPIO21 opposite 5V instead of GPIO5); the
footprints here were generated from scratch and follow the physical board.

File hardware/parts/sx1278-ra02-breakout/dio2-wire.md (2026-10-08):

# SX1278 Ra-02 breakout — adding the DIO2 wire

The blue **"SX1278 LoRa 433MHz v4.0"** breakout (an Ai-Thinker Ra-02 on a small
carrier with a 2×4 header) brings out **DIO0 and nothing else** of the SX1278's
six DIO lines. Full FSK *and* OOK needs **DIO2**, so DIO2 has to be soldered
straight to the module. This page says which pad that is, and how to prove by
hand that the wire landed on it.

where the DIO2 wire attaches

Only the radio end is covered here. The far end is the adapter's
[J5 fly-wire header](../../../docs/design-notes.md#the-dio2-fly-wire-header) —
pin 2, GPIO20 — which the [board README](../../../README.md#pin-map-for-firmware)
documents.

## Why DIO2 specifically

The SX1278 has exactly two data paths, and the datasheet
([SX1276/77/78/79 rev 7](https://cdn.sparkfun.com/assets/7/7/3/2/2/SX1276_Datasheet.pdf))
allows no third:

> **Continuous mode**: each bit transmitted or received is accessed in real time
> at the DIO2/DATA pin. […] **Packet mode (recommended)**: user only
> provides/retrieves payload bytes to/from the FIFO. *(§2.1.9.2, p.69)*

> As illustrated in Figure 29, in Continuous mode the NRZ data to (from) the
> (de)modulator is directly accessed by the uC on the bidirectional DIO2/DATA
> pin. The FIFO and packet handler are thus inactive. *(§2.1.12.1, p.70)*

Table 29 (*DIO Mapping, Continuous Mode*, p.68) closes the door on any
alternative routing: **all four `Dio2Mapping` values give `Data`**, in both Rx
and Tx, and no other DIO can be mapped to it in Rx.

The consequence for this node:

| Job | Needs DIO2? | Why |
|---|---|---|
| Fine Offset weather RX (FSK) | no | fixed-length packets with a sync word — the packet handler frames them, the FIFO carries them, DIO0 signals `PayloadReady` |
| FSK packet TX | no | FIFO in, DIO0 says `PacketSent` |
| **OOK remotes RX** | **yes** | arbitrary PWM/Manchester bursts, no sync word: the firmware has to see the demodulator's raw edges and time them itself |
| **OOK / Security+ TX** | **yes** | continuous-mode transmit clocks data *into* the same bidirectional pin |
| LoRa | no | its own modem and register bank |

DIO2 is the SX1278's equivalent of the CC1101's GDO2, which this project's
firmware already feeds into ISR edge capture and the OOK-PWM decoders. Without
the wire an SX1278 node is a weather-only receiver.

## Which pad

**Module pin 7 — the 7th castellation counting from the antenna-connector
corner, i.e. the second-to-last on that edge.**

Numbering is from the Ai-Thinker *Ra-01/Ra-02 LoRa Module User Manual* §2.2:
pins 1–8 run down one 17 mm edge and 9–16 back up the other, counter-clockwise
seen from the component side, with the IPEX connector at the pin-1 corner.

| Pin | | Pin | | Pin | | Pin | |
|--:|---|--:|---|--:|---|--:|---|
| 1 | GND | 5 | DIO0 | 9 | GND | 13 | MISO |
| 2 | GND | 6 | DIO1 | 10 | DIO4 | 14 | MOSI |
| 3 | 3.3V | **7** | **DIO2** | 11 | DIO5 | 15 | NSS |
| 4 | RESET | 8 | DIO3 | 12 | SCK | 16 | GND |

The carrier routes pins 3, 4, 5, 12, 13, 14, 15 and a GND to its 2×4 header —
that is the whole of `MISO / DIO0 / SCK / MOSI / RST / NSS / GND / 3V3` you can
read on its back silkscreen. **DIO1, DIO2, DIO3, DIO4 and DIO5 go nowhere.**

Two places take solder, and they are the same net:

- the module's **castellated half-hole** for pin 7, and
- the **carrier land pad** immediately outside it, which protrudes past the
  module edge and is easier to hit with an iron.

Since the carrier routes that pad to nothing, either is DIO2 and only DIO2 — but
prove it rather than assume it, because a land pad that *looks* isolated is
exactly what a solder bridge hides.

> **Orientation.** The diagram is the **component side** — module face up, IPEX
> at the pin-1 corner. The 2×4 header is on the *other* face, so when you flip
> the board to reach the header pins the pad order mirrors.

## Verifying it with the node plugged in

The node is on USB. That one cable carries two independent channels — Espressif's
guide puts it plainly: the chip provides *"two USB channels, one for JTAG and the
other for the USB terminal connection"*. So you can **command the SX1278 down the
console channel** and **watch the ESP32-C3's pins down the JTAG channel**, at the
same time, with no firmware change: the [`SxReg`](../../../firmware/README.md)
command already ships.

The method:

1. force DIO2 to a known level over SPI,
2. read the ESP32-C3's *whole* GPIO input register in one word,
3. force the other level and read it again,
4. **the bit that flips names the GPIO the wire landed on.**

That is better than probing the one pin you expect: `GPIO_IN_REG` shows all 22
GPIOs at once, so a wire that landed on the wrong pad announces itself instead of
reading as a dead wire. The expected answer here is **bit 20** — J5 pin 2.

> ### Use Espressif's OpenOCD, not the distro's
>
> `openocd-esp32` (the build ESP-IDF ships) has a real `esp32c3` target and
> `board/esp32c3-builtin.cfg`. **Do not use mainline OpenOCD on this chip.**
> Debian's 0.12.0+dev has the `esp_usb_jtag` adapter and will happily attach
> with a hand-written RISC-V config — it connects, finds the TAP
> (`0x00005c25`), examines the core, and reads memory correctly. Then it
> destroys the node. Measured on the bench, 2026-09-09: it drives the core
> through the program buffer incorrectly (`Unexpected read of fp via program
> buffer`, `Failed to read s0`, `Examination failed`, `Hart unexpectedly
> reset!`) and its `resume` leaves `dcsr = 0x400090c3` — **`ebreakm` set** — so
> the application takes a Breakpoint exception on every boot:
>
> ```
> Guru Meditation Error: Core 0 panic'ed (Breakpoint). Exception was unhandled.
> Setting breakpoint at 0x42160ffa and returning...
> Panic handler entered multiple times. Abort panic handling. Rebooting ...
> ```
>
> Clearing `dcsr` and disarming all eight triggers did not recover it; each
> `reset run` re-examined into failure, and it ended with the hart halted and
> the chip no longer enumerating on USB at all — a hub power cycle did not
> bring it back. Assume mainline OpenOCD on an ESP32-C3 costs you a trip to the
> bench.

### 0. Park the radio

```
CcMode remotes
```

On an SX1278 node this drops `weather_rx`, puts the chip in standby and stops
the 50 ms weather poll, so your register writes stay put instead of being
overwritten by the receive loop. It is persisted to `/cc1101.cfg` — **set
`CcMode weather` back when you are done.** Both commands are in the
[firmware command reference](../../../firmware/README.md).

Talk to the node over the USB console with any serial terminal that opens the
port **with DTR/RTS deasserted**, so the ESP32-C3 is not reset as you attach, or
over HTTP if the node is on WiFi:

```
curl -sG http://<node-ip>/cm --data-urlencode 'cmnd=CcMode remotes'
```

### 1. Force DIO2 to a level you choose

In **continuous** mode DIO2 *is* the demodulator's data line whatever the DIO
mapping says (Table 29), and in OOK with a **fixed** threshold the demodulator
output is whatever you set the threshold to make it: floor it and the noise is
always "on", ceiling it and nothing ever is.

| Step | Command | Effect |
|---|---|---|
| continuous mode | `SxReg 0x31 0x00` | `RegPacketConfig2` `DataMode` = 0 — FIFO and packet handler out of the way |
| no receive trigger | `SxReg 0x0D 0x08` | `RegRxConfig` `RxTrigger` = 000, AGC auto kept — the weather preset's `0x0E` parks the receiver until a preamble is seen (see the RxReady note below) |
| OOK, receiving | `SxReg 0x01 0x2D` | `RegOpMode`: FSK/OOK bank, `ModulationType` = OOK, low-frequency band, Rx |
| raw demod, fixed threshold | `SxReg 0x14 0x00` | `RegOokPeak`: `BitSyncOn` = 0 (raw output straight to DATA), `OokThreshType` = fixed |
| **DIO2 → low** | `SxReg 0x15 0xFF` | `RegOokFix` = 255 dB: nothing ever crosses it |
| **DIO2 → high** | `SxReg 0x15 0x00` | `RegOokFix` = 0 dB: the noise floor is always above it |

Add a **positive control** on the same pass, so a null result cannot be blamed
on the method. DIO0 *is* wired — GPIO6 on this adapter — so give it a level you
also control:

| Step | Command | Effect |
|---|---|---|
| DIO0 = Rssi | `SxReg 0x40 0x40` | `RegDioMapping1` `Dio0Mapping` = 01 → Rssi in continuous Rx (Table 29) |
| **DIO0 → high** | `SxReg 0x10 0xFF` | `RegRssiThresh` = −127.5 dBm: always exceeded |
| **DIO0 → low** | `SxReg 0x10 0x00` | `RegRssiThresh` = 0 dBm: never exceeded |

`SxReg 0x3E` reads `RegIrqFlags1`, whose bit 3 is that same Rssi flag — the
chip's own view, to check against the pin.

> **Do not use RxReady for this.** It looks perfect on paper (`Dio2Mapping` = 01
> → RxReady in packet-mode Rx, mirrored in `RegIrqFlags1` bit 6) and it does not
> work under the firmware's preset: measured on the bench 2026-09-09, driving
> `RegOpMode` standby → Rx moved `RegIrqFlags1` from `0x80` (ModeReady) to `0x18`
> (PllLock + Rssi), **RxReady never asserted**, and `RegOpMode` itself read back
> `0x0C` (FSRx) instead of the `0x0D` written — the chip parks the receiver in
> frequency-synthesis until the trigger fires. Cause confirmed the same day by
> changing only `RegRxConfig`: `0x0E` (`RxTrigger` = PreambleDetect) → `0x0C` /
> `0x18`; `0x09` (`RxTrigger` = Rssi) → `0x0D` / `0xD8` (ModeReady, RxReady,
> PllLock, Rssi) within 0.5 s; back to `0x0E` → parked again. Auto-restart
> (`RegSyncConfig`) made no difference. That is why step 1 clears the trigger
> first: with it cleared the receiver runs unconditionally, so the OOK threshold
> decides DATA and nothing waits on a packet.

### 2. Read every GPIO in one word

`GPIO_IN_REG` is at **`0x6000403C`** — `DR_REG_GPIO_BASE` `0x60004000`
(`soc/reg_base.h`) plus offset `0x3C` (`soc/gpio_reg.h`) — and bits 0–21 are
GPIO0–GPIO21.

```
openocd -f board/esp32c3-builtin.cfg \
        -c 'adapter serial <the node's MAC>' \
        -c init -c halt -c 'mdw 0x6000403C' -c resume -c 'sleep 300' \
        -c targets -c shutdown
```

`adapter serial` picks the right node when several ESP32-C3s share the VID:PID
`303a:1001` on one host — their USB serial string is their MAC. Attaching
**halts the CPU**, so the node stops decoding for the few seconds you hold it;
always `resume`, and confirm with `targets` that it says `running` *before*
shutting OpenOCD down.

A healthy read looks like this one, taken from the real node on 2026-09-09:

```
0x6000403c: 00337706
```

which decodes as a sanity check on the wiring you already believe in: GPIO5 = 0
(the radio-type strap, tied low on the Ra-02 adapter), GPIO1 (NSS) and GPIO10
(RST) high and idle, GPIO3/4/7 (SCK/MOSI/MISO) low between transactions.

### 3. Diff the two reads

Take a read in the DIO2-low state and another in the DIO2-high state and XOR
them.

| Bits that flip | Verdict |
|---|---|
| bit 6 **and** bit 20 | the wire is good, and it is on the pin the adapter expects |
| bit 6 **and** exactly one other bit | the wire works but landed on the wrong GPIO; that bit names where it actually went |
| bit 6 only | the method works — and there is **no working DIO2 wire** |
| nothing at all | the test itself did not run: the radio is not in the state you think, or you are talking to the wrong node — fix that before believing any verdict |
| bit 6 and several others | you are watching SPI traffic; make sure nothing is driving the bus during the read |

### 4. Put it back

```
SxReg 0x40 0x00
SxReg 0x31 0x40
SxReg 0x0D 0x0E
CcMode weather
SxStatus
```

`CcMode weather` rewrites the whole preset anyway; the three `SxReg` lines
just leave nothing surprising behind if it is skipped. `SxStatus` should show
`"Mode":"weather","WeatherRx":1` again, and the `Rx` counter should start
climbing within a minute or two. A healthy node in weather mode reads
`RegOpMode` `0x0C` and `RegIrqFlags1` `0x18` between packets — that is the
parked-until-preamble state described above, not a fault.

### Status of this procedure

Bench-checked on 2026-09-09, on the real node: `CcMode remotes` parks the radio,
`SxReg` reads and writes registers as documented, the standby → Rx transition is
visible in `RegIrqFlags1`, and `GPIO_IN_REG` reads correctly over the built-in
USB-JTAG. **Steps 1–3 have not been run end-to-end**, because no DIO2 wire
exists yet and the session that would have run them destroyed the node with the
wrong OpenOCD (see the warning above). Treat the OOK-threshold levels as
designed-and-reasoned rather than measured until someone runs them.

## Sources

- Semtech **SX1276/77/78/79** datasheet rev 7, May 2020 — §2.1.9.2 data
  operation modes (p.69), §2.1.12 continuous mode (p.70), Table 29/30 DIO
  mapping (p.68), Table 41 register reset values, RegPacketConfig2 `DataMode`.
- Ai-Thinker **Ra-01/Ra-02 LoRa Module User Manual** §2.2 — the 16-pin table
  and the counter-clockwise numbering from the IPEX corner.
- ESP-IDF **JTAG debugging** guide (v5.4, ESP32-C3) — `board/esp32c3-builtin.cfg`,
  `openocd -f board/esp32c3-builtin.cfg`, and the chip's "two USB channels, one
  for JTAG and the other for the USB terminal connection".
- ESP32-C3 register addresses from ESP-IDF v5.4 `components/soc/esp32c3/register/soc/`:
  `reg_base.h` (`DR_REG_GPIO_BASE` `0x60004000`) and `gpio_reg.h`
  (`GPIO_IN_REG` = base + `0x3C`).
- The header's eight nets: read directly off the breakout's own back silkscreen
  in [`photos/ra02-header.jpg`](photos/ra02-header.jpg), and matching the KiCad
  reproduction of this breakout in
  [`scripts/generate_ra02_breakout.py`](../../../scripts/generate_ra02_breakout.py)
  (`HDR_NETS`).

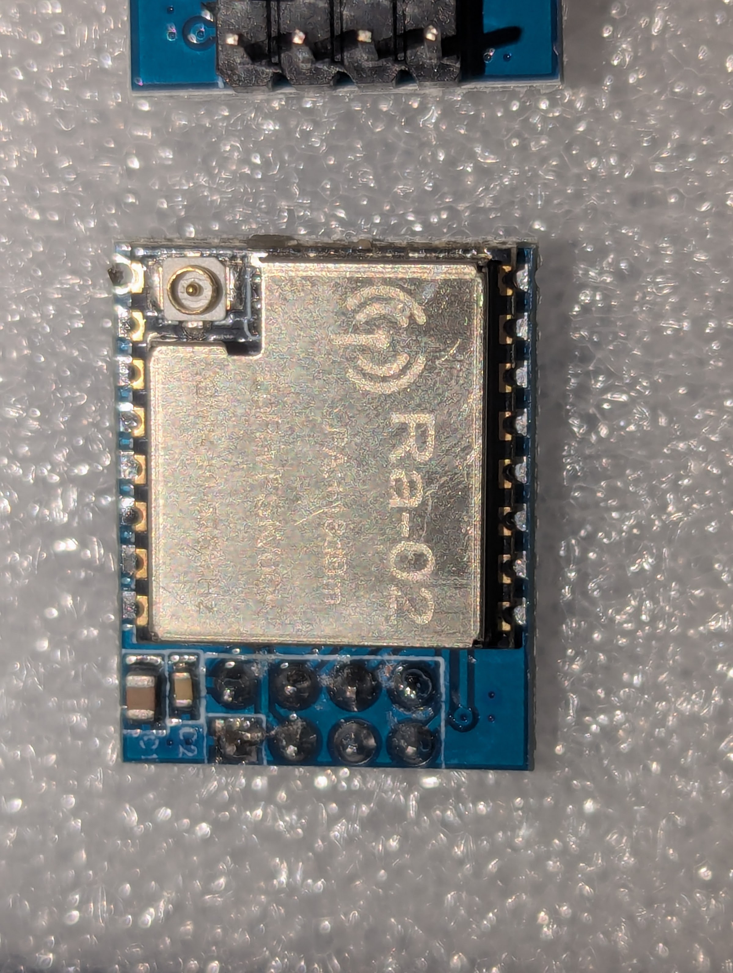
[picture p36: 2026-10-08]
hardware/parts/sx1278-ra02-breakout/photos/ra02-front.jpg

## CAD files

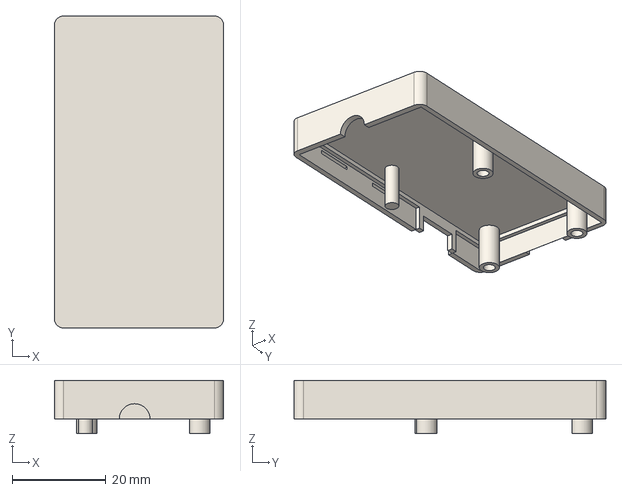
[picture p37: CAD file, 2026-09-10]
hardware/3d/esp32c3-radio-adapter-case-top.step
36.2 x 66.7 x 11.4 mm

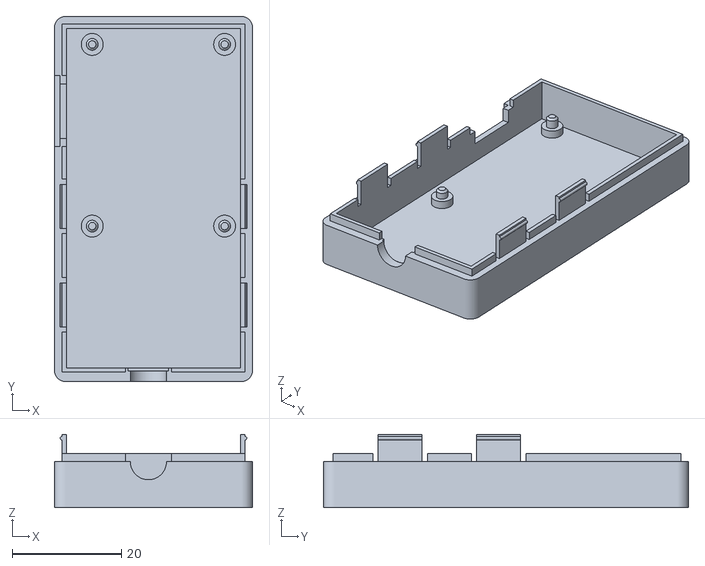
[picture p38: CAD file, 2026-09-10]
hardware/case/esp32c3-radio-adapter-case-bottom.stl
36.2 x 66.7 x 13.4

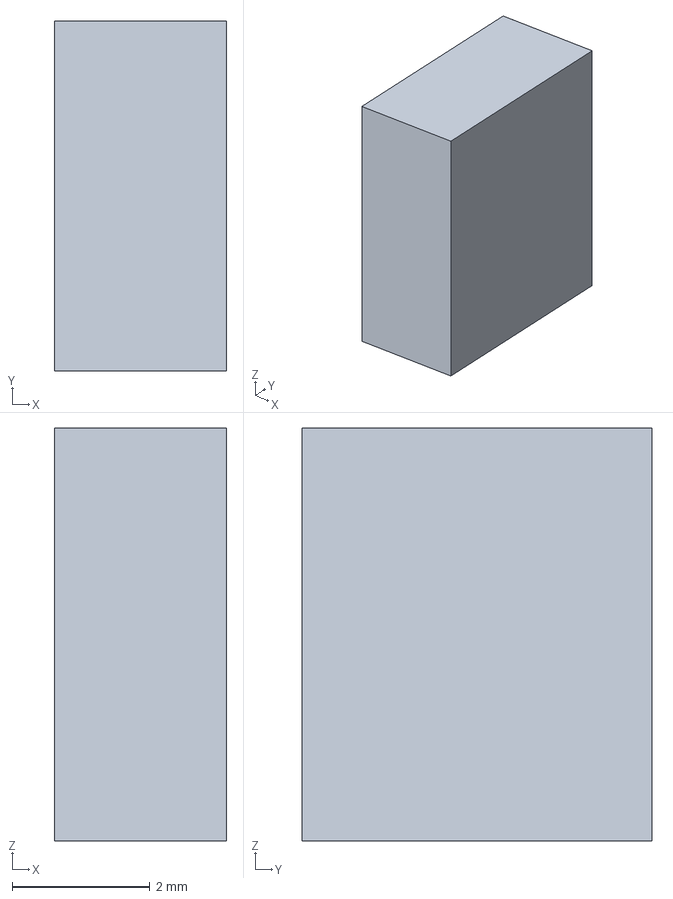
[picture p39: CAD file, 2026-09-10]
hardware/3d/jumper-cap.step
2.50 x 5.08 x 6.00 mm

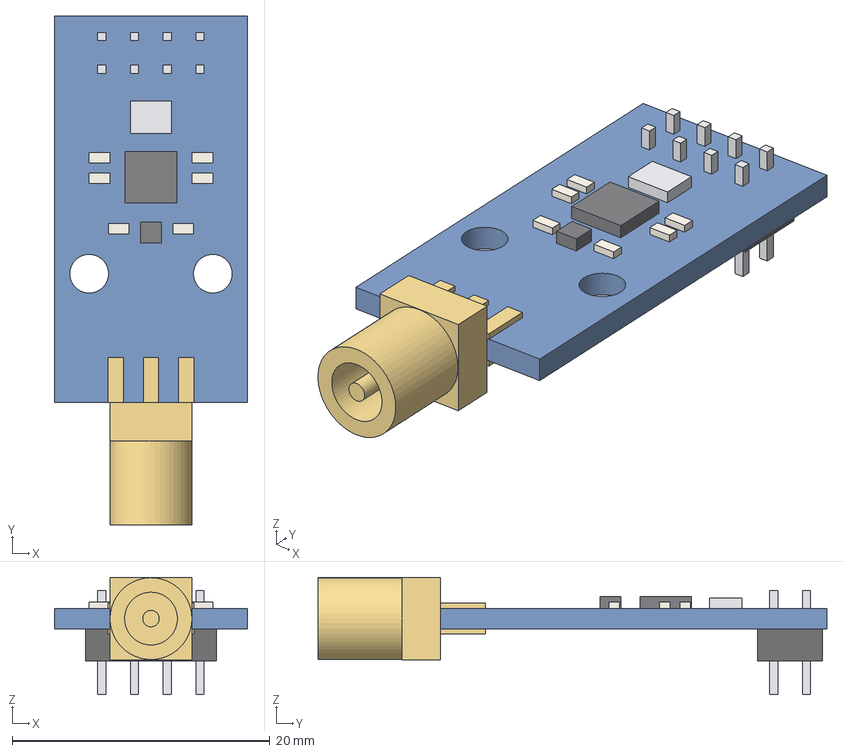
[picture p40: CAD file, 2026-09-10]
hardware/3d/cc1101-e07-m1101d.step
15.0 x 39.5 x 9.10 mm
pcb_0
cc1101_1
crystal_2
balun_3
passive_4
passive_5
passive_6
passive_7
passive_8
passive_9
sma_body_10
sma_pin_11
sma_leg_12
sma_leg_13
sma_leg_14
sma_leg_15
sma_leg_16
pins_18

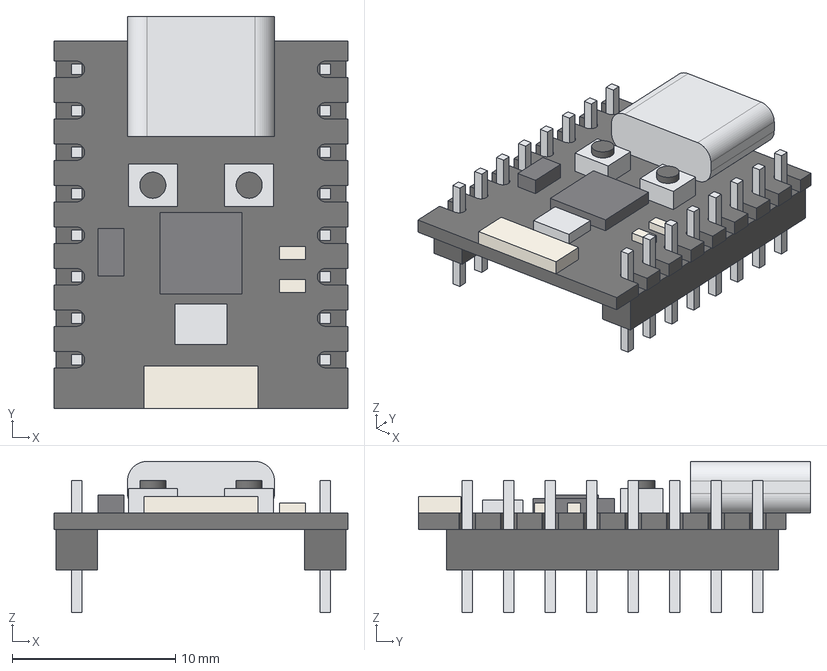
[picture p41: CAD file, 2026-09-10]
hardware/3d/esp32-c3-supermini.step
18.0 x 24.0 x 9.26 mm
pcb_0
usb_c_1
button_2
button_cap_3
button_4
button_cap_5
esp32c3_6
crystal_7
ldo_8
led_9
led_10
antenna_11
pins_13

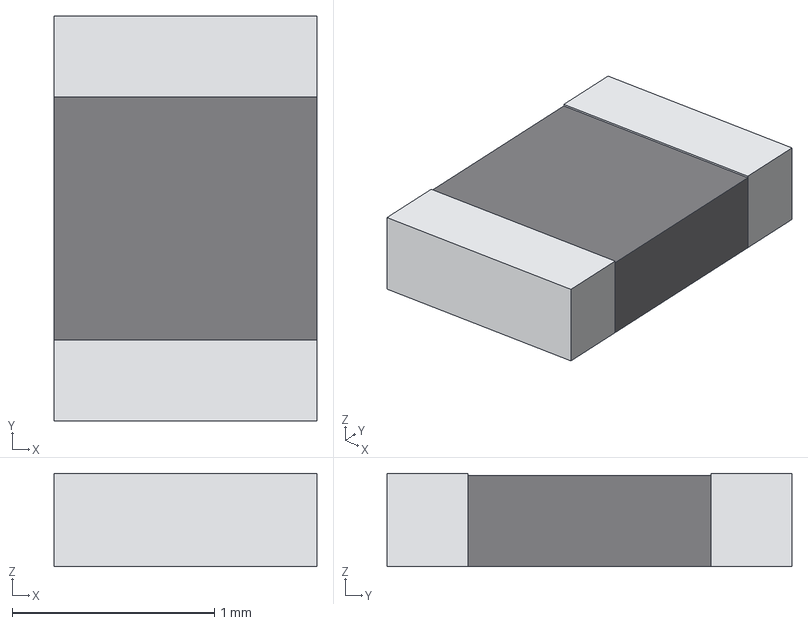
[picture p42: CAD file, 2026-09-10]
hardware/3d/r0805.step
1.30 x 2.00 x 0.46 mm
r_body_0
r_end_1
r_end_2

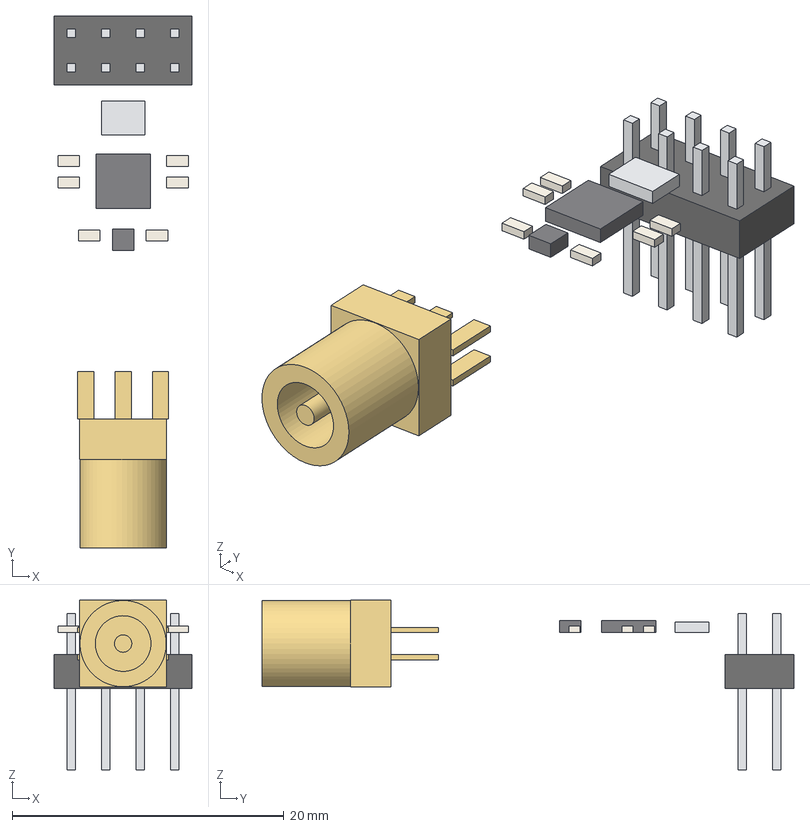
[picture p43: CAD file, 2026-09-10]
hardware/3d/cc1101-e07-m1101d-components.step
10.2 x 39.2 x 12.5 mm
cc1101_0
crystal_1
balun_2
passive_3
passive_4
passive_5
passive_6
passive_7
passive_8
sma_body_9
sma_pin_10
sma_leg_11
sma_leg_12
sma_leg_13
sma_leg_14
sma_leg_15
pins_17

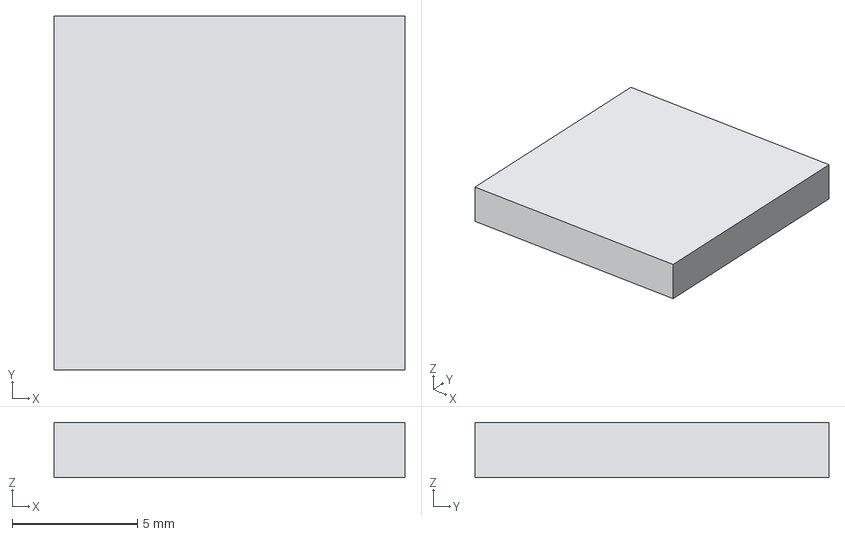
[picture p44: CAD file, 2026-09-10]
hardware/3d/sx1278-lora-module-components.step
14.0 x 14.1 x 2.20 mm

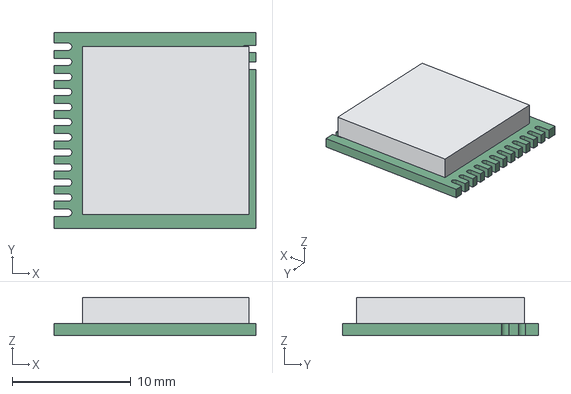
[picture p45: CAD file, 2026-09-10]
hardware/3d/sx1278-lora-module.step
17.0 x 16.5 x 3.20 mm
pcb_0
can_1

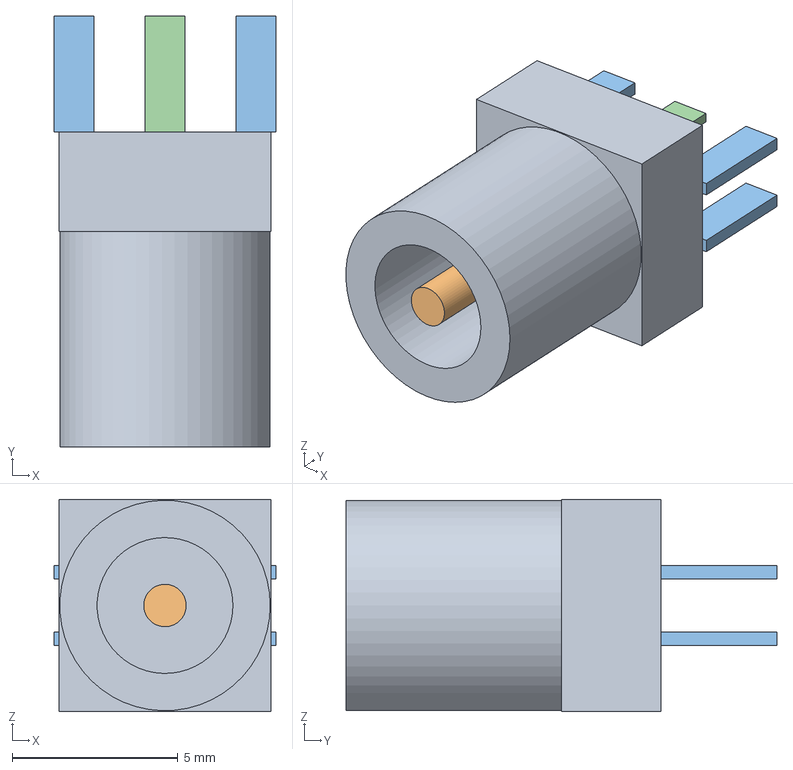
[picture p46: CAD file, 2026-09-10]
hardware/3d/sma-edge-jack.step
6.70 x 13.0 x 6.40 mm
sma_body_0
sma_pin_1
sma_leg_2
sma_leg_3
sma_leg_4
sma_leg_5
sma_leg_6

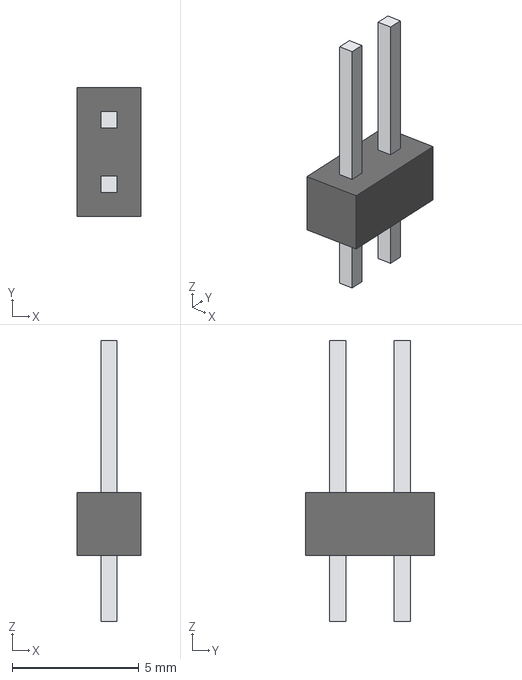
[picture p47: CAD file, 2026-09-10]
hardware/3d/pin-header-1x02.step
2.54 x 5.08 x 11.1 mm
pins_1

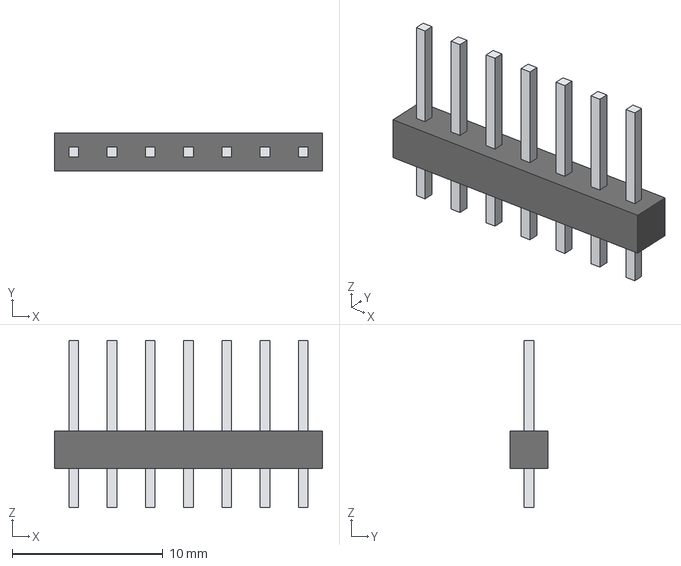
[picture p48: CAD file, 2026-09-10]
hardware/3d/pin-header-1x07.step
17.8 x 2.54 x 11.1 mm
pins_1

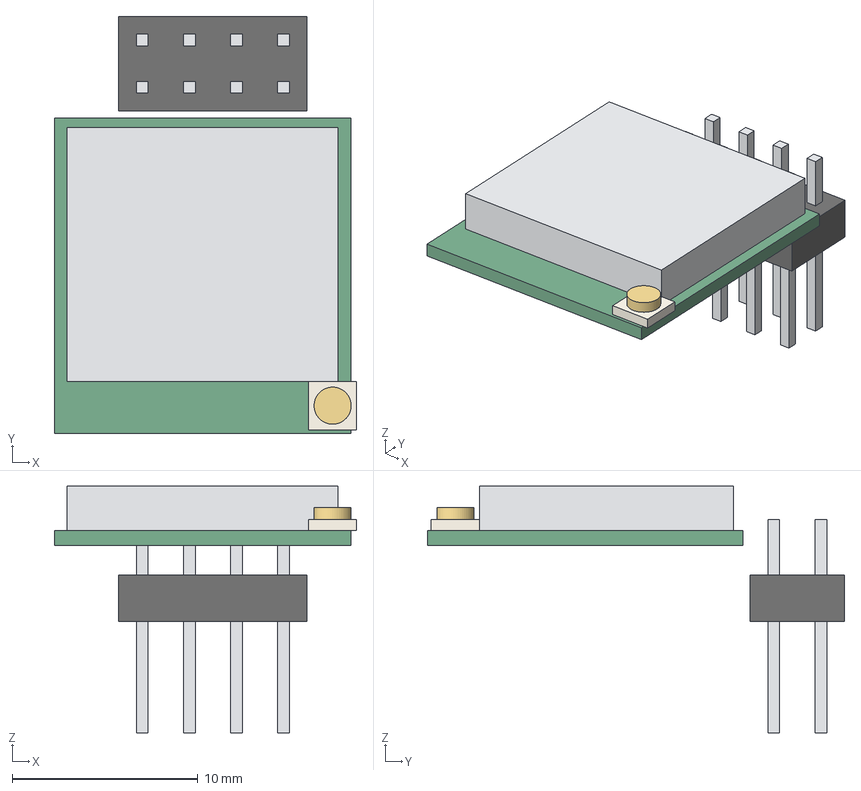
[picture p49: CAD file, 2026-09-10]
hardware/3d/sx1278-ra02-breakout-components.step
16.3 x 22.5 x 13.3 mm
ra02_pcb_0
ra02_can_1
ipex_2
ipex_3
pins_5

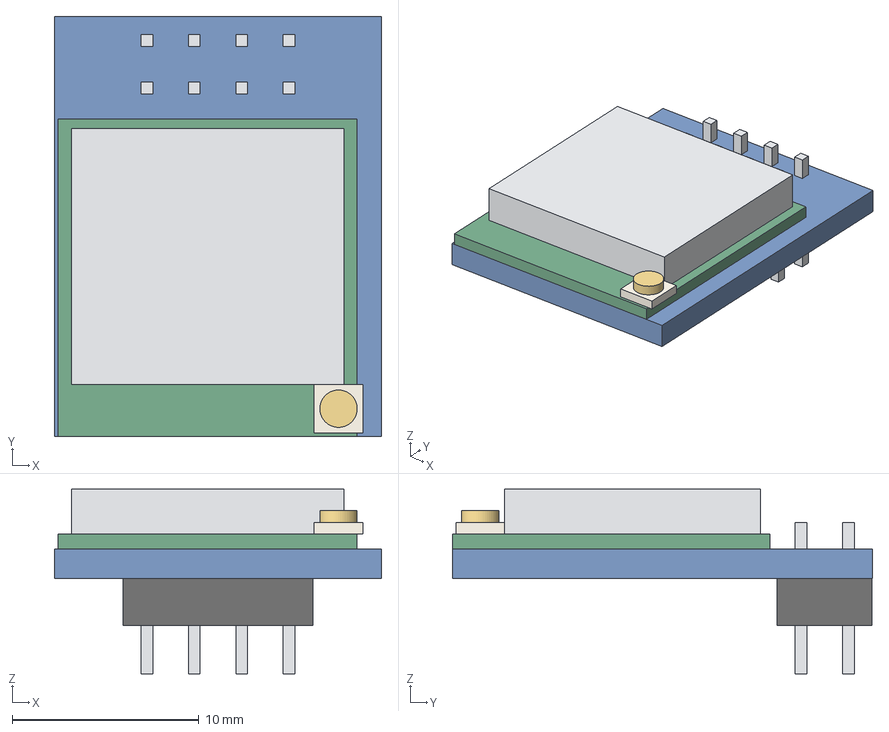
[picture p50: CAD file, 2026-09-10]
hardware/3d/sx1278-ra02-breakout.step
17.5 x 22.5 x 9.90 mm
pcb_0
ra02_pcb_1
ra02_can_2
ipex_3
ipex_4
pins_6

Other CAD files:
hardware/3d/esp32c3-radio-adapter-case-top-slot.step
hardware/case/esp32c3-radio-adapter-case-top-slot.stl
hardware/3d/esp32c3-radio-adapter-case-bottom.step
hardware/case/esp32c3-radio-adapter-case-top.stl
hardware/3d/cc1101-dsun-components.step
hardware/3d/cc1101-dsun.step
hardware/3d/esp32-c3-supermini-components.step
hardware/3d/sx1278-ra02-pigtail.step

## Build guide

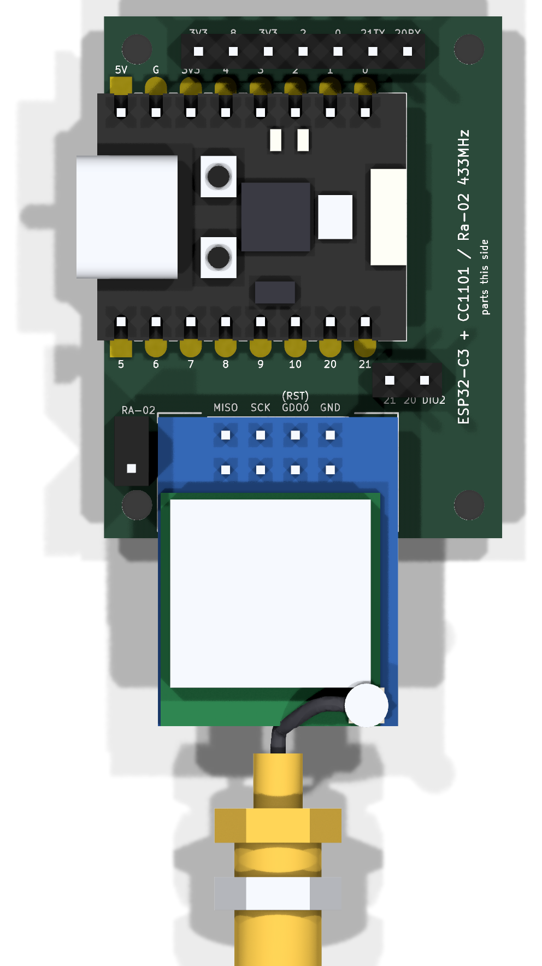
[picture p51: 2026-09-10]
docs/images/esp32c3-radio-adapter-assembly-ra02-top.png

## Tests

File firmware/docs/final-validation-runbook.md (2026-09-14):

# Final on-hardware validation runbook (closes criteria b & e)

Everything code-side is done, hardened, and CI-green. **Status update (2026-09-09):** the core
on-hardware validation is DONE - blue (CC1101) and the RA-02 (SX1278) both decode WS69 + WH51 live
and were cross-checked (see [`HWTEST-RESULTS-cc1101.md`](HWTEST-RESULTS-cc1101.md)); **criterion (e)
is closed on the real `ha.welland.mithis.com` broker** — blue + sx are commissioned onto it, and the
node's **native HA MQTT Discovery** made Home Assistant auto-create 14 weather/moisture entities
(verified via the HA states API); and SX1278 FSK TX is confirmed on-air. The genuinely-open items
are all **hardware/external**, not firmware: **green's cold-boot** (JTAG-proven GPIO9 reset-edge
strap in mask ROM, upstream of the app — needs the adapter GPIO9 pull-up), the **SX1278 OOK** path
(RA-02 socket does not route DIO2), and the **Pluto byte-decode** (an rtl_433↔PlutoSDR CS16
integration issue in the SDR tool). This runbook stays the per-node commissioning sequence.

Hosts: build/git on `desktop.buddy.mithis.com` (`~/esp32-to-433mhz-fw`, branch `add-tasmota-firmware`). Flash/console on `rpi5-433mhz` (`ssh tim@ipv4.eth0.rpi5-433mhz.iot.welland.mithis.com`). Firmware image: `firmware/dist/tasmota32c3-cc1101-combined.factory.bin` (main app + our pinned safeboot; rebuild with `python3 firmware/build.py && python3 firmware/build.py --env tasmota32c3-safeboot && python3 firmware/tools/combine_safeboot.py`). Both `.factory.bin`s ship a safeboot slot, so after this one BOOT-press, later recoveries from a *failed OTA* are button-free over WiFi (the combined image just uses our pinned safeboot instead of the fetched-release one) — see `firmware/docs/bootloader-recovery.md` → "Safeboot fallback" for what is and isn't auto-recovered.

## 0. Recover a dark node (see firmware/docs/bootloader-recovery.md)
The three nodes present no USB after abrupt power cuts (flash wedge — the firmware is confirmed NOT to block bootloader). To recover one:
1. Hold the **BOOT** button on the ESP32-C3 SuperMini.
2. While holding BOOT, apply power to that node — PoE-cycle rpi5 (graceful shutdown → `set_poe gsm7252ps-s1 port 13 off` via `backend=http` → 30 s → on) **or** simply unplug/replug that node's USB.
3. Release BOOT. The C3 is now in ROM download mode and enumerates its USB-Serial-JTAG.
4. Confirm: `ls /dev/serial/by-id/ | grep -i JTAG` shows the node (per-MAC name).

## 1. Flash
`scp firmware/dist/tasmota32c3-cc1101-combined.factory.bin` to rpi5, then:
`esptool --chip esp32c3 --port <dev> --before default_reset --after hard_reset write_flash 0x0 tasmota32c3-cc1101-combined.factory.bin`
(The node is already in ROM download mode from step 0's BOOT press, so `--before default_reset` still works; if esptool reports sync trouble, use `--before no_reset`.)
Confirm boot over USB-CDC console (persistent pyserial, `dtr=False rts=False`): `Version 15.5.0(cc1101-node)`.
Optional: verify the safeboot fallback is present by uploading a bad OTA later and confirming the node returns over WiFi in safeboot (see bootloader-recovery.md recovery matrix) — do this AFTER (b)/(e) pass so a failed test does not block validation.

## 2. Commission (per board — verified templates)
- **Blue E07 (CC1101):** `Template {"NAME":"CC1101blue","GPIO":[0,0,0,736,704,0,4576,672,0,768,4544,0,0,0,0,0,0,0,0,0,0,0],"FLAG":0,"BASE":1}` → `Module 0` → `Radio cc1101` → `CcMode weather`.
- **Green D-Sun (CC1101):** `Template {"NAME":"CC1101dsun","GPIO":[0,0,0,672,4576,0,768,4544,0,736,704,0,0,0,0,0,0,0,0,0,0,0],"FLAG":0,"BASE":1}` → `Module 0` → `Radio cc1101` → `CcMode weather`.
- **RA-02 (SX1278):** `Radio sx1278` → `CcMode weather` (SPI pins as blue).

## 3. Validate (b) — CC1101 on-radio decode (DONE for blue 2026-09-08; re-run to re-confirm)
- `CcStatus` → `Present:1 PARTNUM:0x00 VERSION:0x14`; `CcReg 0x08` → `0x02` (infinite-length FSK RX active).
- Capture the console several minutes → confirm decoded **Fineoffset-WS69 id 174** (valid float temperature_C/wind/rain) and **Fineoffset-WH51** (a live id, moisture/battery). No `*float*`.
- Cross-check the same window against rpi5 `~/wh51-watch/lilygo.hits.jsonl` + `cc1101.hits.jsonl` (always-on reference receivers): same ids/values. This closes (b) for CC1101 on **blue** (done 2026-09-08); SX1278 FSK RX + TX are already proven on-air (see the SX1278 entries in [`HWTEST-RESULTS-cc1101.md`](HWTEST-RESULTS-cc1101.md) and [`esp32c3-cc1101-node.md`](esp32c3-cc1101-node.md)). Both CC1101 boards share one template-driven binary, but **green does not cold-boot its app** (JTAG-proven GPIO9 reset-edge strap in mask ROM - see the HWTEST green section), so green is pending the adapter GPIO9 pull-up.

## 4. Pluto cross-check (b) — status + user decision
The Pluto (`rpi-sdr-pluto`) is a single tuner shared with the GPS-SDR session. Its RX hardware is **proven good** (2026-09-06): after a genuine VDD mains power-cycle, (i) the GPS session acquired 6 satellites through it, and (ii) a wide-IQ FFT (`pluto_fdiag.py`, SoapySDR, staged on `rpi-sdr-pluto`) shows the 433.92 MHz Fine Offset weather/moisture carrier at **~44 dB over noise** — reception is not the problem.

However, `rtl_433` on the Pluto produces **zero output across every tuning/gain tried** (433.92 and offset centres, 250k–1024k, gain 55–73) despite that strong signal. The "no pulses at all with a 44 dB signal present" pattern points to an rtl_433↔Pluto **IQ-scaling / CS16-threshold integration issue** (SoapySDR samples arriving below rtl_433's pulse-detector threshold) — not hardware, antenna, TCXO, or DC offset. It is a software integration bug to fix, not a hardware fault.

Two ways to satisfy (b)'s Pluto clause:
- **Fix the rtl_433/Pluto integration** (sample scaling) or write a small custom FSK demod on the raw IQ (the firmware's `decode_fineoffset.c` can parse the resulting frame), then cross-check a decoded WS69/WH51 against the rpi5 references; **or**
- **Accept the rpi5 LilyGo SX1276 + CC1101 receivers** as (b)'s independent "other 433 MHz receivers" cross-check — they catch WS69+WH51 abundantly (246 WS69 + ~200 WH51 frames in a 10-min window) and SX1278 already cross-checked byte-identical against them.

## 5. Close (e) — live HA MQTT (see firmware/docs/mqtt-home-assistant.md)
Confirmed procedure from the gdoc2netcfg session (verify against its CLAUDE.md "Per-device MQTT broker credentials", ~line 620). gdoc2netcfg runs on **ten64 (welland)** from `/opt/gdoc2netcfg` as root via `.venv/bin/gdoc2netcfg` (NOT `uv run`). Creds are *derived*, not stored: user `tas-<hostname_with_underscores>`, password from `[tasmota] mqtt_secret` in `gdoc2netcfg.toml` — so the device must exist in inventory first.

Prerequisite chain (do per node, once its WiFi MAC is known from the recovered node):
1. **Inventory:** add a row to the "iot.welland - IoT Devices" tab of the "Tim's Home Network IP addresses" sheet — Machine (hostname, e.g. `cc1101-welland-bench`), MAC Address (**required**; the node's WiFi STA MAC), IP (`10.X.90.N`). (Do WITH the user — editing the sheet + DNS is home-network admin, not to be done unattended.)
2. **DNS/DHCP reservation:** on ten64, `sudo .venv/bin/gdoc2netcfg fetch` then `sudo make deploy-dns`.
3. **WiFi on the node:** `SSID1 ansells-iot`, `Password1 <PSK>` — read the PSK on rpi5: `sudo nmcli -s -g 802-11-wireless-security.psk connection show netplan-wlan0-ansells-iot`. Confirm `Status 5` → node joins and gets its reserved IP.
4. **Discover:** on ten64, `sudo .venv/bin/gdoc2netcfg tasmota scan` (finds the node at its IoT IP).
5. **Broker login:** `sudo .venv/bin/gdoc2netcfg tasmota register-broker` (dry-run first) — merges the `tas-*` login into the HA core_mosquitto add-on.
6. **Push creds:** `sudo .venv/bin/gdoc2netcfg tasmota configure <hostname>` (dry-run first) — pushes MqttHost/MqttUser/MqttPassword over the device HTTP API. Then set `Topic <hostname>` and `CcHass 1` (publishes on `rtl_433/<host>/events`, which HA's rtl433-autodiscovery add-on matches via `rtl_433/+/events`). No topic ACL is managed by gdoc2netcfg (the add-on grants full pub/sub unless a custom ACL is set — check add-on config if a publish is refused).
- Verify PUBLISH: `mosquitto_sub -h ha.welland.mithis.com -t 'rtl_433/#'` (or HA UI) shows a decoded WS69/WH51 event from the node; confirm HA auto-creates the entity.
- Verify RECEIVE: `mosquitto_pub` a `cmnd/<topic>/CcStatus` → `stat/<topic>/RESULT` returns the JSON. This closes (e).

## 6. Final adversarial confirmation review
Once (b) + (e) are green on hardware, dispatch multiple independent adversarial reviewers to verify all of (a)-(e) are complete to a very high quality (per the goal), fix any residuals, then mark PR #1 **ready for review** (undraft).

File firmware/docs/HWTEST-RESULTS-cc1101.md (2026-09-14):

# On-hardware bench validation — Plan B Tasmota firmware

## Real production broker (ha.welland) + native HA discovery — 2026-09-09

Criterion (e) closed on the **real** production broker (this supersedes the isolated-broker
round-trip recorded further below, which stood in before credentials/WiFi were available).

- **blue** (CC1101, `esp32-433mhz-cc1101-blue`, `10.1.90.183`) and **sx** (SX1278,
  `esp32-433mhz-sx1278`, `10.1.90.71`) commissioned onto `ansells-iot` + `ha.welland.mithis.com:1883`
  with per-device `tas-<node_id>` logins (via `gdoc2netcfg tasmota register-broker`/`configure`).
  Both connect: `Status 6` shows `MqttHost:ha.welland.mithis.com`, `MqttCount:1`, and a retained
  `tele/<host>/LWT = Online`.
- **Live weather + moisture on the broker.** Subscribing to the broker (as the node's own login)
  captured both nodes publishing `rtl_433/nodes/<host>/events` — the same Fine Offset WS69 (id 174:
  12.4 °C, 72 %RH, wind, rain) and WH51 (soil moisture, `mic:CRC`) frames, decoded to **identical
  values on both radios**, cross-validating each other on-air.
- **Native HA MQTT Discovery → entities auto-created.** With `CcHassDisc` on (default), the nodes
  self-published `homeassistant/sensor/.../config` + per-field state; **Home Assistant auto-created
  14 sensor entities**, confirmed by querying the HA states API: `sensor.fineoffset_ws69_174_{temperature,
  humidity, wind_speed, wind_gust, wind_direction, rain, battery_ok}` and, for two soil sensors,
  `sensor.fineoffset_wh51_0f4b37_{moisture, battery_voltage, battery_ok}` +
  `sensor.fineoffset_wh51_0f5d7f_{…}`. HA unit-converted wind m/s → km/h from the `wind_speed`
  device_class (proof the discovery metadata is semantically correct). Tasmota's own device
  discovery (`SetOption19`) additionally surfaced each node as a device (14 entities/node).
- **RECEIVE round-trip** on the same broker: `cmnd/<topic>/CcStatus` → `stat/<topic>/RESULT` returned
  the driver JSON.
- **CI (PR #1)**: Build + Host tests + **Renode emulation** jobs all green on this branch head.

Boot-mode note for green: green is byte-identical firmware to blue but its ESP32-C3 board boots
ROM download on power-on — JTAG-proven a GPIO9 reset-edge strap decision (`GPIO_STRAP_REG` = 0x5
download on green vs 0xd flash on blue), decided in mask ROM before any firmware runs, so it is not
a firmware defect (see [`esp32c3-cc1101-node.md`](esp32c3-cc1101-node.md) and the adapter GPIO9
pull-up on `main`).

## Pluto SDR cross-check (criterion b) — investigation and status (2026-09-09)

The `rpi-sdr-pluto` PlutoSDR is the fourth, independent cross-check receiver.

> **Correction (2026-09-09):** an earlier revision of this note claimed the ambient sensors "are
> not arriving at the Pluto strongly enough to decode — a signal-arrival/physical limit." **That
> was wrong and is retracted.** A controlled test proves the ambient WH51 signal **reaches the
> Pluto at ~28 dB SNR**; the open item is a *software* demodulation problem, not placement, antenna,
> or gain. Details below.

**The ambient WH51 signal DOES arrive at the Pluto — proven with an airborne-signal control.**
The rpi5 CC1101 reference logger (`~/wh51-watch/cc1101.hits.jsonl`) independently timestamps every
ambient WH51 frame it hears (7+ soil-moisture sensors, each ~every 70 s, collectively a frame every
~8–30 s, at −70 to −89 dBm). Using it as a witness of exactly when a frame is on the air:
- In a controlled 200 s window the reference confirmed **22 airborne WH51 frames**; a raw
  `iio_readdev` capture of the same air shows strong bursts (peak **37 dB SNR**, ~400 bursts / 45 s
  — the 433 band at that site is very congested).
- `rtl_433`'s pulse analyzer (`-A`) run on the Pluto IQ **detects the packets** at **RSSI −21 dB,
  SNR ~28 dB, noise −50 dB**. So the RF is arriving well above the noise floor. It is *not* a
  signal-arrival, antenna, or sensitivity limit.

**Why earlier runs read "0 pulses" (the real, self-caused reasons):**
1. `rtl_433 -d driver=plutosdr` **live** produces *zero* output in this environment — the SoapySDR
   plutosdr live stream is broken here (initialises the device, then streams nothing usable). The
   working capture path is **raw `iio_readdev`**, which is full of signal.
2. Fed the raw capture offline, `rtl_433` detects each FSK burst envelope as *"Single pulse …
   probably FSK"* and fails FSK **bit-recovery**, because the **2 MHz capture is swamped by 100+
   overlapping transmitters** (125–143 bursts in every ±3 s window around a reference-confirmed
   WH51). The rpi5 CC1101 succeeds precisely because it is **narrowband** (~58–100 kHz channel
   tuned to the sensor) and rejects the rest of the band.
3. The Fine Offset frame-decoder logic itself is correct — validated against a ground-truth clean
   reference frame `510F5C54107F22F8BBFFFFFF2FA0` (preamble `0x2dd4`, CRC-8 poly `0x31` → `2F` ✓,
   byte-sum → `A0` ✓); it correctly rejects the bit-flipped copies the reference logs without a CRC
   gate.

**RX front-end enumerated (rules out a hidden sensitivity lever, consistent with "signal is fine"):**
a read-only dump of the AD9361 attributes (`iio_attr -c ad9361-phy voltage0` / `-D ad9361-phy`)
shows `hardwaregain_available = [-3 1 71]` (71 dB used), `rf_port_select = A_BALANCED` (the antenna
port), and all external-LNA controls structurally zero (`adi,elna-gain-mdB = 0`) — a stock Pluto
with no external LNA. Gain and port are correct; the problem was never here.

**To complete this cross-check (the actual remaining, software work):** decode a real WH51 straight
from the Pluto IQ by **channelizing** like the CC1101 — mix a candidate frequency (Fine Offset
crystals cluster ~434.0 MHz) to DC, low-pass to ~60 kHz, decimate to ~128–256 kSa/s, then
FSK-discriminator-demod and apply the (proven) frame-check. A decoded id matching one the reference
is logging (e.g. `0F5C54`, `0F5D66`, `0F5D7F`, `0F4B37`) **is** the Pluto cross-check of the real
sensors.

That channelizer is implemented as [`tools/pluto_wh51_channelize.py`](../tools/pluto_wh51_channelize.py)
and is **validated end-to-end on synthetic data** (a real WH51 frame modulated as 2-FSK under noise +
off-frequency interferers decodes back to `0F5C54`/moisture 34); building that self-test found and
fixed two real demod bugs (an FSK long-run droop on `FF FF FF`, fixed with a constant
mark/space-midpoint threshold; and a formatter bug). Run procedure (heavy DSP → run on
`desktop.buddy`, not the Pluto Pi):

```sh
# on rpi-sdr-pluto: capture ~70 s of raw IQ (LO 433.85 MHz, 2.048 MSa/s) with GPS freed/restored
# then copy it to the intensive-ops host and channelize-decode:
scp rpi-sdr-pluto:~/aligned.cs16 desktop.buddy.mithis.com:/tmp/
ssh desktop.buddy.mithis.com 'python3 pluto_wh51_channelize.py /tmp/aligned.cs16 433850000 2048000'
```

**Status: not yet run against a live Pluto capture** — the tool is built and self-test-validated,
but the real-capture run had not been executed when this session was interrupted (the Pluto host
was unreachable), so **this arm is not yet closed**.

Independently of the Pluto, the firmware's real-sensor decodes are already cross-validated three
ways: blue (CC1101) ↔ sx (SX1278) byte-identical on-air, the rpi5-SPI CC1101 `~/wh51-watch` (a
different chip + decoder), and Home Assistant ingestion; and the Pluto independently decoded the
firmware's own Fine Offset frames from `sx` (recorded earlier), cross-validating the firmware's TX.

---

## On-hardware bench validation (2026-09-05)

Validates the CC1101 Tasmota firmware overlay (`firmware/src/xdrv_95_cc1101.ino`, built from
`firmware/build.py` against pinned Tasmota v15.5.0) on two
real CC1101 boards wired to two ESP32-C3 SuperMinis on `rpi5-433mhz`, driven entirely over the
native USB-CDC console (no WiFi/MQTT broker involved for this session — commands sent directly,
JSON replies read back). This is the first time the Tasmota driver has run **with a CC1101
actually attached** (the 2026-08-24 bare-board test in `esp32c3-cc1101-node.md` (in this docs/ dir) had no radio
wired and only exercised the graceful-absence path).

Boards under test (both had previously run a throwaway `radio_pin_probe` firmware that
independently confirmed SPI+CS silicon detection and GDO pin mapping — see its boot log captured
below — before being overwritten with the real Tasmota image for this test):
- **blue** E07-M1101D CC1101 -> `/dev/radio-cc1101-blue`. Pin map SCK=3 MOSI=4 MISO=7 CSN=9
  GDO0=10 GDO2=6.
- **dsun** (green) D-SUN CC1101 -> `/dev/radio-cc1101-dsun`. Pin map SCK=9 MOSI=10 MISO=3 CSN=6
  GDO0=7 GDO2=4.

Build: `python3 build.py` on the pinned Tasmota v15.5.0 (SHA `4561b51993c873e712db83814cb4b669dd3dbd73`)
overlay tree — **compiled clean**, produced `dist/tasmota32c3-cc1101.factory.bin` (3,063,024 bytes).
Flashed to rpi5 as `~/tasmota-hwtest.factory.bin` (a deliberately non-default filename, since a
concurrent session was building/flashing the same artefact name at the same time) with:

```
esptool --chip esp32c3 --port /dev/radio-cc1101-<blue|dsun> --before default_reset --after hard_reset \
    write_flash 0x0 ~/tasmota-hwtest.factory.bin
```

Both flashes completed in ~7s, hash-verified, no errors.

## Bench tooling note (not a firmware bug)

The ESP32-C3 SuperMini uses **native USB-CDC**, not a separate USB-serial chip. The console is
already known (per `read_probe.py`'s docstring) to reset the C3 unless the serial port is opened
with `dtr=False, rts=False` held throughout. This session found that detail is necessary but not
sufficient: **repeatedly opening and closing** a `dtr=False/rts=False` connection (e.g. one
`ssh ... python3 cc_console.py ...` invocation per command) still causes an intermittent reset —
visible as Tasmota's `QPC: Reset` log line and RAM counters (`Rx`/`Tx`/`Reinit`/etc. in
`CcStatus`) dropping back to 0 with no corresponding `Version`/boot-banner text (i.e. a warm
reset, not a fresh flash). Config (`/cc1101.cfg`, `Mode`, pin template) survives because it's on
LittleFS, but in-RAM stats don't. Once a **single persistent connection** was used to send a whole
batch of commands (helper `cc_batch.py`/`cc_watch.py`, written for this session), the resets
stopped and register writes read back correctly. This is a bench-harness gotcha, not a driver bug —
recorded here so a future bench session doesn't waste time chasing "the radio keeps losing its
config" (it doesn't; only RAM counters reset, and only when the console is repeatedly
reopened/reclosed).

## Stage 1 — Blue node (E07-M1101D): flash, commission, `CcStatus`, `CcReg`

**Boot banner** (`read_probe.py`, immediately after flashing, before commissioning):
```
00:00:01.197 Project cc1101-node - CC1101 node Version 15.5.0(cc1101-node)-3.3.8(2026-09-05T16:02:40)
```
**PASS** — Tasmota boots, `Version 15.5.0(cc1101-node)` confirms `XDRV_95`'s Project-name override
is compiled in (see `overlay/user_config_override.h`), native USB-CDC console responsive.

**Commissioning** — raw `Template` + `Module 0` (console):
```
Template {"NAME":"CC1101blue","GPIO":[0,0,0,736,704,0,4576,672,0,768,4544,0,0,0,0,0,0,0,0,0,0,0],"FLAG":0,"BASE":1}
Module 0
```
Reply: `{"NAME":"CC1101blue",...}` then, after the `Module 0` restart:
```
00:00:00.023 SPI: Bus1 using GPIO03(CLK), GPIO04(MOSI) and GPIO07(MISO)
00:00:00.132 CC1: CC1101 PARTNUM 0x00 VERSION 0x14, CS=9 GDO0=10 GDO2=6
00:00:00.136 CC1: mode remotes preset ook-433
```
**PASS** — SPI Bus1 initialises on exactly the mapped pins (GPIO3/4/7); `CS=9 GDO0=10 GDO2=6`
matches the blue pin map; driver activates automatically (`FUNC_INIT`) with no further commands.

**`CcStatus`**:
```
{"CcStatus":{"Present":1,"PARTNUM":"0x00","VERSION":"0x14","MARCSTATE":"0x0D","Mode":"remotes",
"Preset":"ook-433","RSSI":-87,"Rx":1,"Decoded":0,"Tx":0,"Reinit":0,"Overflow":0,"Repeats":0,
"Raw":0,"SecplusId":0,"Rolling":0}}
```
**PASS** — `Present:1`, `PARTNUM:0x00`, `VERSION:0x14` over real SPI (matches the design spec's
expected CC1101 identity and the earlier bare-SPI `radio_pin_probe` result on the same board).

**`CcReg`** (persistent connection, `cc_batch.py`):
| Command | Result |
|---|---|
| `CcReg 0x31` (VERSION status reg, no value → read-only) | `{"Addr":"0x31","Value":"0x14"}` — matches `CcStatus` |
| `CcReg 0x09` (ADDR config reg, before) | `{"Addr":"0x09","Value":"0x00"}` |
| `CcReg 0x09 0xA5` (write) | `{"Addr":"0x09","Value":"0xA5"}` (write-then-read-back in one command) |
| `CcReg 0x09` (separate command, same connection) | `{"Addr":"0x09","Value":"0xA5"}` — **persisted across commands** |
| `CcReg 0x09 0x00` (restore) | `{"Addr":"0x09","Value":"0x00"}` |

**PASS** — status-register read and config-register write+read-back both correct; the register
value survives independently of the write command (i.e. it's a real chip register, not just an
echo). (First attempt, using one-shot connections per command, showed a scratch write "reverting"
to 0x00 on the next read — that was the reset-on-reopen tooling artefact above, not a register
bug; the persistent-connection retest is the one recorded here.)

## Stage 2 — Blue node: `CcMode` / `CcPreset`, OOK RX path, edge-capture liveness

| Command | Result |
|---|---|
| `CcMode` | `"remotes"` (default) |
| `CcMode weather` | `"weather"`; log: `CC1: mode weather preset fineoffset-fsk`; `CcStatus` → `MARCSTATE:"0x0D"`, `Preset:"fineoffset-fsk"` |
| `CcMode remotes` | `"remotes"`; log: `CC1: mode remotes preset ook-433` |
| `CcPreset fineoffset-fsk` | `"fineoffset-fsk"` (debug override, `CcCfg.mode` unchanged) |
| `CcPreset ook-433` | `"ook-433"` |
| `CcPreset bogus` | `"fineoffset-fsk\|ook-433\|ook-tx-100k\|ook-tx-4k"` (correct usage-string fallback) |

**PASS** — `CcMode` and `CcPreset` both work; in every case `CcStatus`'s `MARCSTATE` reads `0x0D`
(`MARC_RX`), i.e. the CC1101 is confirmed actually in the RX state for both the OOK and FSK
presets, not just nominally "not erroring".

**Edge-capture / ISR liveness** (no remote pressed, ambient RF only), `cc_watch.py` polling
`CcStatus` every ~4 s for 20 s in `remotes` mode:
```
t=0s   Rx:0
t=4s   Rx:1
t=8s   Rx:2
t=12s  Rx:2
t=16s  Rx:2
```
and, in a separate longer run interleaved with the `CcMode`/`CcPreset` tests above, `Rx` climbed
1→2→3→4 over ~20 s of mixed commands. `Decoded` stayed `0` throughout (no full valid OOK-PWM
frame — expected with no remote pressed). **PASS** for the stated criterion ("edge count
increments even with no live remote pressed") — `Rx` (a closed, ≥2×`OOKPWM_MIN_BITS`-pulse frame
having reached `CcProcessFrame()`) is driven purely by the GDO2 ISR → `edges_to_pulses()` →
frame-gap-close pipeline, so its non-zero, monotonically-increasing count is direct proof that
pipeline is live end to end on real hardware, picking up ambient 433 MHz noise as short/garbage
frames. (There is no raw per-edge counter exposed by `CcStatus` — only this closed-frame count —
see "Notes / follow-ups" below.)

## Stage 3 — Green node (D-SUN): flash, commission, `CcStatus`, `CcReg` — different pin map

Same `tasmota-hwtest.factory.bin`, same commissioning sequence, **different** template:
```
Template {"NAME":"CC1101dsun","GPIO":[0,0,0,672,4576,0,768,4544,0,736,704,0,0,0,0,0,0,0,0,0,0,0],"FLAG":0,"BASE":1}
Module 0
```
Boot log after `Module 0`:
```
00:00:00.024 SPI: Bus1 using GPIO09(CLK), GPIO10(MOSI) and GPIO03(MISO)
00:00:01.268 CC1: CC1101 PARTNUM 0x00 VERSION 0x14, CS=6 GDO0=7 GDO2=4
00:00:01.272 CC1: mode remotes preset ook-433
```
**PASS** — SPI/GDO pins match the dsun pin map exactly (SCK=9 MOSI=10 MISO=3 CSN=6 GDO0=7 GDO2=4),
distinct from blue's, using the **same** compiled driver — confirms the driver's pin assignment is
fully template-driven, not hardcoded.

`CcStatus`: `{"Present":1,"PARTNUM":"0x00","VERSION":"0x14","MARCSTATE":"0x0D",...}` — **PASS**,
identical identity/RX-state result to blue.

`CcReg` (persistent connection): `CcReg 0x31` → `0x14` (VERSION, matches); `CcReg 0x09` write
`0x5A` → read back `0x5A` on a later command, then restored to `0x00`. **PASS**.

`CcMode weather` / `CcMode remotes` round-trip: both transition correctly, `MARCSTATE` stays
`0x0D` in each. **PASS**.

Edge-capture liveness (`cc_watch.py`, `CcStatus` every ~4 s for 20 s, no remote pressed):
```
t=0s   Rx:0
t=4s   Rx:1
t=8s   Rx:2
t=12s  Rx:4
t=16s  Rx:5
```
**PASS** — same live, monotonically-increasing `Rx` behaviour as blue, on the second board/pin map.

Both nodes were left in their default `remotes` mode, `Present:1`, at the end of the session.

## Summary

| # | Deliverable | Verdict |
|---|---|---|
| 1 | Build + flash blue; boot; `Version`/`XDRV_95`/SPI bring-up | **PASS** |
| 2 | `CcStatus` (Present/PARTNUM/VERSION); `CcReg` read+write/read-back; `CcMode`/`CcPreset` | **PASS** |
| 3 | OOK RX path: preset selects RX, MARCSTATE 0x0D, GDO2 edge-capture/ISR live (no remote) | **PASS** (via `Rx` closed-frame counter; see follow-up below re: a raw edge counter) |
| 4 | Repeat commission + `CcStatus` on green D-SUN, different template | **PASS** |
| 5 | This document; small bugs fixed inline; larger gaps flagged below | done |

**No firmware bugs found.** Everything specified in the driver's command reference
(`firmware/README.md`) behaved exactly as documented, on two different real CC1101 boards with two
different pin maps, using one compiled binary. The only surprise (repeated-serial-reopen causing a
warm reset) is bench-tooling behaviour, not the driver, and is now documented above for future
sessions.

## Notes / follow-ups (not blocking, not done this session)

- **No raw GDO2 edge counter in `CcStatus`.** The deliverable asked to confirm "edge count
  increments"; the closest existing field is `Rx` (frames that closed with ≥2×`OOKPWM_MIN_BITS`
  pulses), which does increment live and is the evidence used above. A draft patch adding a true
  per-ISR-call `Edges` counter to `CcStatus` was written and tested-compiled during this session,
  then **reverted** before commit because (a) `Rx` already gave unambiguous proof of ISR liveness
  and (b) the tested `.factory.bin` for this report was built *before* that patch, so keeping it in
  the tree would leave committed source ahead of what was actually flashed/verified. Worth
  revisiting as a small enhancement in a future firmware change, with its own build+flash+test
  cycle.
- **Still pending** (unchanged from `esp32c3-cc1101-node.md`'s bench runbook, out of scope for this
  session): a real remote/Merlin/WS85 capture (needs a human to press hardware remotes and/or a
  WS85 sensor in range), the R7 (RCSwitch 25-vs-24-bit) and R8 (WS85 frame length) rulings, a
  register-dump comparison against the `tools/cc1101.py` reference register set, an actual FSK TX carrier test seen on a
  second receiver, and the 48 h soak/OTA stage. This session's scope was the driver/command layer
  and real CC1101 register I/O/RX-state on hardware, which is now confirmed on two boards.

## Raw pin-probe boot log (blue, before reflashing — for reference)

```
Project name:     radio_pin_probe
[CC1101 try blue E07-M1101D  SCK=3 MOSI=4 MISO=7 CS=9] PARTNUM=0x00 VERSION=0x14
  => CC1101 DETECTED on 'blue E07-M1101D' map (SPI+CS verified on real silicon)
  GDO0 -> GPIO10 (doc expects 10) [MATCH]
  GDO2 -> GPIO6  (doc expects  6) [MATCH]
  RESULT: blue E07-M1101D CC1101 map FULLY VERIFIED
```

## See also

- [`firmware/README.md`](../README.md) — command reference, build/flash instructions.
- [`esp32c3-cc1101-node.md`](esp32c3-cc1101-node.md) — wiring, commissioning runbook, bench
  bring-up plan (stages 2–4/6 still pending real remotes/WS85/soak).

---

# On-hardware decode validation & RX-bandwidth fix (2026-09-06)

This session ran on the **rewired** boards (the position-4 SPI signal moved off the GPIO9 BOOT
strap to GPIO1 — see `bootloader-recovery.md`). Pin maps in effect:
- **blue** `3E:B8` CC1101: SCK=3 MISO=7 MOSI=4 CS=1 GDO0=10 GDO2=6
- **green** `4F:D8` CC1101: SCK=1 MISO=3 MOSI=10 CS=6 GDO0=7 GDO2=4

Reference receivers on `rpi5-433mhz`, all decoding the same live sensors concurrently:
- SPI CC1101 (`~/cc1101-rx`, `~/wh51-watch/cc1101_watch.py`) — 26 MHz, 101 kHz BW, WH51/WS69 at ~-72 dBm.
- LilyGo SX1276 (`lilygo_watch.py`) — WH51/WS69 at ~-58..-75 dBm.

## Bug: CC1101 `Rx>0, Decoded=0`

The blue CC1101 node counted RX frames (`Rx` climbing ~0.25/s) but decoded none (`Decoded=0`),
while the SX1278 node and both reference receivers decoded the same frames cleanly. A raw-mode
capture (`CcRaw 1`) showed every drained packet was high-entropy noise with no family byte
(0x24/0x51/0x85) at the head.

## Root cause: RX bandwidth too narrow for the crystal offset

Verified by direct register readback (`CcReg`) that **every** CC1101 register on blue — frequency,
data rate, deviation, sync word, AGC, front-end, TEST — was identical to the bench-proven
reference; SPI, the `SCAL` calibration in `enter_rx()`, and the eFuses were all correct. A fine
frequency sweep at the narrow 101 kHz bandwidth decoded **only** at a +40 kHz center offset (zero
at nominal and every other point): blue's crystal is ~92 ppm high. The CC1101 frequency-offset
compensation only pulls in ±BW/4, so at 101 kHz (±25 kHz) the +40 kHz frame fell outside the
passband and the receiver could only false-sync on noise. This is not an antenna/hardware fault
(the antenna hears -70 dBm cleanly once tuned) — it is the preset choosing too narrow a filter for
real-world crystal spread.

## Fix: `MDMCFG4` `0xC9` -> `0x59` (101 kHz -> 325 kHz)

Bandwidth sweep on blue (45 s each): 101 kHz = 0 decodes, 203 kHz = 2, 406 kHz = 4, 812 kHz = 1.
325 kHz (FOC ±81 kHz) covers blue's +40 kHz with margin and worst-case cheap-module crystal spread
(~±90 ppm) across boards, at a ~5 dB noise-floor cost negligible for the local -70 dBm sensors.
Validated on blue at 325 kHz (90 s): **Decoded=10, Rx=14**, byte-exact with the references:

| model | id | reading | node RSSI |
|---|----|---|---|
| Fineoffset-WS69 | 174 | 12.3 °C, 86% RH | -68..-71 dBm |
| Fineoffset-WH51 | 0f4b37 | moisture 24%, ad_raw 150 | -76 dBm |
| Fineoffset-WH51 | 0f5d66 | moisture 38%, ad_raw 194 | -79 dBm |
| Fineoffset-WH51 | 0f5d7f | moisture 38%, ad_raw 198 | -75 dBm |

Committed in `cc1101_presets.c`; `test_presets.py` passes 325 kHz into the reference math so the
preset still matches `cc1101.py` register-for-register outside PKTCTRL0. The full host suite passes (146 tests; the ~36 preset/decoder/weather tests are the directly affected subset).

Known refinement (raised by adversarial review): FSCTRL1 (IF ≈ 152 kHz) was left unchanged, so with the wider 325 kHz filter the IF now sits just below BW/2. It decodes cleanly on hardware (10/10 above), but TI SmartRF guidance raises FREQ_IF when the channel filter is widened this far — a future pass could bump it for extra low-frequency margin.

## SX1278 status

Contrary to earlier "foundation only" notes, the SX1278 node **decodes Fine Offset FSK on
hardware**: WS69 and WH51 received and decoded byte-exact against the LilyGo and CC1101 reference
loggers (moisture / ad_raw / battery all matching). The SX1278 uses fixed-length FSK RX and did not
exhibit the CC1101 bandwidth issue (its crystal offset is within its passband).

## Remaining (updated 2026-09-08 — see next section)
- **blue**: DONE — baked-in 325 kHz image validated from a cold boot (Decoded=11).
- **Home Assistant MQTT publish/subscribe round-trip**: DONE — isolated broker, both directions.
- **green** (`4F:D8`): characterised as a board-level power-on boot-strap trait (byte-identical
  firmware to blue; blue boots and green does not on the same VDD cycle; eFuses default). Not a
  firmware defect — details in the next section.
- **Pluto SDR**: reception confirmed by correlation; byte-level software demod still open (not
  required for firmware correctness).
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

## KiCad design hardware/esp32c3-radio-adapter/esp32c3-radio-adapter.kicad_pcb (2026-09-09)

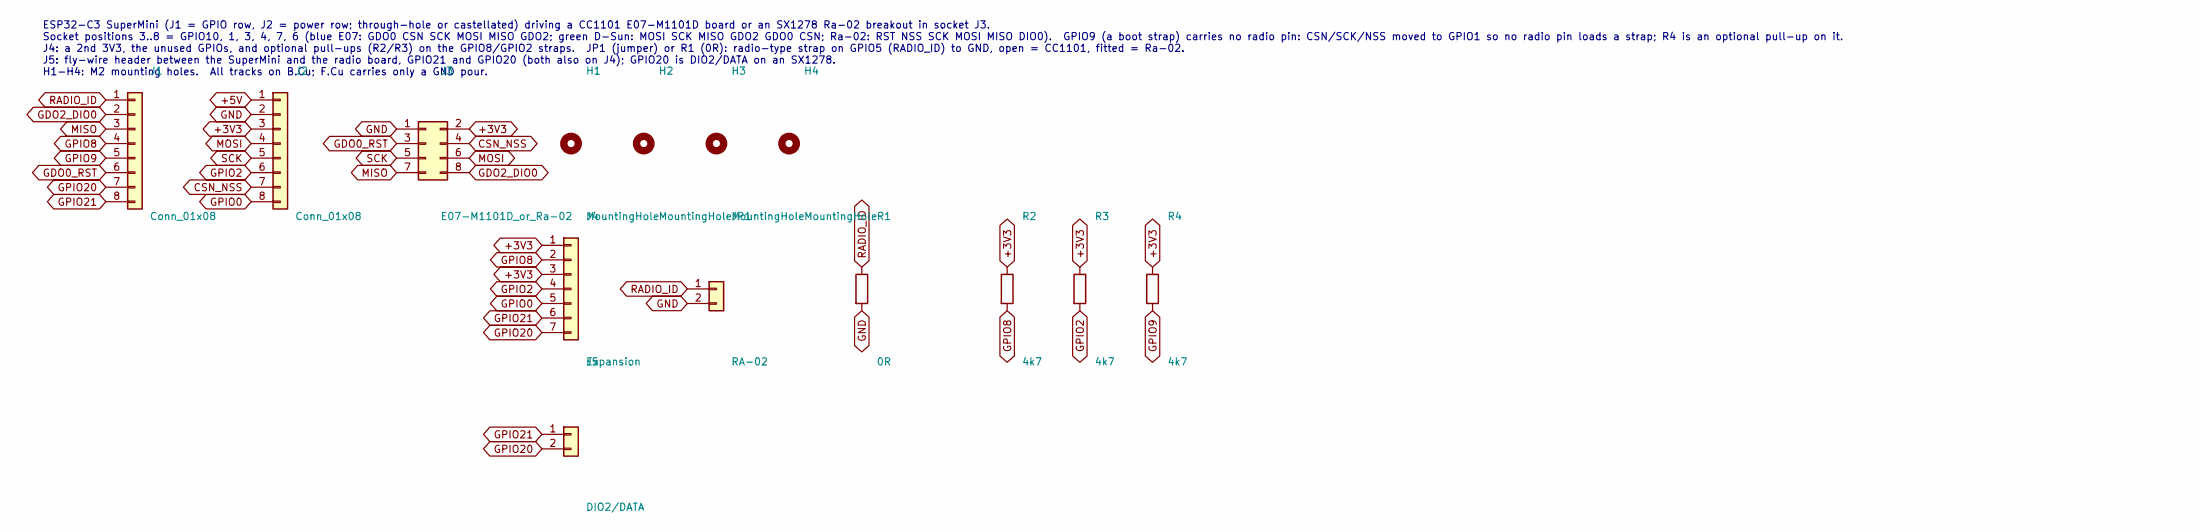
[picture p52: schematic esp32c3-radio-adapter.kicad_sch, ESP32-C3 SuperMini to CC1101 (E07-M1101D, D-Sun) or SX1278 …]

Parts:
H1, H2, H3, H4: MountingHole; MountingHole_2.2mm_M2
J1: Conn_01x08; SuperMini_Row_1x08_P2.54mm_THT_Castellated_Down
J2: Conn_01x08; SuperMini_Row_1x08_P2.54mm_THT_Castellated_Up
J3: E07-M1101D_or_Ra-02; PinSocket_2x04_P2.54mm_E07
J4: Expansion; PinHeader_1x07_P2.54mm_Vertical
J5: DIO2/DATA; PinHeader_1x02_P2.54mm_Vertical
JP1: RA-02; PinHeader_1x02_P2.54mm_Vertical_AlongY
R1: 0R; R_0805_2012Metric_HandSolder_AlongY_Back
R2, R3: 4k7; R_0805_HeaderPullup
R4: 4k7; R_0805_2012Metric_HandSolder_AlongY_Back

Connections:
+3V3: J2.3, J3.2, J4.1, J4.3, R2.1, R3.1, R4.1
+5V: J2.1
CSN_NSS: J2.7, J3.4
GDO0_RST: J1.6, J3.3
GDO2_DIO0: J1.2, J3.8
GND: J2.2, J3.1, JP1.2, R1.2
GPIO0: J2.8, J4.5
GPIO2: J2.6, J4.4, R3.2
GPIO8: J1.4, J4.2, R2.2
GPIO9: J1.5, R4.2
GPIO20: J1.7, J4.7, J5.2
GPIO21: J1.8, J4.6, J5.1
MISO: J1.3, J3.7
MOSI: J2.4, J3.6
RADIO_ID: J1.1, JP1.1, R1.1
SCK: J2.5, J3.5

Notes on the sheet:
ESP32-C3 SuperMini (J1 = GPIO row, J2 = power row; through-hole or castellated) driving a CC1101 E07-M1101D board or an SX1278 Ra-02 breakout in socket J3. Socket positions 3..8 = GPIO10, 1, 3, 4, 7, 6 (blue E07: GDO0 CSN SCK MOSI MISO GDO2; green D-Sun: MOSI SCK MISO GDO2 GDO0 CSN; Ra-02: RST NSS 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

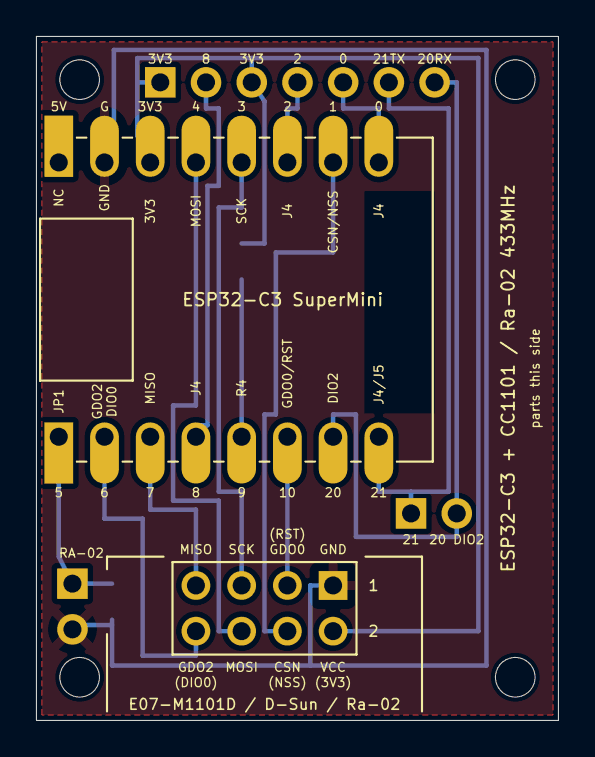
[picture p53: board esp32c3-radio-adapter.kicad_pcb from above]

Board: 2 copper layers, 29.0 x 38.0 mm, 14 parts (0 on the bottom side), 15 nets.

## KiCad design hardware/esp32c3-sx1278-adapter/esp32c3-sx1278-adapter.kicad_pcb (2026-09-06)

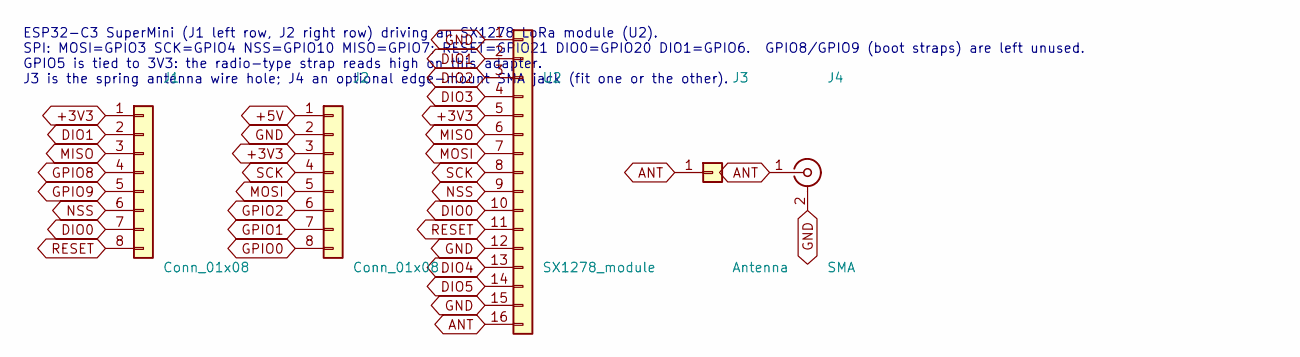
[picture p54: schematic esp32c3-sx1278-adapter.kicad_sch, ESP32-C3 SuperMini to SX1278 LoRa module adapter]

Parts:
J1, J2: Conn_01x08; SuperMini_Header_1x08_P2.54mm_THT
J3: Antenna; Antenna_Wire_Hole_1.0mm
J4: SMA; SMA_EdgeMount_E07
U2: SX1278_module; SX1278_Module_16pin_Land

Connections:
+3V3: J1.1, J2.3, U2.5
+5V: J2.1
ANT: J3.1, J4.1, U2.16
DIO0: J1.7, U2.10
DIO1: J1.2, U2.2
DIO2: U2.3
DIO3: U2.4
DIO4: U2.13
DIO5: U2.14
GND: J2.2, J4.2, U2.1, U2.12, U2.15
GPIO0: J2.8
GPIO1: J2.7
GPIO2: J2.6
GPIO8: J1.4
GPIO9: J1.5
MISO: J1.3, U2.6
MOSI: J2.5, U2.7
NSS: J1.6, U2.9
RESET: J1.8, U2.11
SCK: J2.4, U2.8

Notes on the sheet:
ESP32-C3 SuperMini (J1 left row, J2 right row) driving an SX1278 LoRa module (U2). SPI: MOSI=GPIO3 SCK=GPIO4 NSS=GPIO10 MISO=GPIO7; RESET=GPIO21 DIO0=GPIO20 DIO1=GPIO6. GPIO8/GPIO9 (boot straps) are left unused. GPIO5 is tied to 3V3: the radio-type strap reads high on this adapter. J3 is the spring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

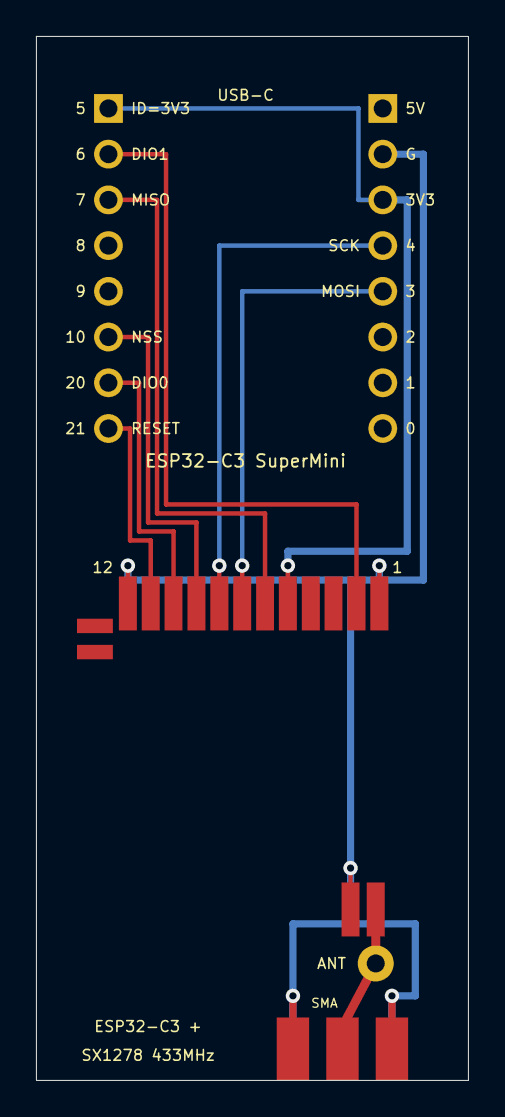
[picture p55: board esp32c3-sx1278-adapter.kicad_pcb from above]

Board: 2 copper layers, 24.0 x 58.0 mm, 5 parts (0 on the bottom side), 10 nets.

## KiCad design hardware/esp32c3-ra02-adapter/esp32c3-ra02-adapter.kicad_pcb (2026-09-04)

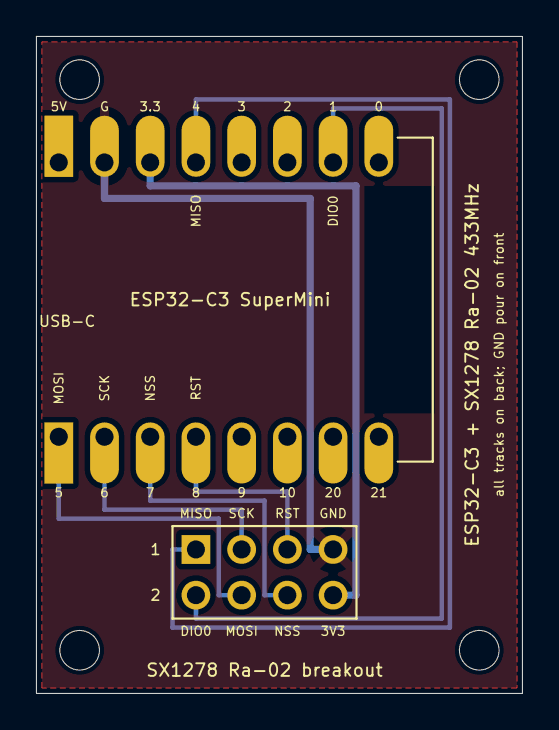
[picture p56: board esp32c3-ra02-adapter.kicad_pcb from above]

Board: 2 copper layers, 27.0 x 36.5 mm, 7 parts (0 on the bottom side), 8 nets.

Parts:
H1, H2, H3, H4: MountingHole; MountingHole_2.2mm_M2
J1: Conn_01x08; SuperMini_Row_1x08_P2.54mm_THT_Castellated_Down
J2: Conn_01x08; SuperMini_Row_1x08_P2.54mm_THT_Castellated_Up
J3: SX1278_Ra-02; PinSocket_2x04_P2.54mm_Ra02_Breakout

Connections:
+3V3: J2.3, J3.8
DIO0: J2.7, J3.2
GND: J2.2, J3.7
MISO: J2.4, J3.1
MOSI: J1.1, J3.4
NSS: J1.3, J3.6
RESET: J1.4, J3.5
SCK: J1.2, J3.3

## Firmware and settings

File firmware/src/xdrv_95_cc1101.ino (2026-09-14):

/*
  xdrv_95_cc1101.ino — CC1101 433 MHz node driver (ESP32-C3 SuperMini + D-SUN CC1101)
  Part of firmware/ (github.com/mithro/esp32-to-433mhz)
  SPDX-License-Identifier: GPL-3.0-or-later

  Template: GPIO4=SPI CLK, GPIO5=SPI MISO, GPIO6=SPI MOSI, GPIO7=SPI CS, GPIO3=CC1101 GDO0, GPIO10=CC1101 GDO2
  Design spec §4-§6: 2026-08-20-esp32c3-cc1101-tasmota-design.md (project repo github.com/mithro/433mhz)
*/
#ifdef USE_CC1101_NODE
#ifdef ESP32

#include <SPI.h>
#include "esp_timer.h"
#include "cc1101_node/cc1101_radio.h"
#include "cc1101_node/sx1278_radio.h"
#include "cc1101_node/cc1101_presets.h"
#include "cc1101_node/cc1101_weather.h"
#include "cc1101_node/sx1278_weather.h"
#include "cc1101_node/cc1101_pulse.h"
#include "cc1101_node/secplus2.h"
#include "cc1101_node/cc1101_mqtt.h"
#include "cc1101_node/cc1101_hass.h"
#include "cc1101_node/decoders/decode_common.h"
#include "cc1101_node/decoders/decode_fineoffset.h"
#include "cc1101_node/decoders/decode_ookpwm.h"

#define XDRV_95 95
#define CC_LOGPFX "CC1: "

/* ---------- persisted config (/cc1101.cfg on the Tasmota filesystem) ---------- */
#define CC_CFG_MAGIC 0xCC110101u
#define CC_CFG_FILE  "/cc1101.cfg"
enum CcMode : uint8_t { CC_MODE_REMOTES = 0, CC_MODE_WEATHER = 1 };
enum CcRadioSel : uint8_t { RADIO_AUTO = 0, RADIO_CC1101 = 1, RADIO_SX1278 = 2 };
struct CcConfig {
  uint32_t magic; uint8_t version; uint8_t mode; uint8_t raw; uint8_t radio;
  uint64_t secplus_id; uint32_t rolling; uint32_t tx_count;
  // hass: HA events-topic layout (CC_HASS_AGG/CC_HASS_DIRECT). Carved out of the trailing
  // reserved padding so sizeof(CcConfig) is unchanged and existing /cc1101.cfg files
  // (whose pad was zeroed at save) load unchanged with hass = 0 = CC_HASS_AGG — no version bump.
  double secplus_freq[3]; uint8_t secplus_nfreq; uint8_t hass;
  // Power control (0 = use the preset default). cc_tx_pa -> CC1101 PATABLE[1] (the OOK mark level);
  // cc_rx_agc -> CC1101 AGCCTRL2 (0x1B); sx_tx_pa -> SX1278 RegPaConfig; sx_rx_lna ->
  // SX1278 RegLna (nonzero also switches RX off AGC-auto). Carved from pad, no version bump.
  uint8_t cc_tx_pa; uint8_t cc_rx_agc; uint8_t sx_tx_pa; uint8_t sx_rx_lna;
  // hass_nodisc: HA MQTT Discovery publisher. 0 = ENABLED (default, incl. every existing
  // /cc1101.cfg whose pad loaded as 0), nonzero = disabled. Inverted so on-by-default needs no
  // version bump. Carved from pad2, so sizeof(CcConfig) is unchanged. See CmndCcHassDisc.
  uint8_t hass_nodisc; uint8_t pad2[1];
};
static CcConfig CcCfg;

static void CcCfgDefaults(void) {
  memset(&CcCfg, 0, sizeof CcCfg);
  CcCfg.magic = CC_CFG_MAGIC; CcCfg.version = 1; CcCfg.mode = CC_MODE_REMOTES; CcCfg.radio = RADIO_AUTO;
  CcCfg.secplus_freq[0] = 433.92; CcCfg.secplus_nfreq = 1;
}
static void CcCfgLoad(void) {
  CcCfgDefaults();
#ifdef USE_UFILESYS
  CcConfig tmp;
  // TfsLoadFile() clamps the read length to the file size and still returns true, so a
  // truncated file would leave the tail of tmp as stack garbage. Require an exact-size file.
  if (TfsFileExists(CC_CFG_FILE) && TfsFileSize(CC_CFG_FILE) == sizeof tmp &&
      TfsLoadFile(CC_CFG_FILE, (uint8_t*)&tmp, sizeof tmp) && tmp.magic == CC_CFG_MAGIC && tmp.version == 1) {
    CcCfg = tmp;
    if (CcCfg.secplus_nfreq > 3) CcCfg.secplus_nfreq = 3;   // clamp: an exact-size but corrupt file could OOB-read secplus_freq[]
  }
#endif
}
static void CcCfgSave(void) {
#ifdef USE_UFILESYS
  if (!TfsSaveFile(CC_CFG_FILE, (const uint8_t*)&CcCfg, sizeof CcCfg)) { AddLog(LOG_LEVEL_ERROR, PSTR(CC_LOGPFX "cfg save failed")); }
#endif
}

/* ---------- SPI bus (chip-agnostic; shared by CC1101 and SX1278) ---------- */
class ArduinoSpiBus : public SpiBus {
 public:
  void begin(int cs) { cs_ = cs; pinMode(cs_, OUTPUT); digitalWrite(cs_, HIGH); }
  void select() override {
    SPI.beginTransaction(SPISettings(1000000, MSBFIRST, SPI_MODE0));
    digitalWrite(cs_, LOW);
    // No CHIP_RDYn/MISO wait here — that is CC1101-specific (it would hang an SX1278, which
    // shares this bus). The CC1101 chip-ready hand-shake now lives in CC1101Radio::reset().
  }
  void deselect() override { digitalWrite(cs_, HIGH); SPI.endTransaction(); }
  uint8_t transfer(uint8_t b) override { return SPI.transfer(b); }
  void delay_ms(uint32_t ms) override { delay(ms); }
  uint32_t millis() override { return ::millis(); }
 private:
  int cs_ = -1;
};

/* Active-low RST line for the SX1278 (drives a GPIO). */
class ArduinoResetLine : public Sx1278ResetLine {
 public:
  void begin(int pin) { pin_ = pin; }
  void set(bool high) override { digitalWrite(pin_, high ? HIGH : LOW); }
 private:
  int pin_ = -1;
};

/* ---------- per-board pin maps (VERIFIED) ----------
 * The adapter routes SPI + control lines differently per module. Radio selection (below)
 * SPI-probes these maps for a CC1101, or uses the RA-02 map for an SX1278. GPIO5 is the
 * board-type strap (float = CC1101, tied low = SX1278) and is NOT used by any map. */
struct CcPins { int8_t sck, miso, mosi, cs, gdo0, gdo2; };
struct SxPins { int8_t sck, miso, mosi, nss, rst, dio0; };
static constexpr CcPins CC_MAP_BLUE  = { 3, 7, 4, 1, 10, 6 };   // blue E07:    SCK3 MISO7 MOSI4 CSN1  GDO0=10 GDO2=6  (CSN moved 9->1: GPIO9 is BOOT strap)
static constexpr CcPins CC_MAP_GREEN = { 1, 3, 10, 6, 7, 4 };   // green D-Sun: SCK1 MISO3 MOSI10 CSN6 GDO0=7  GDO2=4  (SCK moved 9->1: GPIO9 is BOOT strap)
static constexpr SxPins SX_MAP_RA02  = { 3, 7, 4, 1, 10, 6 };   // RA-02:       SCK3 MISO7 MOSI4 NSS1  RST=10  DIO0=6  (NSS moved 9->1: GPIO9 is BOOT strap)
#define CC_STRAP_PIN 5
/* Boot-strap safety -- ROOT CAUSE CONFIRMED 2026-09-06 (see firmware/docs/bootloader-recovery.md).
 * GPIO2/8/9 are ESP32-C3 strapping pins sampled by the mask ROM at reset; GPIO9 is BOOT. The
 * original socket adapter put the position-4 SPI signal (CC1101 CSN / green SCK / RA-02 NSS) on
 * GPIO9. At reset the ESP drives nothing, so GPIO9 rises only through its ~45k internal pull-up;
 * the radio's input capacitance on that net slows the rise enough that GPIO9 is still below V_IH
 * when the ROM samples the strap -> the ROM enters USB download mode and NEVER runs the app (no
 * timeout). That -- not a power-cut brick -- is why the radio nodes were dark. Verified on node
 * 4F:D8: with FORCE_DOWNLOAD_BOOT=0 and BOOT released it resets to boot:0x5 DOWNLOAD every time,
 * while a radio-less board resets to boot:0xd SPI_FAST_FLASH_BOOT. (An earlier claim that GPIO9
 * was safe because the driver only drives it at FUNC_INIT was WRONG: the ROM samples it long
 * before any code runs.) Fix (adapter rev): position-4 moved off GPIO9 to GPIO1 (non-strap),
 * plus optional strap pull-up footprints on the adapter. Firmware must keep every radio signal
 * off GPIO2/8/9 -- enforced at compile time below. */
static constexpr bool cc_no_strap(const CcPins& p) {
  const int8_t a[] = { p.sck, p.miso, p.mosi, p.cs, p.gdo0, p.gdo2 };
  for (int8_t v : a) { if (v == 2 || v == 8 || v == 9) return false; }
  return true;
}
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

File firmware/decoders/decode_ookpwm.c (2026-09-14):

/* SPDX-License-Identifier: Apache-2.0 */
#include "decode_common.h"
#include "decode_ookpwm.h"

typedef struct {
    const char *family;
    uint32_t short_us, long_us;   /* nominal mark widths */
    uint32_t reset_us;            /* a space >= this ends the packet */
} pwm_family_t;

/* Timings from protocols/ook-pwm-remotes.md (rtl_433 flex specs s/l/r).
 * Best-match by relative error (lowest score); table order does not matter
 * except on an exact score tie, which resolves in table order. */
static const pwm_family_t FAMILIES[] = {
    {"standard",     200,  730, 2500},   /* grey power remotes s=200 l=730 r=7300; doorbell s=208 l=724 */
    {"fixed-period", 340, 1000, 1012},   /* bed remote s=340 l=1000 r=1012 */
};
#define NFAM (sizeof(FAMILIES) / sizeof(FAMILIES[0]))

static int within(uint32_t v, uint32_t nominal, uint32_t pct)
{
    uint32_t tol = nominal * pct / 100;
    return v + tol >= nominal && v <= nominal + tol;
}

/* Try to decode one packet starting at mark index i (even) with one family.
 * On success fills bits/nbits, stats, and sets *end to the index after the packet. */
static int try_family(const pwm_family_t *f, const uint32_t *us, size_t n, size_t i,
                      uint8_t *bits, int *nbits, uint32_t *sh, uint32_t *lo, uint32_t *gap, size_t *end)
{
    uint32_t mid = (f->short_us + f->long_us) / 2;
    uint32_t sum_s = 0, cnt_s = 0, sum_l = 0, cnt_l = 0;
    int nb = 0;
    size_t k = i;
    while (k < n && nb < OOKPWM_MAX_BITS) {
        uint32_t mark = us[k];
        if (!within(mark, f->short_us, 45) && !within(mark, f->long_us, 35)) break; /* not ours */
        int is_long = mark > mid;
        if (is_long) { sum_l += mark; cnt_l++; } else { sum_s += mark; cnt_s++; }
        bits[nb++] = (uint8_t)(is_long == OOKPWM_LONG_IS_ONE);
        k++;                                            /* space (may be missing at the very end) */
        uint32_t space = (k < n) ? us[k] : f->reset_us; /* missing trailing space == reset */
        k++;
        if (space >= f->reset_us) { *gap = space; break; }
    }
    /* cnt_s == 0 || cnt_l == 0 rejects packets whose marks are all-short or
     * all-long (uniform bit codes); known limitation, no local code is uniform. */
    if (nb < OOKPWM_MIN_BITS || cnt_s == 0 || cnt_l == 0) return 0;
    *nbits = nb;
    *sh = sum_s / cnt_s;
    *lo = sum_l / cnt_l;
    *end = k;
    return 1;
}

static int emit(const pwm_family_t *f, const uint8_t *bits, int nbits, uint32_t sh, uint32_t lo,
                uint32_t gap, char *json, size_t json_len)
{
    int pad = (4 - nbits % 4) % 4;
    int digits = (nbits + pad) / 4;
    char code[OOKPWM_MAX_BITS / 4 + 2];
    int ci = 0;
    for (int d = 0; d < digits; ++d) {
        int v = 0;
        for (int b = 0; b < 4; ++b) {
            int idx = d * 4 + b;
            v = (v << 1) | (idx < nbits ? bits[idx] : 0);
        }
        code[ci++] = "0123456789abcdef"[v];
    }
    code[ci] = 0;
    int len = rf_json_append(json, json_len, 0,
        "{\"model\":\"OOK-PWM\",\"family\":\"%s\",\"bits\":%d,\"code\":\"%s\",\"short_us\":%u,\"long_us\":%u,\"gap_us\":%u}",
        f->family, nbits, code, (unsigned)sh, (unsigned)lo, (unsigned)gap);
    return len < 0 ? RF_DECODE_TRUNCATED : RF_DECODE_OK;
}

int ookpwm_decode(const uint32_t *us, size_t n, size_t *pos, char *json, size_t json_len)
{
    size_t i = *pos;
    if (i & 1) i++;                                   /* always start on a mark */
    while (i < n) {
        int best_fi = -1;
        uint32_t best_score = (uint32_t)-1;
        uint8_t best_bits[OOKPWM_MAX_BITS];
        int best_nbits = 0;
        uint32_t best_sh = 0, best_lo = 0, best_gap = 0;
        size_t best_end = i;

        for (size_t fi = 0; fi < NFAM; ++fi) {
            uint8_t bits[OOKPWM_MAX_BITS];
            int nbits = 0;
            uint32_t sh = 0, lo = 0, gap = 0;
            size_t end = i;
            if (try_family(&FAMILIES[fi], us, n, i, bits, &nbits, &sh, &lo, &gap, &end)) {
                /* Calculate score: relative error sum for short and long marks */
                uint32_t score = (sh > FAMILIES[fi].short_us ? sh - FAMILIES[fi].short_us : FAMILIES[fi].short_us - sh) * 1000 / FAMILIES[fi].short_us
                               + (lo > FAMILIES[fi].long_us ? lo - FAMILIES[fi].long_us : FAMILIES[fi].long_us - lo) * 1000 / FAMILIES[fi].long_us;
                if (score < best_score) {
                    best_score = score;
                    best_fi = (int)fi;
                    best_nbits = nbits;
                    best_sh = sh;
                    best_lo = lo;
                    best_gap = gap;
                    best_end = end;
                    for (int bi = 0; bi < nbits; ++bi) {
                        best_bits[bi] = bits[bi];
                    }
                }
            }
        }

        if (best_fi >= 0) {
            *pos = best_end;
            return emit(&FAMILIES[best_fi], best_bits, best_nbits, best_sh, best_lo, best_gap, json, json_len);
        }

        i += 2;                                       /* slide to the next mark */
    }
    *pos = n;
    return RF_DECODE_NONE;
}

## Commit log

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2026-09-03 Add generated ESP32-C3 SuperMini form-factor KiCad project
    Output of scripts/generate_supermini.py. Verified with KiCad 9.0.7:
    ERC has no errors and DRC (with schematic parity) reports no
    violations.
    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
    [esp32-c3-supermini.kicad_pcb, esp32-c3-supermini.kicad_sch]
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2026-09-03 SX1278 module: correct pad layout and pin names from the pinout photo
    The seller's dimensioned pinout photo shows 12 keyhole pads along one
    edge, two small castellation-only notches (DIO4, DIO5) on the adjacent
    edge at the shared corner, and two keyhole pads (ANT, GND) at the
    opposite corner. Pin names in physical order are GND DIO1 DIO2 DIO3
    VCC MISO MOSI SCK NSS DIO0 REST GND, DIO4 DIO5, GND ANT; the seller's
    table duplicated REST and shifted its tail. Positions re-measured
    from the top-down photo: row holes 1.2 mm in from the edge starting
    1.2 mm from the corner, notches at 1.25/2.7 mm, ANT/GND at 1.4/2.8 mm.
    Claude-Session: http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
    [sx1278-lora-module.kicad_pcb, sx1278-lora-module.kicad_sch]
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2026-09-03 Add ESP32-C3 SuperMini to SX1278 and CC1101 adapter boards
    Two 24 mm wide carriers generated by scripts/generate_adapters.py:
    one seats a SuperMini and the 16-pin castellated SX1278 module on SMD
    land pads with a spring-antenna hole, the other seats a SuperMini and a
    2x4 socket for the E07-M1101D CC1101 board. Both share one GPIO map
    (MOSI 5, SCK 6, CS 7, MISO 4, IRQ 10, IRQ2 3, RESET 8) chosen to avoid
    strapping pins on radio outputs and to route planar; hand-routed with
    signals on F.Cu, power on B.Cu and vias to the SMD pads. ERC and DRC
    clean; renders added.
    Claude-Session: https://claude.ai/code/session_01JoGdh4Cg3VtTTDZi4gQuiN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
    [esp32c3-cc1101-adapter.kicad_pcb, esp32c3-cc1101-adapter.kicad_sch, esp32c3-sx1278-adapter.kicad_pcb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]
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2026-09-03 Rework the CC1101 adapter: castellated keyhole pads, corner holes, two-sided silk
    * SuperMini pins land on keyhole pads (1.0 mm hole plus 1.6 x 3.4 mm oval
    copper reaching 1.2 mm past the SuperMini edge) so the module can be
    fitted with header pins or soldered flat by its castellations.
    * The SuperMini body now overhangs the left edge by 0.5 mm so the USB-C
    connector hangs clear of the board.
    * Four M2 mounting holes 2.4 mm in from the corners; the socket moves right
    so the plugged-in E07 board clears the bottom-left screw.
    * Silkscreen on both sides (back copy mirrored), signal names next to the
    SuperMini use the CC1101's names (GDO0, GDO2, CSN).
    * Board is 27 x 36.5 mm; all track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
    [esp32c3-cc1101-adapter.kicad_pcb, esp32c3-cc1101-adapter.kicad_sch]
2026-09-03 CC1101 adapter GND pour with antenna keepout; optional SMA on the SX1278 adapter
    * kicadgen: Zone (copper pour / keepout) support, board revision "0" in
    every title block, KICAD_SHARE overridable for non-snap installs.
    * scripts/fill_zones.py: fills zones with KiCad's own filler (pcbnew python,
    re-executed inside the snap when needed) and splices only the fill
    polygons into the generated file, so generation stays reproducible.
    * CC1101 adapter: GND pour on F.Cu (all tracks remain on B.Cu), keepout on
    both layers under the SuperMini's ceramic antenna; MISO/GDO2 now run
    outside the SuperMini body instead of under its antenna.
    * SX1278 adapter: 24 x 58 mm, optional edge-mount SMA jack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
    [cc1101-e07-m1101d.kicad_pcb, cc1101-e07-m1101d.kicad_sch, esp32-c3-supermini.kicad_pcb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]
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2026-09-03 Take the board revision from git describe; publish packages on every push to main
    * Title blocks use the GIT_DESCRIBE text variable (project default
    "(git describe)"); verify_boards.py and export_manufacturing.py define
    it from `git describe --tags --dirty --match 'v[0-9]*'`, so the
    committed files never change with the revision.
    * Package names are <board>-<git describe>-<fab>.zip.
    * CI builds packages on every push and PR; pushes to main update the
    release of the latest version tag (renamed to the build's git describe,
    assets replaced) instead of creating tags or waiting for one.
    Claude-Session: https://claude.ai/code/sess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
    [cc1101-e07-m1101d.kicad_pcb, cc1101-e07-m1101d.kicad_sch, esp32-c3-supermini.kicad_pcb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]
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2026-09-04 Merge the two socket adapters into esp32c3-radio-adapter; two-sided pin silk on the replicas
    * esp32c3-radio-adapter replaces esp32c3-cc1101-adapter and
    esp32c3-ra02-adapter: the E07-M1101D and Ra-02 breakout headers differ
    only at outer column 3 (GDO0 / RST) and inner column 1 (GDO2 / DIO0),
    wired to GPIO10 and GPIO3, so one socket takes either board. Nets are
    named GDO0_RST, GDO2_DIO0 and CSN_NSS; the silk carries the E07 names
    with the Ra-02 names in parentheses, plus both boards' fab outlines.
    * Ra-02 breakout replica: header and module pin numbers on the back silk;
    header pin names beside each column on both sides.
    * E07-M1101D replica: pin names beside each column on both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
    [cc1101-e07-m1101d.kicad_pcb, esp32c3-cc1101-adapter.kicad_pcb, esp32c3-ra02-adapter.kicad_sch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]
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2026-09-04 SuperMini board: pin-name silk on the back as well as the front
    Every pad on the ESP32-C3 SuperMini replica now carries its printed name
    (5V, G, 3.3, 4..0 / 5..10, 20, 21) on both silk layers. The back copies
    share the front anchors and are mirrored with left/right justification
    swapped, so each still sits inboard of its own pad when read from the back.
    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
    [esp32-c3-supermini.kicad_pcb]
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2026-09-05 Adapters: reassign the GPIOs so the socket adapter routes on one layer
    The pin-header (socket) adapter is now entirely on the back copper, the
    expansion header and strap included; the front carries only pads and the
    GND pour. New assignment, shared by both adapters:
    MOSI GPIO8, SCK GPIO9, CSN/NSS GPIO0, MISO GPIO7, GDO0/RST(DIO0) GPIO10,
    GDO2/DIO0(DIO1) GPIO6, strap RADIO_ID GPIO5, SX1278 module RESET GPIO4.
    GPIO8/9 are boot strapping pins but carry only ESP32 outputs, which float
    at boot; the radio's outputs stay on plain GPIOs. On the socket adapter
    the radio signals then all leave the GPIO row, which faces the socket, in
    the order its pads want them: GDO0 and SCK drop straight in,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
    [esp32c3-radio-adapter.kicad_pcb, esp32c3-radio-adapter.kicad_sch, esp32c3-sx1278-adapter.kicad_pcb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]
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2026-09-05 Add the green D-Sun CC1101 board with the same assets as the blue E07-M1101D
    The user's second CC1101 board ("433MHz D-Sun CC1101", green; EasyEDA calls
    it RF1101SE V3.1) carries the same eight signals on the same 2x4 header,
    with the GND/VCC column in the same place but the three signal columns
    permuted, so it does not fit the socket adapter's pinout and is supported
    with jumper wires instead.
    * scripts/generate_dsun.py -> hardware/parts/cc1101-dsun: outline 14.4 x
    30, header rows 2.1 / 4.6 from the edge, columns 2.9..10.5 from the left
    long edge, two 1.8 mm holes beside the SMA jack, pin names on both sides
    and the original's back-side legend grid. Dimensions measured from the
    us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
    [cc1101-dsun-components.step, cc1101-dsun.kicad_pcb, cc1101-dsun.kicad_sch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]
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2026-09-05 firmware: add host/bench tools and capture fixtures
    tools/: the Pi-side reference CC1101 driver (cc1101.py) the firmware
    presets are proven against, GDO-pin finder, OOK capture/convert,
    per-node commissioning helper (cc1101_node.py), the rf433 aggregator
    service + example config, decode_fixture, and the wiring-diagram
    generator (esp32c3-cc1101-node-wiring.py, the single source of truth
    for the pin table). fixtures/: real RF captures (WS69 id 174) used by
    the decoder/aggregator tests, with the capture-format README.
    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
    [cc1101.py, cc1101_find_gdo_pins.py, cc1101_node.py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]
2026-09-05 firmware: add host test suite (102 tests, no ESP hardware)
    tests/ compiles the pure-C/C++ decoder and radio-logic sources into
    small host harnesses (libdecoders.so, libfirmware.so, radio_host,
    sx1278_host) and exercises them against fixtures and generated pulse
    trains: decoders (common/CRC, Fineoffset, OOK-PWM), presets vs the Pi
    cc1101.py, pulse/pulsegen, CC1101 + SX1278 fake-bus bring-up/selection,
    rcswitch round-trip, secplus2, capture conversion, the rf433 aggregator
    (dedup/echo/rf/runner), and the wiring-table check. 102 tests
    (97 CC1101 + 5 SX1278); does not exercise the Tasmota .ino glue, which
    only builds inside the full PlatformIO tree via build.py.
    Run: uv run --with pytest pytest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
    [decoderlib.py, firmwarelib.py, pulsegen.py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]
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2026-09-05 firmware: add Fine Offset WH51 soil-moisture decoder (family 0x51)
    Port the rtl_433 fineoffset.c fineoffset_WH51_callback into the pure-C
    Fineoffset decoder and dispatch family byte 0x51 to it alongside 0x24
    (WS69) and 0x85 (WS85). 14-byte FSK frame: 24-bit id, TX-period boost,
    5-bit battery (100 mV steps), moisture %, 9-bit raw AD, CRC-8 poly 0x31
    + additive checksum. Emits rtl_433-shaped JSON
    {"model":"Fineoffset-WH51","id":"0f5c54","battery_ok":..,"battery_mV":..,
    "moisture":..,"boost":..,"ad_raw":..,"mic":"CRC"}. Trailing bytes past
    the 14-byte frame are ignored so a WH51 decodes even inside a longer
    fixed-length FSK read.
    Host test uses REAL frames captured by the rpi5-433mhz reference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
    [test_wh51.py]
2026-09-05 firmware: FSK RX accepts both WS69 (25 B) and WH51 (14 B) frames
    CcWeatherPoll kept a fixed 25-byte packet tuned to WS69 and only ever
    read/decoded exactly 25 bytes, so a 14-byte WH51 frame was never
    dispatched. Handle a range of Fine Offset frame lengths:
    * full-packet path: when the 25-byte packet completes (WS69, or a WH51
    whose trailing bytes were demodulated to fill the packet), read it and
    dispatch by family byte (fineoffset_decode now handles 0x51).
    * short-frame rescue: when the RX FIFO stops growing with at least a
    whole WH51 frame present, drain and decode it -- gated to family 0x51
    so a partially-filled WS69/WS85 (which arrive in one <=12 ms burst,
    faster t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
    [xdrv_95_cc1101.ino]
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2026-09-05 cc1101-node: Fine Offset FSK RX in infinite length mode (all frame lengths)
    Fixed packet-length mode (PKTCTRL0=0x00, PKTLEN=25) only completes one frame size, so a 14-byte WH51 never finishes and is never decoded. Switch the fineoffset-fsk preset to CC1101 infinite length mode (PKTCTRL0=0x02) and drain a fixed 30 bytes (>= the longest WS85 frame) from the RX FIFO, dispatching by family byte in the decoder (0x24 WS69 / 0x51 WH51 / 0x85 WS85). One config now receives WH51 (14 B), WS69 (25 B) and WS85 (28 B).
    Framing/drain lives in new cc1101_weather.cpp (cc_weather_drain), shared with the host harness. CcWeatherPoll is now a thin caller; the old family-0x51 short-frame rescue hack and CcState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
    [xdrv_95_cc1101.ino]
2026-09-05 cc1101-node: host test for FSK RX FIFO drain + family dispatch
    radio_host gains a scripted RX FIFO and a weather_drain command that runs the real cc_weather_drain over a frame-at-head + trailing-noise FIFO. New test_weather_rx.py proves WH51 (14 B), WS69 (25 B) and WS85 (28 B) all drain and dispatch via the one path, that a partial frame stays IDLE, and that an overflowed FIFO still recovers the head frame. test_presets asserts the deliberate PKTCTRL0 divergence (0x02 infinite vs cc1101.py 0x00 fixed); every other register still matches the reference. 114 passed.
    Claude-Session: https://claude.ai/code/session_01XbaDEPHZFNvnGB3Hd1AH1e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
    [firmwarelib.py, test_presets.py, test_weather_rx.py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]
2026-09-05 cc1101-node: SX1278 (RA-02) Fine Offset FSK receive path
    Bring the SX1278 to functional parity with the CC1101 weather path: it now
    receives Fine Offset FSK weather frames (WS69 family 0x24, WH51 family 0x51,
    WS85 family 0x85), reusing the shared decoders/decode_fineoffset.c.
    SX127x FSK config (2-FSK, no shaping), cross-referenced to the proven SX1276
    receiver at Welland (rpi5 ~/wh51-watch, RadioLib beginFSK):
    carrier 433.92 MHz, bit rate 17.241 kbps (RegBitrate 0x0740), fdev ~50 kHz
    (RegFdev 0x0333), RX bandwidth 125 kHz (RegRxBw 0x02), sync 0x2DD4 (2 bytes
    after the 0xAA preamble), preamble detector on.
    Framing mirrors the CC1101 "drain a fixed count, dispatch by family" idea:
    fixe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
    [firmwarelib.py, test_sx1278_weather_rx.py, xdrv_95_cc1101.ino]
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2026-09-05 cc1101-node: cc_wrap_event guards empty decoder JSON ({}) from trailing comma
    decoder_json == "{}" (no decoder fields) previously produced
    {...,"rssi":-71,} — invalid JSON due to the trailing comma before the
    closing brace. Detect the empty-object case after stripping the leading
    '{' and skip the comma+splice in that case. Host test added
    (test_wrap_event_empty_decoder_object_is_still_valid_json).
    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
    [test_mqtt_shape.py]
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2026-09-05 cc1101-node: document strap-pin boot safety in the driver
    Record the boot-mode invariant at the pin-map block: no map touches GPIO2/GPIO8
    (strapping) or GPIO18/19 (USB D-/D+); GPIO9 (BOOT strap) is only the blue CSN or
    green SCK and is driven solely by the SPI bring-up at FUNC_INIT, long after the
    ROM sampled the straps and USB came up. CS idles HIGH (begin() + every deselect),
    so GPIO9 rests HIGH between transactions; no gpio_hold / RTC / deep-sleep hold is
    used, so no pin state persists across a reset to change boot mode, and the driver
    does no pin I/O before FUNC_INIT (no FUNC_PRE_INIT hook). Comment only, no behaviour
    change.
    Claud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
    [xdrv_95_cc1101.ino]
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2026-09-06 cc1101-node: combined safeboot+main factory image + structural test
    The node partition table already reserves a safeboot factory slot (0x10000)
    alongside app0/ota_0, but the plain .factory.bin populates only app0 and
    leaves safeboot blank -- so there is no fallback if app0 is ever bad.
    combine_safeboot.py merges the stock Tasmota safeboot image and the main
    CC1101-node firmware into one flashable factory image: bootloader +
    partition table + otadata(->ota_0) + safeboot@0x10000 + main@0xe0000. A
    single esptool write_flash 0x0 then lays down a node that self-recovers
    over WiFi (Tasmota safeboot) from a failed OTA, a corrupt app0, or an
    invalid otadata -- no BOOT button for those cases. Slot o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
    [combine_safeboot.py, test_combined_image.py]
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2026-09-06 cc1101-node: fix combine_safeboot CI portability + make test distinguishing
    Two adversarial-review findings:
    - CI Build job failed with FileNotFoundError: combine_safeboot.py read .pio
    build intermediates (partitions.bin/bootloader.bin) that exist on a warm
    local tree but NOT on a clean CI runner. Rewrite it to operate purely on
    the reliably-built dist artifacts: take the main .factory.bin (which
    Tasmota already builds WITH a safeboot slot populated) and swap in our
    locally-built tasmota32c3-safeboot.bin, reading slot offsets from the
    partition table embedded in the factory image. Byte-identical output
    (sha256 c8e22dd4...), no .pio dependency, and drops the nondeterministic
    b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
    [combine_safeboot.py, test_combined_image.py]
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2026-09-06 Socket adapter: move CSN/NSS off the GPIO9 boot strap to GPIO1
    On the bench (2026-09-06) the CC1101/Ra-02 nodes powered straight into USB
    download mode every reset and never ran the firmware. Root cause: socket
    position 4 (CSN on the blue board, SCK on the green, NSS on the Ra-02) was
    GPIO9, the ESP32-C3 BOOT strap. A radio pin loads that net with enough
    capacitance that, through the chip's weak internal pull-up, it rises too
    slowly for the mask ROM to read it high at reset, so the ROM latches BOOT low
    and enters download mode. It is not the firmware -- the ROM samples the strap
    before any code runs -- and it is not fixable in software.
    Fix, single layer as before: position 4 now takes G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
    [esp32c3-radio-adapter.kicad_pcb, esp32c3-radio-adapter.kicad_sch]
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2026-09-06 SX1278 module adapter: move NSS and RESET off the GPIO8/GPIO9 straps
    Same boot-strap hazard as the socket adapter: the module's NSS sat on GPIO9
    (the BOOT strap) and RESET on GPIO8, so at reset the module's pin capacitance
    could hold a strap low through the weak internal pull-up and drop the chip
    into USB download mode. On this two-layer board the fix keeps the nested
    front-copper left bus by shifting the chain: NSS GPIO9 -> GPIO10, DIO0
    GPIO10 -> GPIO20, RESET GPIO8 -> GPIO21, so the pad order still matches the
    pin order and no lane crosses. GPIO8 and GPIO9 are now unused. The old
    bottom-copper RESET run is removed. README and schematic note updated;
    ERC/DRC clean.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
    [esp32c3-sx1278-adapter.kicad_pcb, esp32c3-sx1278-adapter.kicad_sch]
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2026-09-06 cc1101-node: move position-4 radio signal off GPIO9 (BOOT strap) to GPIO1
    CONFIRMED root cause of the dark radio nodes: the socket adapter routed the
    position-4 SPI signal (CC1101 CSN / green SCK / RA-02 NSS) to GPIO9, the
    ESP32-C3 BOOT strapping pin. At reset the ESP drives nothing, so GPIO9 rises
    only via its ~45k internal pull-up; the radio input capacitance on that net
    slows the rise so GPIO9 is below V_IH when the mask ROM samples the strap ->
    ROM enters USB download mode and never runs the app (no timeout). Verified:
    node 4F:D8 (FORCE_DOWNLOAD_BOOT=0, BOOT released) resets to boot:0x5 DOWNLOAD
    every time; a radio-less board resets to boot:0xd and runs.
    (An earlier in-session uhubctl p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
    [xdrv_95_cc1101.ino]
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2026-09-06 cc1101: widen Fine Offset RX bandwidth to 325 kHz for crystal-offset tolerance
    The blue CC1101 node counted RX frames but decoded none (Rx>0, Decoded=0).
    Root cause: the Fine Offset FSK preset used a 101 kHz RX bandwidth
    (MDMCFG4 0xC9). Cheap 433 MHz modules carry crystal offsets up to ~+/-90 ppm;
    the blue node measured +40 kHz (~92 ppm). The CC1101 frequency-offset
    compensation only pulls in +/-BW/4, so at 101 kHz (+/-25 kHz) every real frame
    fell outside the passband and only noise false-syncs were drained.
    Fix: MDMCFG4 0xC9 -> 0x59 (325 kHz, FOC +/-81 kHz). Verified on blue's
    hardware: 10 frames decoded in 90 s across WS69 (id 174) and three WH51 soil
    probes (0f4b37, 0f5d66, 0f5d7f), byt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
    [test_presets.py]
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2026-09-08 sx1278: add Fine Offset 2-FSK packet TX engine (+host tests)
    Adds configure_fsk_tx/write_fifo/enter_tx/packet_sent/transmit_fsk to SX1278Radio:
    a fixed-length 2-FSK packet transmit matched byte-for-byte to the RX preset
    (433.92 MHz, 17.241 kbps, ~50 kHz fdev, 0xAA preamble + 0x2DD4 sync) so a peer
    node running configure_fineoffset_fsk() decodes the frame. PA on PA_BOOST (+17 dBm),
    TxStartCondition=FifoNotEmpty, PacketSent-polled with timeout.
    OOK TX is intentionally NOT added: OOK needs the SX1278 continuous-mode DATA line
    (DIO2), which the RA-02 socket does not route (SX_MAP_RA02 wires only DIO0). FSK
    packet TX drives the FIFO over SPI, so it works on the wiring as built.
    Also corrects a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
    [test_sx1278_fake_bus.py]
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2026-09-08 fix: CcTxPower must set the OOK mark level PATABLE[1], not PATABLE[0]
    Adversarial review caught a ship-blocker. CC1101 ASK/OOK keys the PA between
    PATABLE[0] (space, kept 0x00) and PATABLE[PA_POWER]=PATABLE[1] (mark); the OOK TX
    presets set FREND0=0x11 (PA_POWER=1) and load {0x00,0xC0}. CcTxPower was writing
    index 0, so any nonzero value made PATABLE {v,0xC0} -> near-zero modulation depth
    -> an undecodable continuous carrier (and never changed the mark power). This
    corrupted OOK TX for CcRfSend and SecplusSend, and explains why on-air OOK capture
    tests decoded nothing. Write index 1 (mark), keep index 0 = 0x00.
    [xdrv_95_cc1101.ino]
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2026-09-08 fix: three driver bugs from the full-driver adversarial review
    - CcCapturePoll: sample the idle-flush timestamp AFTER draining the edge ring, so
    an edge that fires mid-drain (later than a pre-loop sample) cannot wrap the
    unsigned subtraction and spuriously truncate an in-progress OOK frame.
    - CcCfgLoad: clamp secplus_nfreq to <=3 after loading, so an exact-size but
    corrupt /cc1101.cfg cannot OOB-read secplus_freq[] and TX on a garbage frequency.
    - CC1101 wait_tx_done: treat MARC_TXFIFO_UNDERFLOW (0x16) as an error + SFTX,
    instead of reporting a starved transmit as success.
    All low-severity/latent; 138 host tests pass, firmware builds.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
    [xdrv_95_cc1101.ino]
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2026-09-08 feat(hass): self-publish HA MQTT Discovery for decoded weather/moisture
    The node now publishes retained per-field state + homeassistant/sensor/.../config so Home Assistant creates the weather/moisture entities natively, with no rtl_433 add-on/aggregator. Config is emitted once per (model,id) per boot, gated on MqttIsConnected() so the first decode (which races WiFi/MQTT bring-up on boot) does not drop the retained config. Adds a CcHassDisc command (on by default) and a HassDisc field in CcStatus. Verified on real hardware: HA auto-created 10 Fine Offset entities (WS69 temp/humidity/wind/rain + two WH51 moisture/battery) on the real ha.welland broker.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
    [xdrv_95_cc1101.ino]
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2026-09-08 fix(hass): FIFO-evict the discovery seen-table; expose battery_ok
    Two adversarial-review findings: (1) the once-per-boot dedup table (now 16 slots) had no eviction, so a 17th+ distinct sensor re-published its retained config on every frame forever — now FIFO-evicts the oldest so each new sensor publishes config once. (2) WS69/WH65B emit only battery_ok (no battery_mV/pct), so a WS69 previously got no battery entity; battery_ok is added to the field table as a plain numeric sensor (0/1 on WS69, 0.0-1.0 on WH51). +1 host test (146 total).
    [test_hass.py, xdrv_95_cc1101.ino]
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2026-09-08 fix(radio): tear down the other radio on runtime Radio switch; SX counters in SENSOR
    Adversarial-review findings on the radio dispatch:
    (1) switching Radio cc1101<->sx1278 at runtime left the other engine live —
    CcSx1278BringUp did not CcCaptureStop()/clear Cc.present (so telemetry/status/reg
    SPI kept reaching the now-different chip on the shared bus), and CcCc1101BringUp
    did not standby the SX. Both now tear the other side down.
    (2) CcShowJson (tele/SENSOR) only ever emitted a CC1101 block, so an SX-only node
    never reported its Rx/Decoded to HA; added an SX1278 branch.
    (3) fixed a stale struct comment (cc_tx_pa targets PATABLE[1], the OOK mark, not [0]).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
    [xdrv_95_cc1101.ino]
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2026-09-08 tools: add validated Pluto WH51 narrowband channelizer for the (b) cross-check
    The Pluto real-sensor cross-check needs a byte-level WH51 decode from the Pluto
    IQ. rtl_433's live plutosdr stream is broken on that host and rtl_433 offline
    cannot slice the FSK in the congested 2 MHz capture (100+ overlapping signals),
    so this adds a narrowband software receiver that channelizes to one ~60-100 kHz
    channel (mix->DC, low-pass, decimate) and FSK-demodulates — exactly what the
    narrowband CC1101 does when it decodes these fine.
    Memory-safe (streams the cs16 in chunks with stateful FIR decimation, so it will
    not OOM a host; run it on desktop.buddy per the repo's intensive-ops rule). The
    FSK slicer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
    [pluto_wh51_channelize.py]
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
